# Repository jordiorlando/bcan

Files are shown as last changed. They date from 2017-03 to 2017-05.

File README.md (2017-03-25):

# bcan
### Beacon Controlled Autonomous Network

This project aims to create a semi-autonomous model train capable of detecting and avoiding obstacles. It makes use of small IR beacons placed between the rails to transmit a unique ID that can be mapped to various train functions, such as speed or lighting.

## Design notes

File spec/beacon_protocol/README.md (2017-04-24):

# Beacon IR Protocol
The beacon IR protocol is modulated with a carrier frequency of 38kHz. One bit length is defined as 960us, or roughly 36.5 oscillations of the carrier frequency. Each frame starts with a high signal for three bit lengths followed by a low signal for one bit length. The frame's data payload then begins, and has a nominal length of 16 bits. Each bit is represented using manchester encoding as per G.E. Thomas' convention. That is, a logical zero is represented by a low signal for 480us followed by a high signal for 480us, equivalent to a rising edge at the center of the bit length. A logical one is represented by a high signal for 480us followed by a low signal for 480us, equivalent to a falling edge at the center of the bit length. The frame ends with a low signal for four bit lengths, upon which a new frame may begin.

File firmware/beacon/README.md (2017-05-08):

# Beacon Firmware
This firmware is responsible for continuously broadcasting a unique ID via a modulated IR LED.

## Prerequisites
-   avr-gcc
-   avr-libc
-   avrdude

## Building
Build the firmware into an Intel hex file. The ID should be a 4-digit hexadecimal number.
```sh
$ make clean
$ make all ID=0xbcaf
```

## Flashing
Flash the Intel hex file using avrdude.
```sh
$ make program
```

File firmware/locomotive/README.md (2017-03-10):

# Locomotive Firmware
This firmware is responsible for controlling every aspect of the locomotive

## Prerequisites
- arm-none-eabi-gcc
- arm-none-eabi-newlib
- openocd

## Building
Build the firmware.
```sh
$ make
```

## Flashing
Build and flash the firmware.
```sh
$ make flash
```

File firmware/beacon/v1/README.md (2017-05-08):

# Beacon Firmware
This firmware is responsible for continuously broadcasting a unique ID via a modulated IR LED.

## Prerequisites
-   avr-gcc
-   avr-libc
-   avrdude

## One-Time Setup
Burn fuses to not divide the internal oscillator by 8. Values obtained via [Engbedded Fuse Calculator](http://www.engbedded.com/fusecalc/).
```sh
$ make fuses
```

## Building
Build the firmware into an Intel hex file. The ID should be a 4-digit hexadecimal number.
```sh
$ make clean
$ make all ID=0xbcaf
```

## Flashing
Flash the Intel hex file using avrdude.
```sh
$ make program
```

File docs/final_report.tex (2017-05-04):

%%%%%%%%%%%%%%%%%%%%%%%%%%%%%%%%%%%%%%%%%%%%%%%%%%%%%%%%%%%%%
% ECE 445 final paper LaTeX template
% Written by Zhangxiaowen (Andy) Gong
% Created: 03/07/2012
% Last modified: 03/13/2012
%%%%%%%%%%%%%%%%%%%%%%%%%%%%%%%%%%%%%%%%%%%%%%%%%%%%%%%%%%%%%
\documentclass[openbib,letterpaper,10pt]{article}

%%%%%%%%%%%%%%%%%%%%%%%%%%%%%%%%%%%%%%%%%%%%%%%%%%%%%%%%%%%%%
% The preamble starts here.
% You can add other packages that you want to use by using
% \usepackage command in the preamble.
% However, DO NOT change the settings that are already placed
% below unless you really know what you are doing.
%%%%%%%%%%%%%%%%%%%%%%%%%%%%%%%%%%%%%%%%%%%%%%%%%%%%%%%%%%%%%

% some commonly used packages
\usepackage{graphicx}
\usepackage{amsmath}
\usepackage{amsthm}
\usepackage{amsfonts}
\usepackage{setspace}
\usepackage{longtable}
\usepackage{url}
\usepackage{float}
\usepackage{caption}
\usepackage[colorlinks=true,linkcolor=black,citecolor=black]{hyperref}
\usepackage[top=1in, bottom=1in, left=1in, right=1in]{geometry}% set the page margins to 1 inch
\usepackage{siunitx}

% use the fancyhdr package to maintain the format of the page numbers,
% which is useful when the text color is changed
\usepackage{fancyhdr}
\fancyhf{}
\renewcommand{\headrulewidth}{0pt}
\renewcommand{\footrulewidth}{0pt}
\fancyfoot[C]{\textcolor{black}{\thepage}}

% paralist provides extended list environments
\usepackage{paralist}
\setlength{\plitemsep}{0pt}

% define the color for section and subsection titles
\usepackage{xcolor}
\definecolor{titlecolor}{RGB}{31,73,125}
\definecolor{subtitlecolor}{RGB}{79,129,189}

% tikz/pgf environment for making graphs
\usepackage{tikz}
\usepackage{tikz-timing}[2009/12/09]
\usetikzlibrary{shapes,arrows}
\usetikztiminglibrary[new={char=Q,reset char=R}]{counters}

% change the style of the abstract environment
\usepackage{abstract}
\setlength{\absparsep}{6pt}
\setlength{\absleftindent}{0pt}
\setlength{\absrightindent}{0pt}
\setlength{\abstitleskip}{-18pt}
\renewcommand{\absnamepos}{flushleft}
\renewcommand{\abstractnamefont}{\normalfont\Large\singlespacing\bfseries}
\renewcommand{\abstractname}{\textcolor{titlecolor}{Abstract}}

% change the style of the section and subsection titles
\usepackage{titlesec}
\titleformat{\section}{\color{titlecolor}\Large\bf}{\color{titlecolor}\thesection}{0.8em}{}
\titleformat{\subsection}{\color{subtitlecolor}\large\bf}{\color{subtitlecolor}\thesubsection}{1em}{}
\titleformat{\subsubsection}{\color{subtitlecolor}\normalsize\bf}{\color{subtitlecolor}\thesubsubsection}{1.2em}{}
\titlespacing{\section}{0pt}{0em}{0em}
\titlespacing{\subsection}{0pt}{0em}{0em}
\titlespacing{\subsubsection}{0pt}{0em}{0em}

% change the style of the table of contents
\usepackage{titletoc}
\titlecontents{section}[1.5em]{}{\contentslabel{1.5em}}{\hspace*{-1.5em}}{\titlerule*[0.5pc]{.}\contentspage}
\titlecontents{subsection}[3em]{}{\contentslabel{2.1em}}{\hspace*{-2.1em}}{\titlerule*[0.5pc]{.}\contentspage}
\titlecontents{subsubsection}[5.1em]{}{\contentslabel{2.7em}}{\hspace*{-2.7em}}{\titlerule*[0.5pc]{.}\contentspage}

% command for centering texts in a fixed width table cell
\newcommand{\centpcol}{\leftskip\fill \rightskip\fill}

% command for setting the style of the appendix titles
\newcommand{\setappenstyle}{
	\titleformat{\section}{\color{titlecolor}\Large\bf}{\color{titlecolor}Appendix \Alph{section}}{0.8em}{}
	\titlecontents{section}[0em]{}{Appendix \thecontentslabel \hspace{1em}}{}{\titlerule*[0.5pc]{.}\contentspage}
}

% define the style of the title of the paper
\newcommand{\thetitle}[1]{\title{\begin{Huge}{\bf #1}\end{Huge} \color{subtitlecolor}\rule[25pt]{\textwidth}{1pt}}}

% define the style of the author
\newcommand{\theauthor}[3]{
	\author{\vspace{0.5in}\\
	\textcolor{black}{By}\\
	#1
	\vspace{0.8in}\\
	\textcolor{black}{Final Report for ECE 445, Senior Design,} #2\\
	\textcolor{black}{TA:} #3
	\vspace{0.3in}}
}

% define the style of figure's caption
\newcommand{\figcap}[1]{
	\captionsetup{format=plain,font={small,color=subtitlecolor,singlespacing},margin={0pt,0pt}}
	\caption{\textcolor{subtitlecolor}{#1}}
	\vspace{-5pt}
}

% define the style of table's caption
\newcommand{\tablecap}[1]{
	\captionsetup{format=plain,font={bf,normalsize,singlespacing,color=black},margin={0pt,0pt}}
	\caption{\textcolor{black}{#1}}
	\vspace{-5pt}
}

% define the style of the abstract's page number
\newcommand{\abstractsetting}{
	\pagenumbering{roman}
	\thispagestyle{fancy}
}

\newcommand{\buildtoc}{
	\clearpage
	\singlespacing
	\tableofcontents
	\clearpage
	\onehalfspacing
	\setcounter{page}{1}
	\pagenumbering{arabic}
}

% set indentations and the space between paragraghs
\setlength{\parindent}{0pt}
\setlength{\parskip}{8pt}

%%%%%%%%%%%%%%%%%%%%%%%%%%%%%%%%%%%%%%%%%%%%%%%%%%%%%%%%%%%%%
% The preamble ends here.
%%%%%%%%%%%%%%%%%%%%%%%%%%%%%%%%%%%%%%%%%%%%%%%%%%%%%%%%%%%%%

\begin{document}

% don't change these
\pagestyle{empty}
\doublespacing

% put the title of your project here. DO NOT include the brackets.
\thetitle{Beacon-Controlled Autonomous Network for Trains (BCAN'T)}

% put your names here. seperate by \\. DO NOT include the brackets.
\theauthor{
	Susan Chen\\
	Prithvi Garimalla\\
	Jordi Pakey-Rodriguez
}
{ % put the semester info here. DO NOT include the brackets.
	Spring 2017
}
{ % put your TA's name here. DO NOT include the brackets.
	Jacob Bryan
}

% put the date and project number here. DO NOT include the brackets.
\date{
03 May 2017\\
Project No. 5
\clearpage
}

% don't change these
\maketitle
\pagestyle{fancy}
\begin{spacing}{1.15}

% put the abstract here
\begin{abstract}
BCAN'T is a system for model trains that consists of infrared beacons and a laser time-of-flight sensor in order to enable true “set and go” operation. Over the course of the project we developed the beacon reading system and it demonstrated it works, as well as a complete control system on the locomotive that interfaces the beacon and time-of-flight data to control to motor and other peripherals. Unfortunately, due to last minute hardware failures, we were unable to integrate all the components onto a locomotive, but most of the components were demonstrated to work on their own.
\abstractsetting % do not delete this line
\end{abstract}

% build the table of contents.
\buildtoc

\section{Introduction}
\subsection{Objective}
Model trains have become more and more advanced over the last few decades, but they are still controlled entirely by a human operator. These human operators are solely responsible for ensuring that no harm comes to the train. A lapse in attention can be disastrous, causing damage that could be very costly to repair. Model trains currently do not have the ability to detect obstacles or other trains in front of them. If not stopped in time a crash may occur, often resulting in derailment or physical damage. Additionally, derailment may occur when a train is traveling at high speeds on a curved tracks. The train has no recourse for these situations other than for the operator to manually slow or stop it to avoid an accident.\par

Currently, the National Model Railroad Association (NMRA) defines the Digital Command Control (DCC) standard for model trains. DCC allows for digital control of various train functions such as lights, speed, direction, sound, and much more\cite{NMRA_DCC}. One downside to DCC is that smooth operation is completely dependent on the human operator who must manually control the train as it is unable to react to its environment autonomously. In addition, DCC has a steep learning curve and setting up a system without prior experience can be quite challenging.\par

Our solution is to give each locomotive the ability to respond to the track on its own by detecting obstacles and reacting to programmable beacons placed on the track. A distance sensor is placed on the front of the train to detect obstacles directly in front of it. Small beacon modules placed on the track are set to send out unique identifiers to the train to let it know what speed it should travel at. Essentially, the end goal is to have the train sense potential issues along the track that would cause collision or derailment and act to avert such problems. Our solution is a convenient alternative to those who wish to have speed control for their locomotives. The sensors integrated with the locomotive also provide some measure of protection against human negligence by avoiding obstacles and preventing derailment.

\subsection{High-Level Requirements}
\begin{itemize}
	\item Must be able to operate indefinitely on existing methods of track power, both analog (DC) and bipolar Digital Command Control (DCC).
	\item Must be able to detect oncoming obstacles on the track and stop to avoid derailment or damage.
	\item Must be able to read customizable speed limit beacons that are powered by the tracks and adjust its speed accordingly.
\end{itemize}

\clearpage

\section{Design}
Our solution consists of two independent systems: the beacon boards and the locomotive controller. The beacons are small standalone boards on the track that continuously broadcast a unique ID that is read as the train passes over. The locomotive controller consists of three PCB's on the train and is responsible for reading beacons, identifying obstacles, and controlling the motor. The block diagram is shown in Figure 1.

\begin{figure}[H]
	\begin{center}
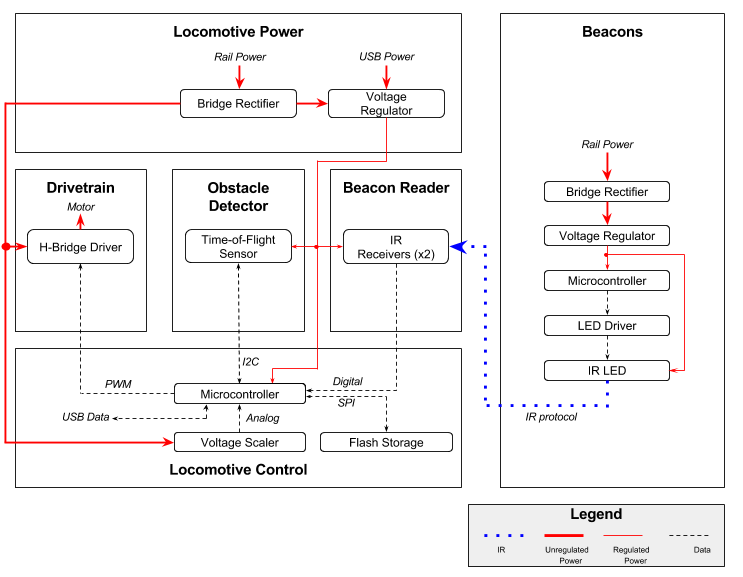
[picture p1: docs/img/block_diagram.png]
		
		\figcap{Block Diagram.}
	\end{center}
\end{figure}

\subsection{Beacon}
The beacon is small board that sits between two track ties as shown in Figure 2. The image on the left shows the placement of a beacon on the track, and the image on the right shows three individual beacons with their ID labels. Its function is to broadcast a unique ID to the IR receiver board on the locomotive. Each ID is mapped to a specific function that can be programmed on the locomotive control board. A bridge rectifier and a voltage regulator are used to provide 2.8V power to the microcontroller, LED driver, and IR LED. The microcontroller controls the IR LED to continuously broadcast the board's ID for the IR receiver on the locomotive board to read.

\begin{figure}[H]
	\begin{center}
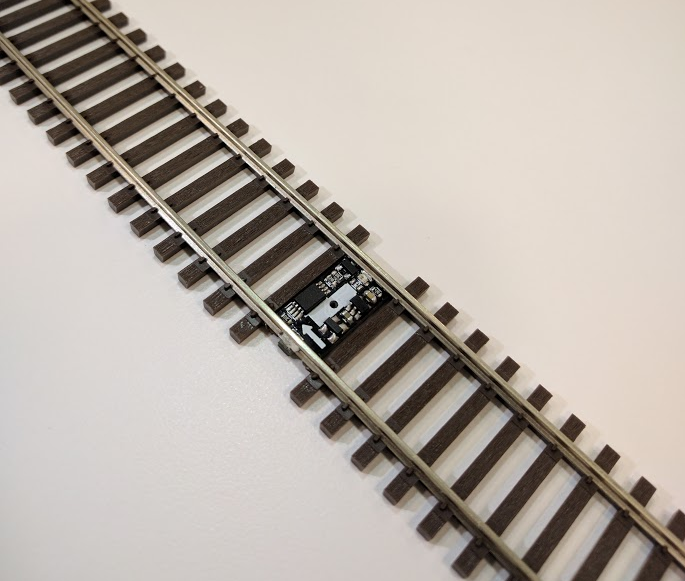
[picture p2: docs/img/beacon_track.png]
		
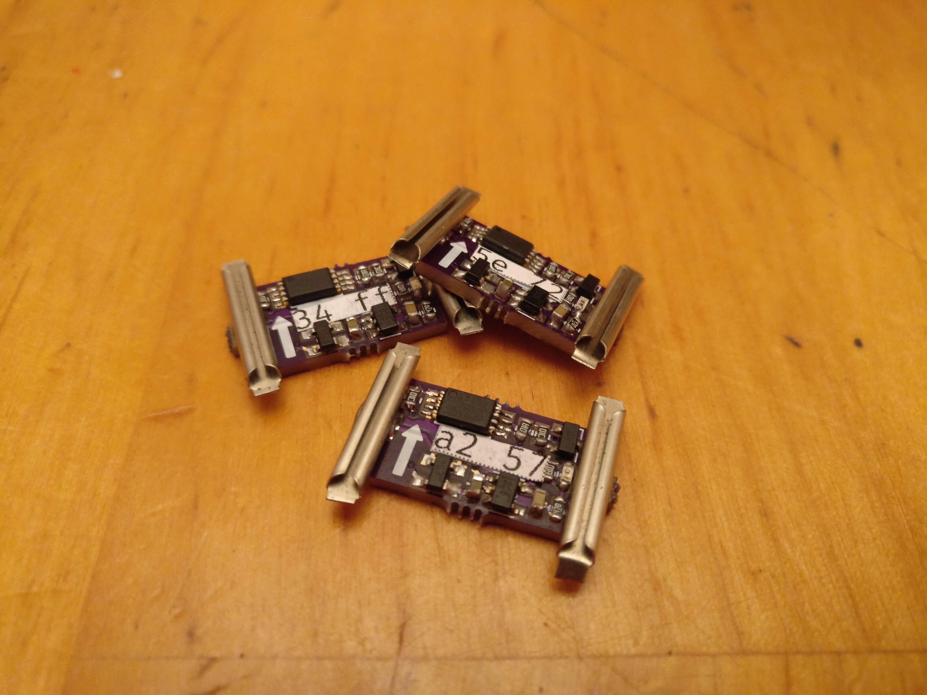
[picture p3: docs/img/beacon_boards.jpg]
		
		\figcap{Beacon Boards.}
	\end{center}
\end{figure}

\subsubsection{Schematic}
The schematics for the beacon board IR LED and power circuits are shown in Figure 3 and Figure 4, respectively. The shunt resistor R5 is used to create a clean 38kHz modulated signal since the LED is unable to switch fast enough. The calculations for R2 and R4 are shown in Calculations 1 and 2 in Appendix B.

\begin{figure}[H]
	\begin{center}
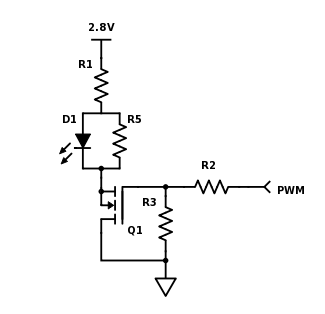
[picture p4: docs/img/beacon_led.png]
		
		\figcap{Beacon IR LED Circuit.}
	\end{center}
\end{figure}

\begin{figure}[H]
	\begin{center}
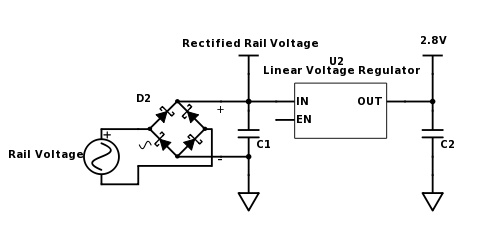
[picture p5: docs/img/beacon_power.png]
		
		\figcap{Beacon Power Circuit.}
	\end{center}
\end{figure}

\subsubsection{Bridge Rectifier}
Since the voltage regulator only takes positive voltage, the full-bridge rectifier is needed rectify the power signals from the rails. It consists of four schottky diodes in a bridge configuration and rectify rail voltages ranging from -16V to +16V.

\subsubsection{Voltage Regulator}
A linear voltage regulator takes an input from the rectified rail power and bring the voltage down to 2.8V from an input voltage of up to 16V. It provides the power needed for the MCU and its peripherals.\par

The TPS709 linear voltage regulator data sheet specifies a minimum input voltage of 2.7V\cite{TPS709}. Testing showed that an input voltage of 3.5V would produce an output voltage of 2.63V, while input voltages lower than 3.5V would produce an output voltage that is below our requirements. Therefore, a input voltage of 3.5V would be the minimum threshold for our project to function properly.

\subsubsection{Microcontroller}
The microcontroller used is an ATtiny45 8-bit AVR processor. It uses a single GPIO pin to control the LED driver circuit and continuously broadcast the board's unique ID using the IR protocol.

\subsubsection{LED Driver}
The LED driver circuit consists of an N-channel MOSFET, a gate resistor, and a pull down resistor. The MOSFET conducts current when the I/O pin from the microcontroller is set to high. The gate resistor is used to prevent damage due to overcurrent to the microcontroller and the pull down resistor is used to ensure the MOSFET is turned off when the voltage at the gate is left floating.

\subsubsection{IR LED}
The 940nm IR LED is used to broadcast a unique ID that the receiver on the locomotive can read. It is controlled by the LED driver circuit using PWM. The viewing half-angle for the LED can be calculated using Equation 1. The calculation for the viewing half angle can is shown in Calculation 3 in Appendix B.

\begin{equation}
\theta_{\frac{1}{2}}=\arctan\bigg(\frac{V_{max}T}{2H_{min}}\bigg)
\end{equation}

Vmax is the max speed of the train, T is the length of one ID message, and Hmin is the minimum distance from the beacon board LED to the IR receivers on the train.

\subsection{Locomotive Power}
The locomotive power circuit takes an input voltage ranging from -16V to +16V from the rail or 5V from the USB. It then rectifies and regulates that voltage down to 2.8V in order to power the microcontroller and its peripherals. A full bridge rectifier is used to rectify the AC voltage from the rails. The rectified voltage is then inputted to a linear voltage regulator. The SPX3918 adjustable linear voltage regulator has a minimum input voltage of 2.5V and a maximum dropout voltage of 550mV with a 500mA current draw. This means the minimum input threshold voltage in order for the locomotive components to be powered would be 3.35V, allowing for the microcontroller to be able to wait for the input voltage to reach the 3.5V minimum threshold limit for the beacon board to be powered. The circuit for the locomotive power block is shown in Figure 5.\par

Other designs were considered for the locomotive power circuit. A switching circuit to switch between the USB power source and the rail power source was considered. However, it was simpler to add a protection diode after the USB voltage source. There were also attempts to regulate the input voltage through the full range of rail voltages with switching circuits, switch-mode power supplies, or batteries. The switching circuits were complex and risked shorting the input and output voltages if the timing was not correct. There were no switch-mode power supplies on the market that had a low enough input voltage for the output that was required. Batteries would have defeated the purpose of drawing power from a wall outlet.

\subsubsection{Schematic}
\begin{figure}[H]
	\begin{center}
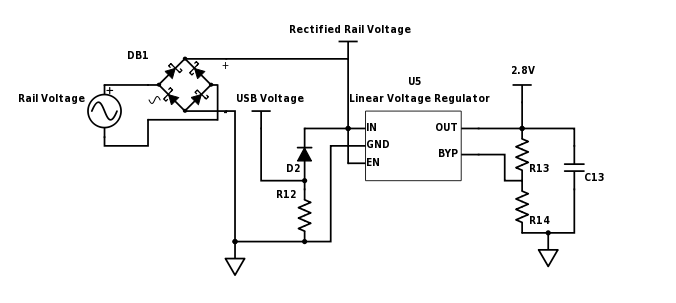
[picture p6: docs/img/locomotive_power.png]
		
		\figcap{Locomotive Power Schematic.}
	\end{center}
\end{figure}

\subsubsection{Bridge Rectifier}
The full-bridge rectifier is needed to rectify power signals from the rails before they are routed to the voltage regulator, voltage scaler, and motor driver. It consists of four schottky diodes in a bridge configuration and rectifies voltages ranging from -16V to +16V.

\subsubsection{Voltage Regulator}
The rectified voltage is fed into a linear voltage regulator in order to bring the voltage down to 2.8V. The 2.8V source is used to power the microcontroller, time-of-flight sensor, IR receiver, and the voltage scale circuit. Calculation 4 in appendix B shows how the adjustment resistors are calculated for the SPX3819 linear regulator for an output voltage of 2.8V using Equation 2.

\begin{equation}
V_{out}=1.235(1+\frac{R_1}{R_2})
\end{equation}

\subsection{Locomotive Control}
The locomotive control unit consists of a microcontroller and a USB data connection. If there is a USB connection the control unit will enter a programming mode, otherwise it will run the normal track operation. This allows operators to map the beacon IDs to one of 128 different speeds\cite{NMRA_Standard}. The microcontroller receives a voltage input via the ADC pin from the voltage scale circuit and outputs a PWM signal to the drivetrain to control the speed. The IR receiver sends beacon IDs to the microcontroller in order to determine what speed the train should go. It also stops the train if the time-of-flight sensor detects an obstacle in its path.

\subsubsection{Schematic}
The main part of the control circuit is the STM32F4 microcontroller. It is connected to a M95512-RDW6TP EEPROM for storage of the beacon mappings. The control schematic is shown in Figure 6.

\begin{figure}[H]
	\begin{center}
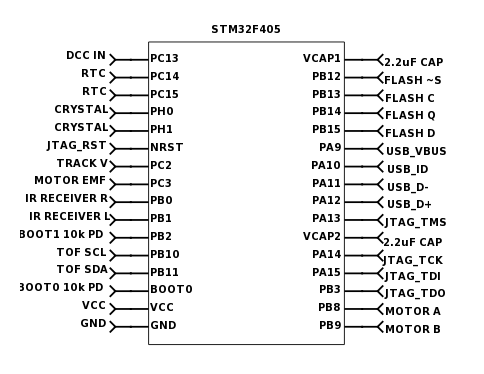
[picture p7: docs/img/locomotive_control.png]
		
		\figcap{Locomotive Control Schematic.}
	\end{center}
\end{figure}

\subsubsection{Microcontroller}
The microcontroller used is an STM32F405 32-bit ARM processor. It communicates with the time-of-flight sensor via I2C, the IR receiver digitally, and control the motor with PWM signals. It also stores configuration data for the beacons in external memory.

\subsubsection{Flash Storage}
An EEPROM flash chip is used to store the beacon mappings. It communicates with the microcontroller over SPI. EEPROM was chosen since we can address individual bytes, which makes performing binary search through the dataset for the beacon mappings more efficient.

\subsubsection{Voltage Scaler}
The voltage scaler circuit originally included an operational amplifier buffer to improve the accuracy of the voltage readings. However, we were unable to find an operation amplifier that could be powered by a 2.8V source, so errors were corrected in software instead. The voltage scaler circuit consists of a resistive voltage divider, shown in Figure 7, that scales the rectified rail voltage down to a lower voltage that can be read by the microcontroller's ADC. The rectified rail voltage ranges from 0-16V and the microcontroller ADC can read voltages from 0-2.8V. Two resistors divide the voltage to output a range of 0-2.8V, which will give 4096 different values for a 12-bit precision ADC. The calculations using Equation 3 of the voltage divider's resistor values are shown in Calculation 5 in appendix B.

\begin{figure}[H]
	\begin{center}
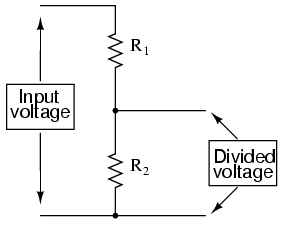
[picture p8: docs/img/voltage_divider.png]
		
		\figcap{Voltage Divider Circuit.}
	\end{center}
\end{figure}

\begin{equation}
V_{out}=V_{in}\frac{R_2}{R_1+R_2}
\end{equation}

\subsection{Locomotive Drivetrain}
The locomotive drivetrain unit consists of the motor controller circuit that interfaces the PWM signal from the microcontroller with the rectified rail power in order to power the motor. The circuit consists of a MOSFET H-bridge that is gate-driven by NPN transistors. The drivetrain circuit is shown in Figure 8.\par

In order to drive the MOSFETs in the H-bridge, optoisolators were also considered. However, we were unable to find an optoisolator that would support driving the LED with our maximum rectified rail voltage.

\subsubsection{Schematic}
\begin{figure}[H]
	\begin{center}
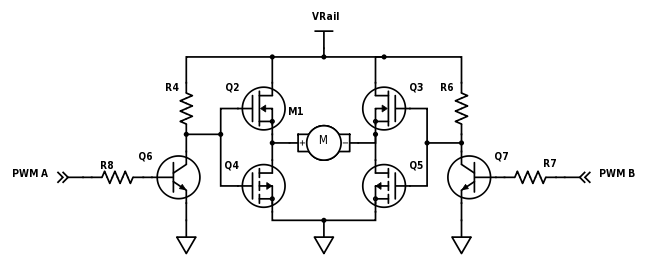
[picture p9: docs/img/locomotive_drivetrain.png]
		
		\figcap{Locomotive Drivetrain Schematic.}
	\end{center}
\end{figure}

\subsubsection{Motor Controller}
The motor driver circuit consists of two PWM signals driving two NPN transistors which each control an NFET and a PFET. The MOSFETs are configured as an H-bridge and allow the motor to run forwards or backwards at any speed determined by the PWM signals. The frequency of the PWM signals is 10kHz to prevent resonance and noise. The motor current range is $\pm$1.5A and the motor voltage range is $\pm$16V.

\subsection{Obstacle Detector}
The obstacle detector consists of a time of flight (TOF) sensor mounted to the front of the train. It detects any obstruction on the tracks that could cause the train to derail and cause an emergency stop. The TOF sensor uses a laser to measure whether the path in front of the train is clear or if the train is approaching an unexpected obstacle. The range of the TOF sensor is approximately 50-200mm\cite{VL6180X}.

\subsection{Beacon Reader}
The beacon reader consists of two IR receivers mounted underneath the train on either side. They read beacons as the train passes over them. With two receivers, the microcontroller can infer the direction the train is moving and execute different actions accordingly.

\subsection{IR Protocol}
The IR protocol uses 38kHz modulation present in many televisions and other consumer devices. We chose this frequency because sensors for it are widely available. Our protocol uses Manchester encoding according to the G.E. Thomas convention with a bit period of 960s and data length of 16 bits\cite{Manchester}. The timing diagram for the protocol is shown in Figure 9.

\begin{figure}[H]
	\begin{center}
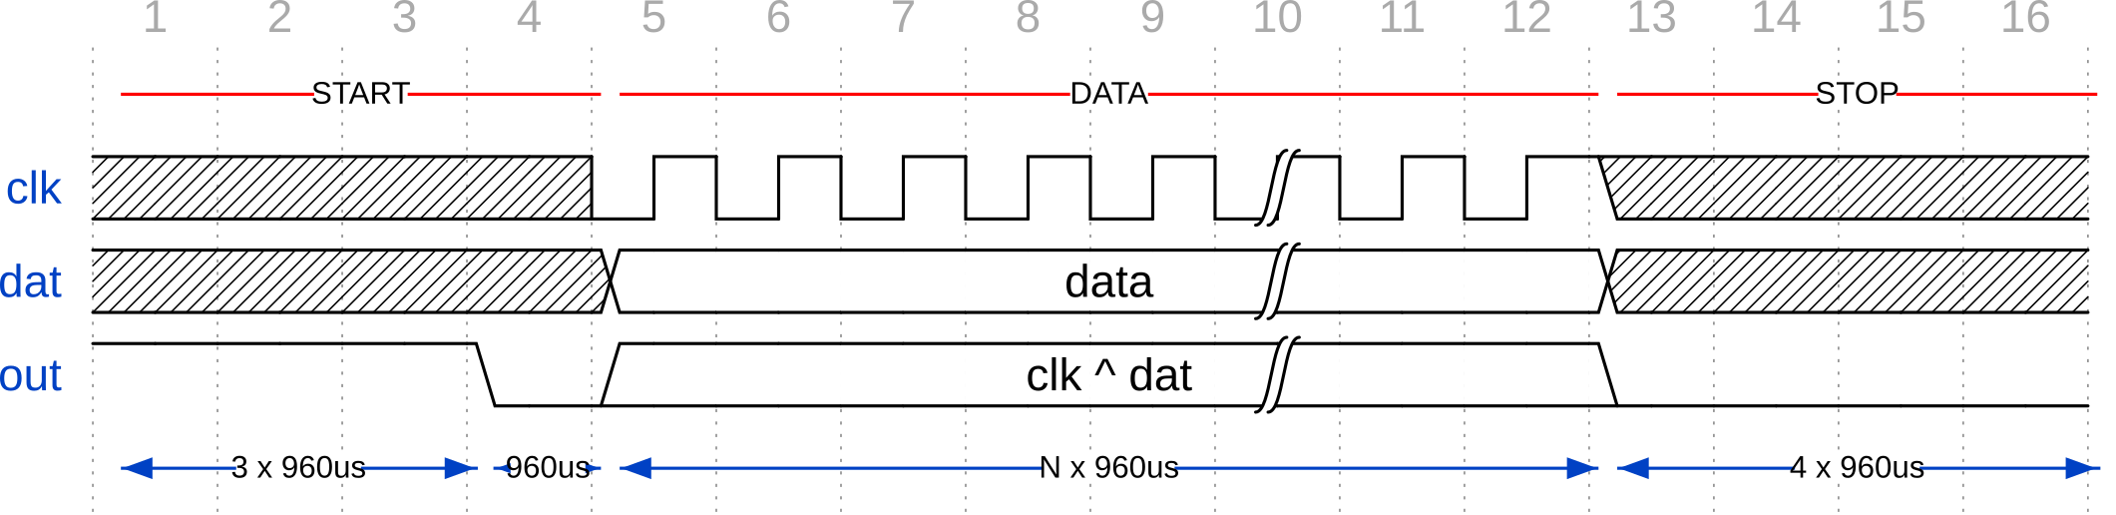
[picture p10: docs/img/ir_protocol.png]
		
		\figcap{IR Protocol Timing Diagram.}
	\end{center}
\end{figure}

\subsection{Beacon Firmware}
The beacon firmware is a simple loop that continuously broadcasts the beacon ID using the IR protocol. Every 480us it determines what the next edge is (rising or falling) and sets the GPIO pin accordingly.

\subsection{Locomotive Firmware}
The locomotive has two modes of operation: track mode and programming mode. It also reacts to pin change interrupts from the IR receiver. At boot, the microcontroller checks to see if USB is connected. If so, it enters programming mode and presents itself as a USB mass storage device. When the user starts to write a configuration file to the locomotive, the microcontroller will buffer each beacon mapping and verify they are being written in ascending order. This is required since at look-up time, it will perform a binary search through the mappings to find the correct one. If an errored mapping comes in, the microcontroller will stop storing more mappings.\par

In track mode, the microcontroller will continuously check the obstacle detector, stopping the train if there is one. Then it checks whether a beacon ID is read and looks up the appropriate mapping before executing it. Finally, it makes any motor adjustments as necessary.\par

The IR receiver also works by invoking a pin change interrupt every time its value changes. Using our IR protocol and taking advantage the repetitive pattern of the data we are sending, we need only store one message length worth of pin changes to calculate the beacon ID. When we have the requisite data, we set a “ready flag” which will trigger the main event loop to look up and execute the mapping.

\subsubsection{Feature List}
\begin{itemize}
	\item Mount as USB mass storage device if USB plugged on boot
	\item Stores the beacon mappings on flash memory
	\item Reads beacons through pin change interrupts
	\item Can stop the train if an obstacle is detected
	\item Can continuously adjust the motor speed and direction based on track conditions
\end{itemize}

\subsubsection{Flow Chart}
The flowchart for the locomotive operation is is shown in Figure 10.

\begin{figure}[H]
	\begin{center}
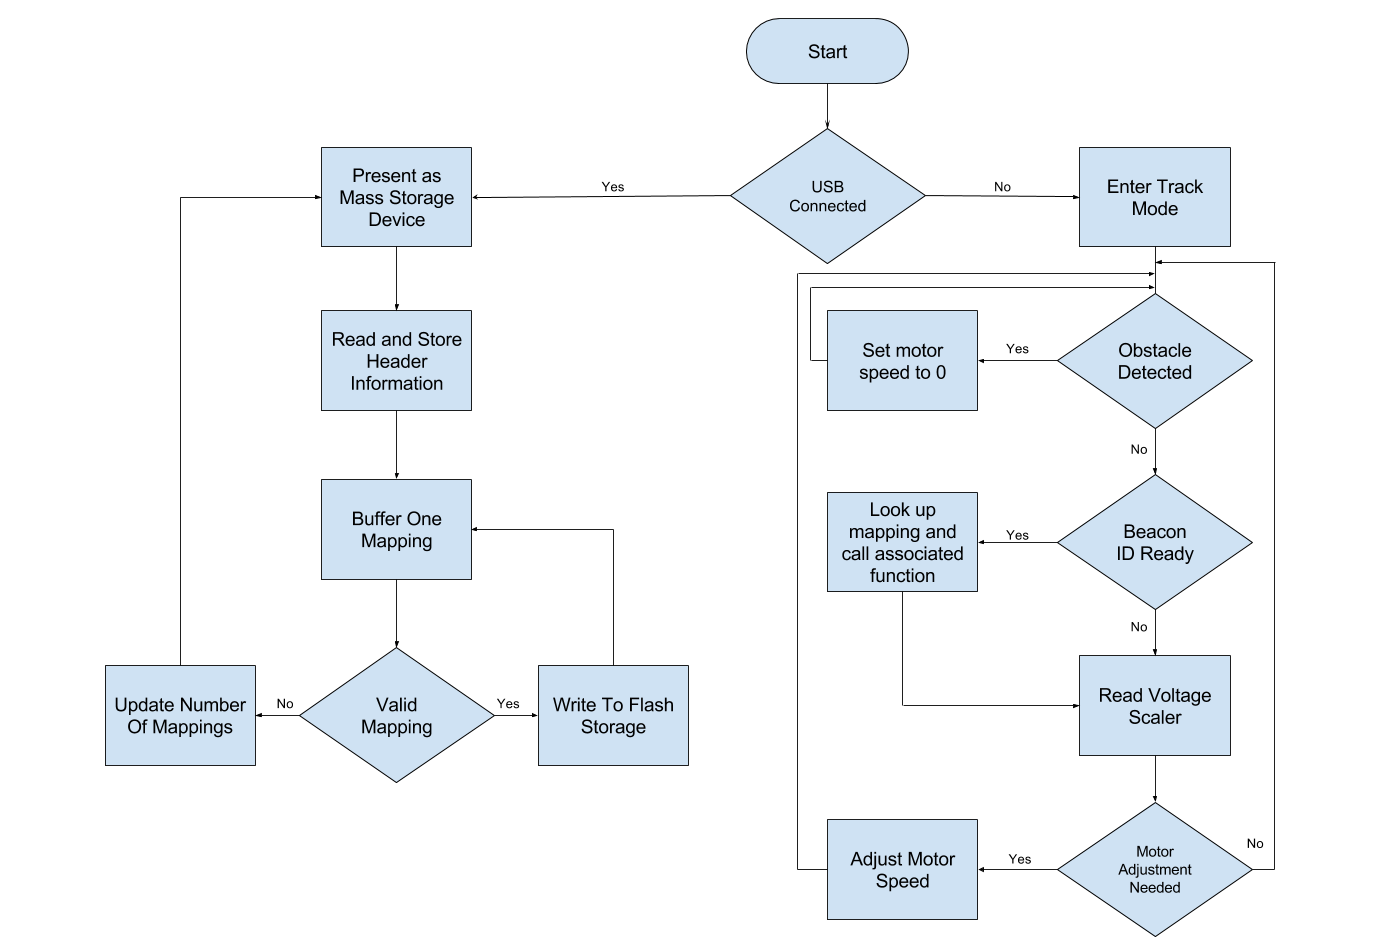
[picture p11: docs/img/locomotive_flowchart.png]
		
		\figcap{Locomotive Firmware Control Flow.}
	\end{center}
\end{figure}

\subsection{PC Software}
Figure 11 shows the web interface (hosted online \href{http://jordi.codes/bcan}{here}) to program the beacons. Once specifying the ID, the user can select the instances where the mapping applies and the action the beacon corresponds to.
\begin{itemize}
	\item Allows user to add any number of beacon mappings
	\item Each mapping consists of a beacon ID, description, direction of travel, direction of drain, function, and additional parameters for that function
	\item Clicking “Save” downloads a file that can be copied to the USB mass storage device to program the mappings
\end{itemize}

\begin{figure}[H]
	\begin{center}
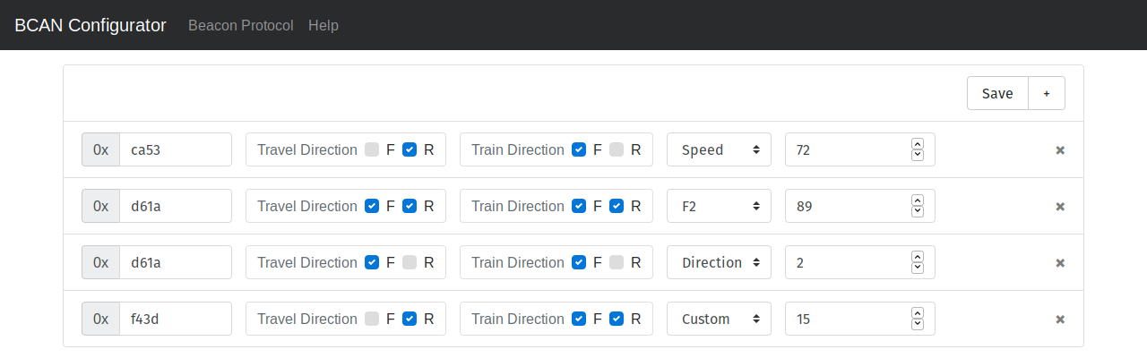
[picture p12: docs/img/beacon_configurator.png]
		
		\figcap{Beacon Configurator Website.}
	\end{center}
\end{figure}

\clearpage

\section{Cost}
In order to keep costs low, we chose a locomotive microcontroller that can be switched out with a cheaper one in case the user did not require as many peripherals. We also kept the locomotive board limited to 2 layers as a 4 layer board would have significantly increased the price. On the beacon side, we kept the BOM to under \$5 in single quantities, and have already designed a v2.0 with a cheaper microcontroller that has a \$1 BOM at quantity 1000.

\subsection{Labor}
\begin{center}
\begin{longtable}{|c|c|r|r|r|}
\tablecap{Labor Costs}
		\\
		\hline \multicolumn{1}{|p{10em}|}{\centpcol\textbf{Name}} & \multicolumn{1}{p{10em}|}{\centpcol\textbf{Total Hours}} & \multicolumn{1}{p{7em}|}{\centpcol\textbf{Hourly Rate (\$)}} & \multicolumn{1}{p{7em}|}{\centpcol\textbf{Total (\$)}} & \multicolumn{1}{p{7em}|}{\centpcol\textbf{Total * 2.5 (\$)}}\\ \hline
		\endfirsthead

		\multicolumn{5}{c}
		{{\bfseries \tablename\ \thetable{} -- continued from previous page}} \\
		\hline \multicolumn{1}{|p{10em}|}{\centpcol\textbf{Name}} & \multicolumn{1}{p{10em}|}{\centpcol\textbf{Total Hours}} & \multicolumn{1}{p{7em}|}{\centpcol\textbf{Hourly Rate (\$)}} & \multicolumn{1}{p{7em}|}{\centpcol\textbf{Total (\$)}} & \multicolumn{1}{p{7em}|}{\centpcol\textbf{Total * 2.5 (\$)}}\\ \hline
		\endhead

		\hline \multicolumn{5}{|r|}{{Continued on next page}} \\ \hline
		\endfoot
		\endlastfoot
			Susan Chen & 170 & 36.00 & 6,120.00 & 15,300.00 \\ \hline
			Prithvi Garimalla & 170 & 36.00 & 6,120.00 & 15,300.00 \\ \hline
			Jordi Pakey-Rodriguez & 170 & 36.00 & 6,120.00 & 15,300.00 \\ \hline
			\textbf{Total} & 510 & 108.00 & 18,360.00 & 45,900.00 \\ \hline
	\end{longtable}
\end{center}

\subsection{Parts}
We spent \$200 on parts which, combined with our \$45,900 labor costs, gives a total project cost of \$46,100.

\clearpage

\section{Conclusion}

\subsection{Accomplishments}
While our project definitely had some issues that kept it from being a complete success, the most critical and innovative part, beacon reading, worked. It was demonstrated to be versatile and the speed at which the IDs could be read exceeded our expectations. Furthermore, we designed the project to be as economical as possible, so the total cost of the materials for a beacon was quite cheap. Should there be demand for this product in the model train community, we believe there would be a legitimate path to market.
% \vspace{0.2in}

\subsection{Uncertainties}
We still have a few lingering questions about our project, namely the nature of the eleventh hour failure we experienced. We had soldered the locomotive board and it had been working for two weeks until a short developed two days before the final demo. After thinking we had identified the cause and replaced the suspect component, another short, this time at the output of the 2.8V voltage regulator appeared. This was approximately 18 hours before our final demo and the only solution we saw was to solder together another board. Unfortunately, even though this board had never even been powered, the short was still present. Even after thoroughly examining the board under a microscope, the only theory we have for the second board being faulty is a faulty component. At this point, even though we were able to demonstrate the individual aspects of the project worked, integrating them was not successful.
% \vspace{0.2in}

\subsection{Ethical Considerations}
There are two potential safety concerns with our project, however we believe they are both within the acceptable tolerances for a general consumer product. The first of these is that the rails of the train track are electrically charged so one could potentially shock themselves. However, we are not changing this characteristic in our design and therefore are not creating any additional safety hazards. This is a well understood risk of model trains so responsible usage dictates they should be kept out of reach of small children or pets. The second is that we are using a time-of-flight sensor that uses a laser. The laser used is Class 1, which means that it is safe for use under normal conditions and while operating within the manufacturer's specifications\cite{VL6180X}.\par

In accordance with the IEEE code of ethics, we endeavored to take on technical tasks we feel we are qualified for and seek advice from our mentors for the skills we lack. We sought feedback and criticism for our work and continuously worked to correct our mistakes. We strove for honesty and properly credited individual contributions to our project. Most importantly, we supported and encouraged each other to follow this code of ethics.
% \vspace{0.2in}

\subsection{Future work}
The software, firmware, and schematics for our project are fully open source and there is no reason why the work on our project has to stop here. Our design choices and decisions are well documented, so should anyone choose to continue our work, they can easily pick up where we left off. We have already designed a v2.0 beacon, and have made a list of changes for the next locomotive version.
% \vspace{0.2in}

\clearpage

\bibliographystyle{IEEE_ECE}
% include the BibTex file here to build reference
\bibliography{final_report}\addcontentsline{toc}{section}{Reference}

\clearpage
\setappenstyle
\begin{appendix}
\section{Requirement and Verification Tables}

\begin{singlespacing}
\begin{center}
\begin{longtable}{|p{18em}|p{18em}|p{5em}|}
\tablecap{Beacon Requirements and Verifications}
		\\
		\hline \multicolumn{1}{|p{18em}|}{\centpcol Requirement} & \multicolumn{1}{p{18em}|}{\centpcol Verification} & \multicolumn{1}{p{5em}|}{\centpcol Verification status (Y or N)}\\ \hline
		\endfirsthead

		\multicolumn{3}{c}
		{{\bfseries \tablename\ \thetable{} -- continued from previous page}} \\
		\hline \multicolumn{1}{|p{18em}|}{\centpcol Requirement} & \multicolumn{1}{p{18em}|}{\centpcol Verification} & \multicolumn{1}{p{5em}|}{\centpcol Verification status (Y or N)}\\ \hline
		\endhead

		\hline \multicolumn{3}{|r|}{{Continued on next page}} \\ \hline
		\endfoot
		\endlastfoot
			\begin{compactenum}
				\item Must be able to be powered from rail power with a voltage range of $\pm$16V and be able to draw a minimum of 60mA.
			\end{compactenum}
			&
			\begin{compactenum}
				\item Connect the board to a bench power supply set at +16V. Verify the LED is lit using a camera. Repeat with -16V.
			\end{compactenum}
			& \\ \hline

			\begin{compactenum}
				\item Must be able to modulate the LED between 38kHz - 40kHz.
			\end{compactenum}
			&
			\begin{compactenum}
				\item Connect IR receiver output to an oscilloscope and point it at the IR LED\cite{TSOP572}. Verify that the signal is received.
			\end{compactenum}
			& \\ \hline

			\begin{compactenum}
				\item Must have a view angle given by Equation 1 on the axis parallel to the track.
			\end{compactenum}
			&
			\begin{compactenum}
				\item With the datasheet value for $\theta$ and the distance H, solve for VT. Place the receiver at a horizontal distance VT / 2 and a height H from the LED and verify with the oscilloscope that the ID is read.
			\end{compactenum}
			& \\ \hline

	\end{longtable}

\begin{longtable}{|p{18em}|p{18em}|p{5em}|}
\tablecap{Locomotive Power Requirements and Verifications}
		\\
		\hline \multicolumn{1}{|p{18em}|}{\centpcol Requirement} & \multicolumn{1}{p{18em}|}{\centpcol Verification} & \multicolumn{1}{p{5em}|}{\centpcol Verification status (Y or N)}\\ \hline
		\endfirsthead

		\multicolumn{3}{c}
		{{\bfseries \tablename\ \thetable{} -- continued from previous page}} \\
		\hline \multicolumn{1}{|p{18em}|}{\centpcol Requirement} & \multicolumn{1}{p{18em}|}{\centpcol Verification} & \multicolumn{1}{p{5em}|}{\centpcol Verification status (Y or N)}\\ \hline
		\endhead

		\hline \multicolumn{3}{|r|}{{Continued on next page}} \\ \hline
		\endfoot
		\endlastfoot
			\begin{compactenum}
				\item Must be able to accept voltages of 3.35 to 16V or -3.35 to -16V from the rail supply and output a rectified rail power of 2.8$\pm$0.2V and supply up to 280mA.
			\end{compactenum}
			&
			\begin{compactenum}
				\item Connect the locomotive to maximum rail power, verify the 2.8V output is active with a multimeter. Reverse the orientation of the train on the track and verify the 2.8V output again. Then put a 10Ω 1 Watt resistor across the 2.8V output and measure the current.
			\end{compactenum}
			& \\ \hline

			\begin{compactenum}
				\item Must be able to accept power from the USB supply and output 2.8$\pm$0.2V power and supply up to 280mA.
			\end{compactenum}
			&
			\begin{compactenum}
				\item Remove the train from the track and connect USB power. Verify the 2.8V output is active with a multimeter. Then put a 10Ω1 Watt resistor across the 2.8V output and measure the current.
			\end{compactenum}
			& \\ \hline

	\end{longtable}

\begin{longtable}{|p{18em}|p{18em}|p{5em}|}
\tablecap{Locomotive Control Requirements and Verifications}
		\\
		\hline \multicolumn{1}{|p{18em}|}{\centpcol Requirement} & \multicolumn{1}{p{18em}|}{\centpcol Verification} & \multicolumn{1}{p{5em}|}{\centpcol Verification status (Y or N)}\\ \hline
		\endfirsthead

		\multicolumn{3}{c}
		{{\bfseries \tablename\ \thetable{} -- continued from previous page}} \\
		\hline \multicolumn{1}{|p{18em}|}{\centpcol Requirement} & \multicolumn{1}{p{18em}|}{\centpcol Verification} & \multicolumn{1}{p{5em}|}{\centpcol Verification status (Y or N)}\\ \hline
		\endhead

		\hline \multicolumn{3}{|r|}{{Continued on next page}} \\ \hline
		\endfoot
		\endlastfoot
			\begin{compactenum}
				\item Must be able to act as a USB Mass storage device when connected to a PC.
			\end{compactenum}
			&
			\begin{compactenum}
				\item With the final microcontroller firmware, connect it to a PC to put it into programming mode. Copy a valid mapping file to the Mass Storage Device the microcontroller presents itself as. Then without unplugging the microcontroller, verify the file can be read.
			\end{compactenum}
			& \\ \hline

			\begin{compactenum}
				\item Must be able to store beacon ID mappings when not powered externally.
			\end{compactenum}
			&
			\begin{compactenum}
				\item Repeat Verification 1, with the beacon mappings set between two IDs for which there are physical beacons that correspond to turning the lights on and the turning the lights off. Then unplug and reconnect the USB. Power the beacons, then hold the locomotive over the beacons and verify the correct actions occur.
			\end{compactenum}
			& \\ \hline

			\begin{compactenum}
				\item Must be able to scale a voltage range of 0-16V down to 0-2.8V and be read by the microcontroller's ADC with at least 10 bit precision.
			\end{compactenum}
			&
			\begin{compactenum}
				\item Write and flash a test program that displays the current current ADC reading over the serial connection to the computer. Power the board over USB while connecting the rail power input to a bench power supply and sweep between 0V-27V and ensure the microcontroller is accurately displaying at least 128 distinct speed steps.
			\end{compactenum}
			& \\ \hline

	\end{longtable}

\begin{longtable}{|p{18em}|p{18em}|p{5em}|}
\tablecap{Locomotive Drivetrain Requirements and Verifications}
		\\
		\hline \multicolumn{1}{|p{18em}|}{\centpcol Requirement} & \multicolumn{1}{p{18em}|}{\centpcol Verification} & \multicolumn{1}{p{5em}|}{\centpcol Verification status (Y or N)}\\ \hline
		\endfirsthead

		\multicolumn{3}{c}
		{{\bfseries \tablename\ \thetable{} -- continued from previous page}} \\
		\hline \multicolumn{1}{|p{18em}|}{\centpcol Requirement} & \multicolumn{1}{p{18em}|}{\centpcol Verification} & \multicolumn{1}{p{5em}|}{\centpcol Verification status (Y or N)}\\ \hline
		\endhead

		\hline \multicolumn{3}{|r|}{{Continued on next page}} \\ \hline
		\endfoot
		\endlastfoot
			\begin{compactenum}
				\item Must be able to take a PWM signal from the microcontroller and control the motor accordingly.
			\end{compactenum}
			&
			\begin{compactenum}
				\item Write and flash a test program to the locomotive microcontroller that will cycle through 0\%, 25\%, 50\%, 75\%, and 100\% duty cycles on the PWM line. Verify the output of the motor controller with an oscilloscope.
			\end{compactenum}
			& \\ \hline

	\end{longtable}

\begin{longtable}{|p{18em}|p{18em}|p{5em}|}
\tablecap{Obstacle Detector Requirements and Verifications}
		\\
		\hline \multicolumn{1}{|p{18em}|}{\centpcol Requirement} & \multicolumn{1}{p{18em}|}{\centpcol Verification} & \multicolumn{1}{p{5em}|}{\centpcol Verification status (Y or N)}\\ \hline
		\endfirsthead

		\multicolumn{3}{c}
		{{\bfseries \tablename\ \thetable{} -- continued from previous page}} \\
		\hline \multicolumn{1}{|p{18em}|}{\centpcol Requirement} & \multicolumn{1}{p{18em}|}{\centpcol Verification} & \multicolumn{1}{p{5em}|}{\centpcol Verification status (Y or N)}\\ \hline
		\endhead

		\hline \multicolumn{3}{|r|}{{Continued on next page}} \\ \hline
		\endfoot
		\endlastfoot
			\begin{compactenum}
				\item Must detect obstacles at least 50mm in front of the train.
			\end{compactenum}
			&
			\begin{compactenum}
				\item Write and flash a test program to the microcontroller that will display over the PC serial connection the values read from the sensor. Place an object at a distance of 50mm in front of the sensor and 8.25mm off the center axis of the train and perpendicular to the track. Move to 8.25mm off the center axis in the opposite direction. Verify both times the object is detected.
			\end{compactenum}
			& \\ \hline

	\end{longtable}

\begin{longtable}{|p{18em}|p{18em}|p{5em}|}
\tablecap{Beacon Reader Requirements and Verifications}
		\\
		\hline \multicolumn{1}{|p{18em}|}{\centpcol Requirement} & \multicolumn{1}{p{18em}|}{\centpcol Verification} & \multicolumn{1}{p{5em}|}{\centpcol Verification status (Y or N)}\\ \hline
		\endfirsthead

		\multicolumn{3}{c}
		{{\bfseries \tablename\ \thetable{} -- continued from previous page}} \\
		\hline \multicolumn{1}{|p{18em}|}{\centpcol Requirement} & \multicolumn{1}{p{18em}|}{\centpcol Verification} & \multicolumn{1}{p{5em}|}{\centpcol Verification status (Y or N)}\\ \hline
		\endhead

		\hline \multicolumn{3}{|r|}{{Continued on next page}} \\ \hline
		\endfoot
		\endlastfoot
			\begin{compactenum}
				\item Must be able to sense a 38kHz modulated IR beam and output a demodulated digital signal.
			\end{compactenum}
			&
			\begin{compactenum}
				\item Connect a beacon to rail power. Write and flash a test program that will display over the PC serial connection the value read from the IR receiver. Verify that the value read matches the beacon's ID.
			\end{compactenum}
			& \\ \hline

	\end{longtable}
\end{center}
\end{singlespacing}

\clearpage

\section{Calculations}

\subsection{Beacon MOSFET Gate Resistor}
Ohm's Law: $R=\frac{V}{I}$ \\
I/O input voltage: $V_o=2.8V$ \\
Max current per I/O pin: $40mA$ \\
Choose $I_1=28mA$ \\
$R_1=\frac{2.8}{0.028}=100\Omega$

\subsection{Beacon LED Current-Limiting Resistor}
Forward voltage of IR LED: $V_f=1.2V$ \\
Supply voltage: $V_d=2.8V$ \\
Continuous DC current: $I_3=34mA$ \\
Using Ohm's Law: \\
$I_3=\frac{V_d-V_f}{R_3}=\frac{2.8-1.2}{R_3}=34mA$ \\
$R_3=47\Omega$

\subsection{Beacon LED Half Viewing Angle}
$V_{max}=1\frac{m}{s}$ \\
$T=23.04ms$ \\
$H_{min}= 6mm$ \\
$\theta_{\frac{1}{2}}=arctan(\frac{V_{max}T}{2H_{min}})=arctan(\frac{0.02304}{0.006})=\SI{75.4}{\degree}$

\subsection{Locomotive Voltage Regulator Resistors}
$V_{out}=1.235(1+\frac{R_1}{R_2})$ \\
$R_1=33.2k\Omega$ \\
$R_2=26.1k\Omega$

\subsection{Locomotive Voltage Scaler Resistors}
$V_{out}=V_{in}\frac{R_2}{R_1+R_2}$ \\
$V_{in,max}=16V$ \\
$V_{out,max}=2.8V$ \\
$R_1=13.3k\Omega$ \\
$R_2=2.8k\Omega$

\clearpage

\section{Schematics}

\subsection{Beacon}
\begin{center}
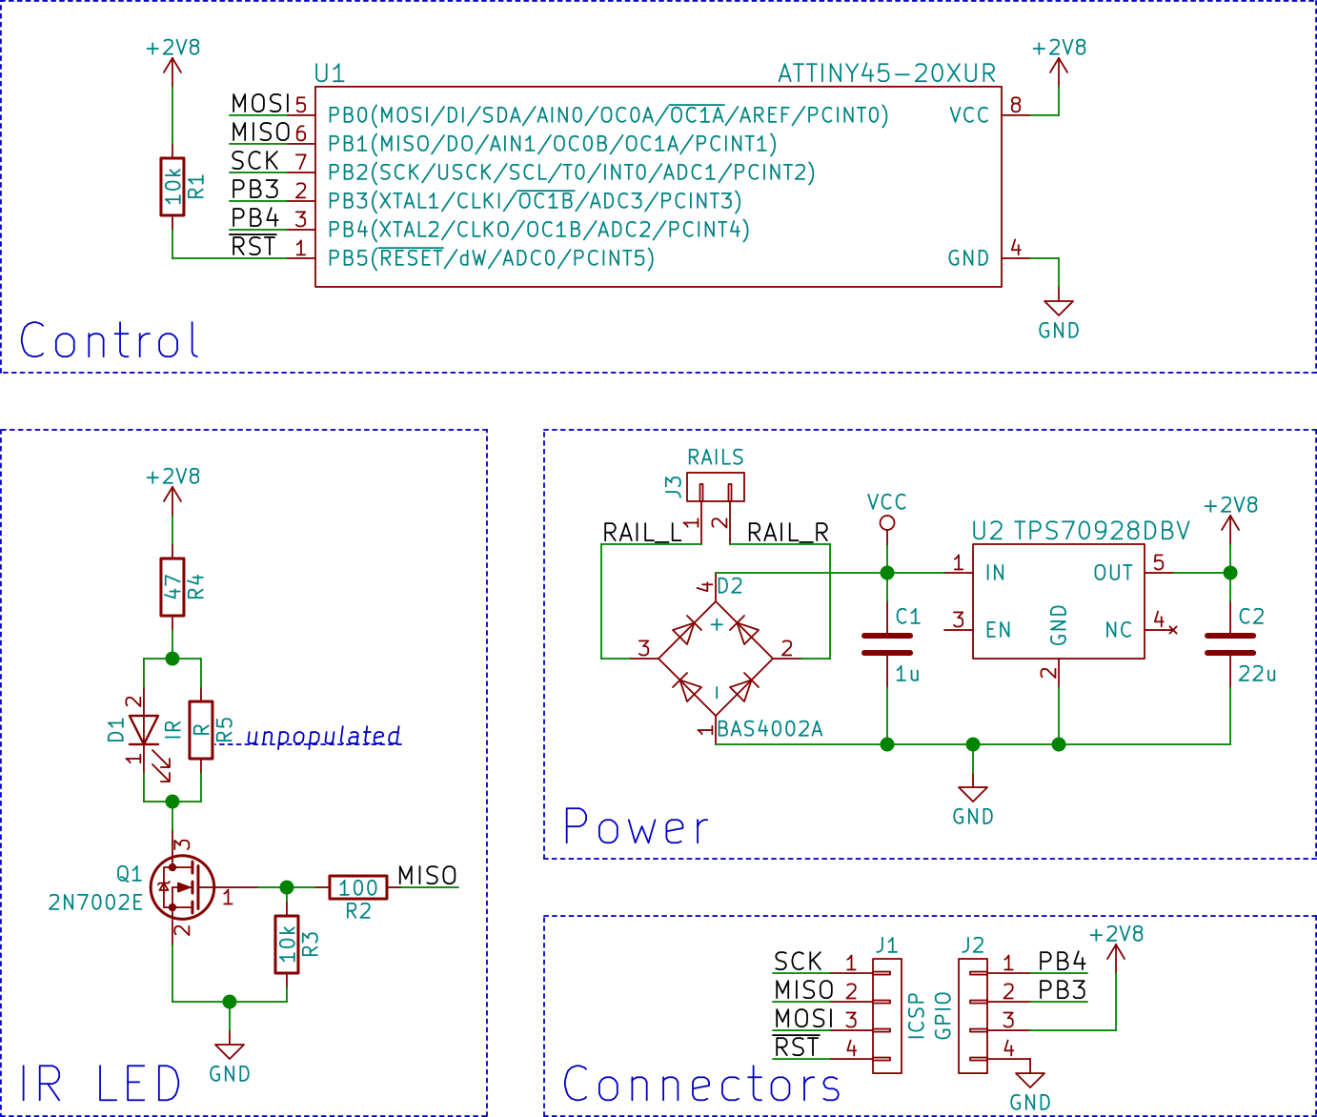
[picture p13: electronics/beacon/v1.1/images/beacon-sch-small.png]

\end{center}

\subsection{Locomotive}
\begin{center}
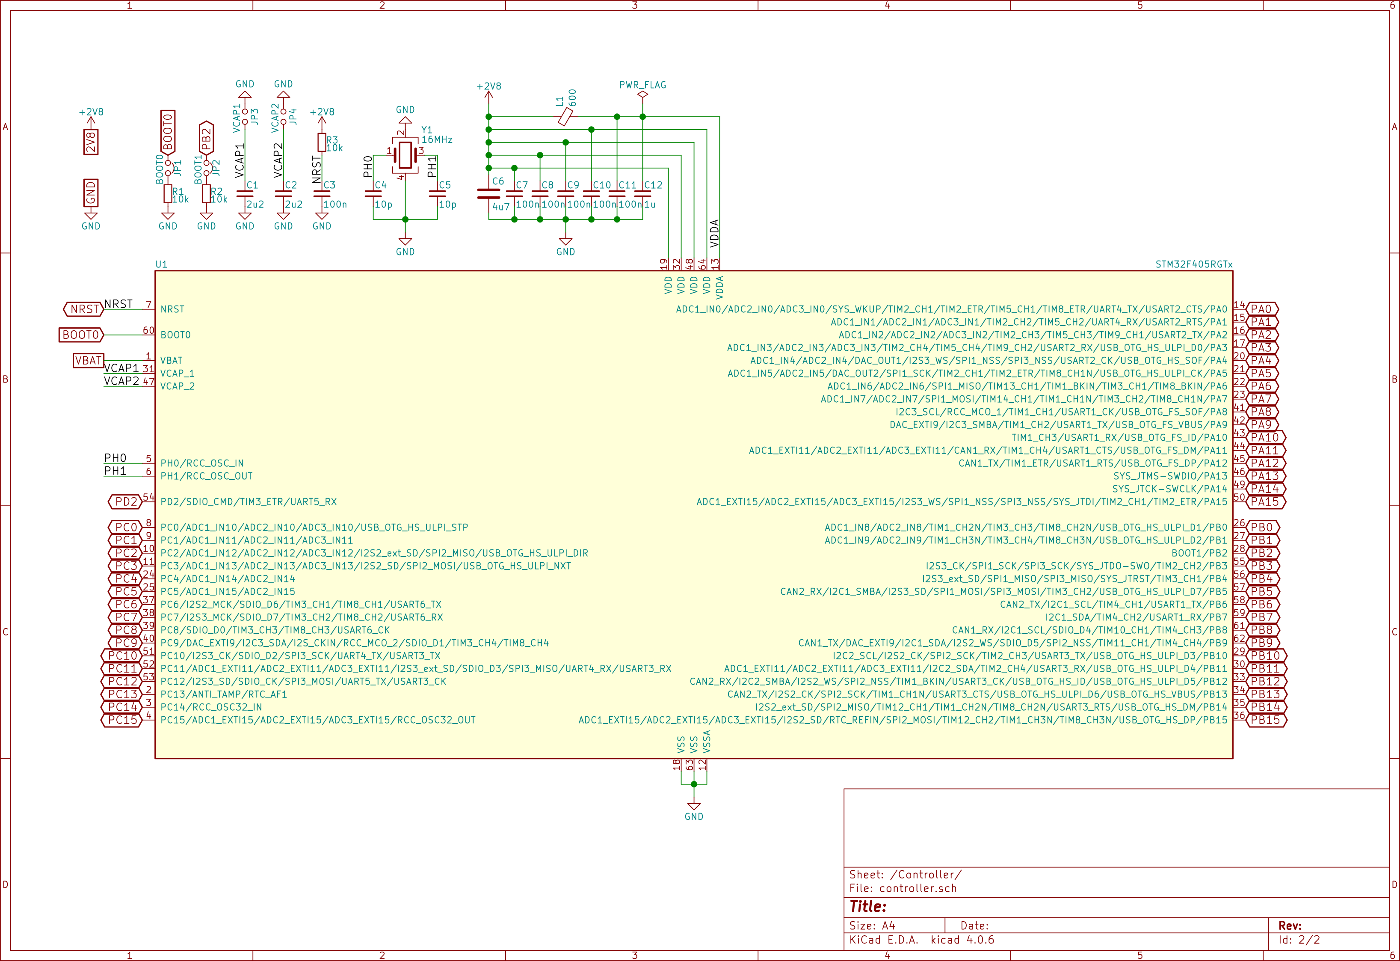
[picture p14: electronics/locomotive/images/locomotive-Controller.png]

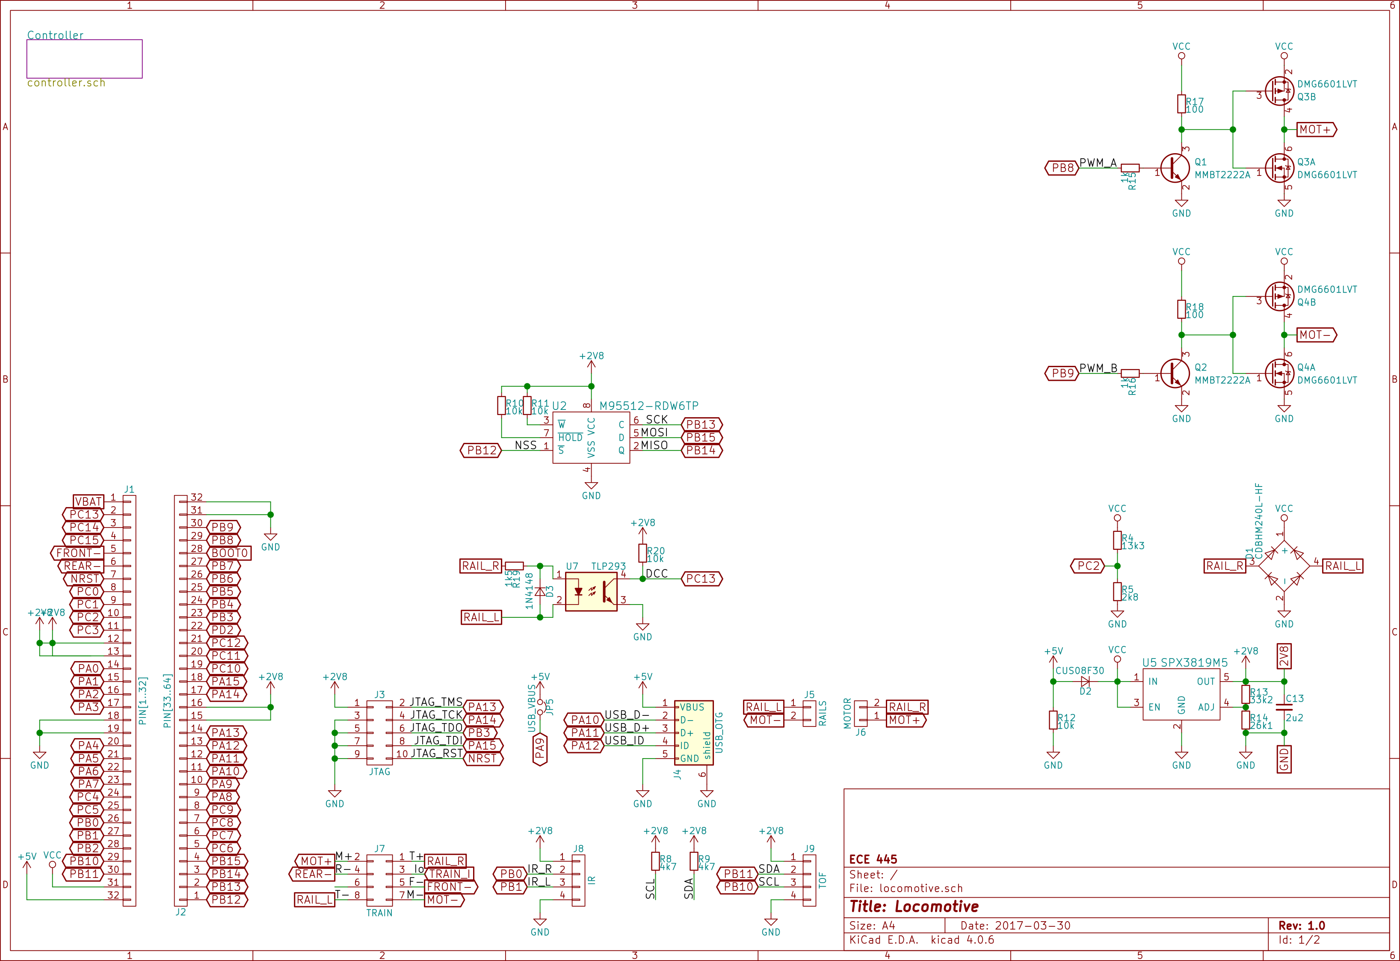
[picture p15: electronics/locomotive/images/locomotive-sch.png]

\end{center}

\subsection{Obstacle Detector}
\begin{center}
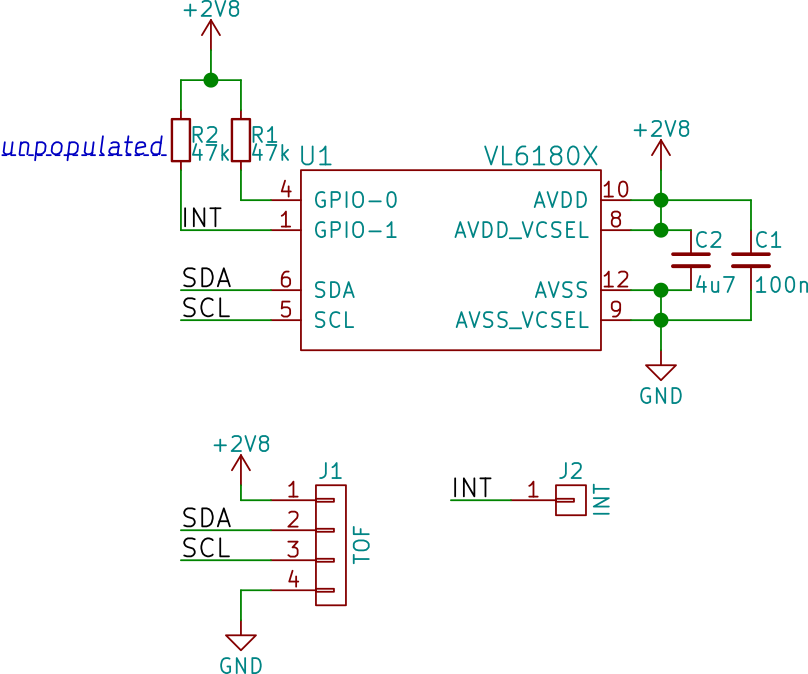
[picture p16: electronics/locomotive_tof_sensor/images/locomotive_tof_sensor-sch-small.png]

\end{center}

\subsection{Beacon Reader}
\begin{center}
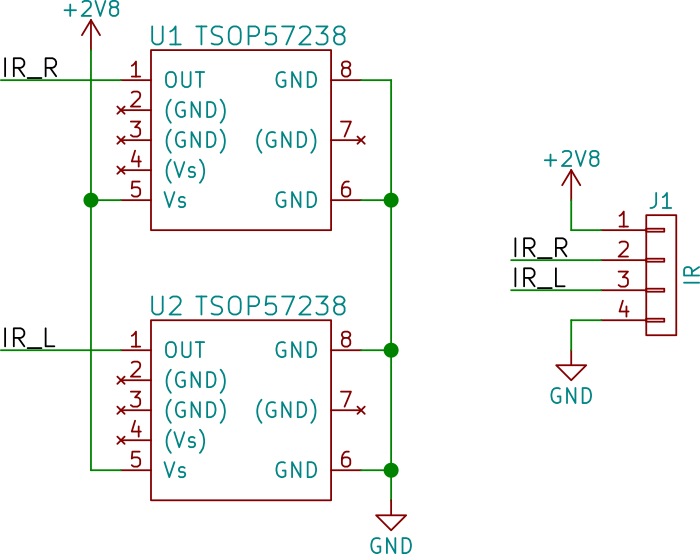
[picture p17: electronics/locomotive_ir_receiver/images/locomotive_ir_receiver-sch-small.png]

\end{center}

\clearpage

\section{Pinouts}

\begin{singlespacing}
\begin{center}
\begin{longtable}{|r|l|c|c|l|}
\tablecap{STM32F405RGT6 Pinouts}
		\\
		\hline \multicolumn{1}{|p{2em}|}{\centpcol Pin} &
		\multicolumn{1}{p{4em}|}{\centpcol Name} &
		\multicolumn{1}{p{4em}|}{\centpcol Type} &
		\multicolumn{1}{p{4em}|}{\centpcol Structure} &
		\multicolumn{1}{p{8em}|}{\centpcol Connected}\\ \hline
		\endfirsthead

		\multicolumn{5}{c}
		{{\bfseries \tablename\ \thetable{} -- continued from previous page}} \\
		\hline \multicolumn{1}{|p{2em}|}{\centpcol Pin} &
		\multicolumn{1}{p{4em}|}{\centpcol Name} &
		\multicolumn{1}{p{4em}|}{\centpcol Type} &
		\multicolumn{1}{p{4em}|}{\centpcol Structure} &
		\multicolumn{1}{p{8em}|}{\centpcol Connected}\\ \hline
		\endhead

		\hline \multicolumn{5}{|r|}{{Continued on next page}} \\ \hline
		\endfoot
		\endlastfoot
			1 & VBAT & S & FT & VBAT \\ \hline

			2 & PC13 & IO & FT & DCC IN \\ \hline

			3 & PC14 & IO & FT & RTC \\ \hline

			4 & PC15 & IO & FT & RTC \\ \hline

			5 & PH0 & IO & FT & crystal \\ \hline

			6 & PH1 & IO & FT & crystal \\ \hline

			7 & NRST & IO & RST & JTAG\_RST \\ \hline

			8 & PC0 & IO & FT & \\ \hline

			9 & PC1 & IO & FT & \\ \hline

			10 & PC2 & IO & FT & TRACK V \\ \hline

			11 & PC3 & IO & FT & MOTOR EMF \\ \hline

			12 & VSSA & S & & GND \\ \hline

			13 & VDDA & S & & 2V8 \\ \hline

			14 & PA0 & IO & FT & \\ \hline

			15 & PA1 & IO & FT & \\ \hline

			16 & PA2 & IO & FT & \\ \hline

			17 & PA3 & IO & FT & \\ \hline

			18 & VSS & S & & GND \\ \hline

			19 & VDD & S & & 2V8 \\ \hline

			20 & PA4 & IO & TTa & \\ \hline

			21 & PA5 & IO & TTa & \\ \hline

			22 & PA6 & IO & FT & Rear LED \\ \hline

			23 & PA7 & IO & FT & Front LED \\ \hline

			24 & PC4 & IO & FT & \\ \hline

			25 & PC5 & IO & FT & \\ \hline

			26 & PB0 & IO & FT & IR RCVR R \\ \hline

			27 & PB1 & IO & FT & IR RCVR L \\ \hline

			28 & PB2 & IO & FT & BOOT1 10k PD \\ \hline

			29 & PB10 & IO & FT & TOF SCL \\ \hline

			30 & PB11 & IO & FT & TOF SDA \\ \hline

			31 & VCAP1 & S & & 2u2 cap \\ \hline

			32 & VDD & S & & 2V8 \\ \hline

			33 & PB12 & IO & FT & FLASH ~S \\ \hline

			34 & PB13 & IO & FT & FLASH C \\ \hline

			35 & PB14 & IO & FT & FLASH Q \\ \hline

			36 & PB15 & IO & FT & FLASH D \\ \hline

			37 & PC6 & IO & FT & \\ \hline

			38 & PC7 & IO & FT & \\ \hline

			39 & PC8 & IO & FT & \\ \hline

			40 & PC9 & IO & FT & \\ \hline

			41 & PA8 & IO & FT & \\ \hline

			42 & PA9 & IO & FT & USB\_VBUS \\ \hline

			43 & PA10 & IO & FT & USB\_ID \\ \hline

			44 & PA11 & IO & FT & USB\_D- \\ \hline

			45 & PA12 & IO & FT & USB\_D+ \\ \hline

			46 & PA13 & IO & FT & JTAG\_TMS \\ \hline

			47 & VCAP2 & S & & 2u2 cap \\ \hline

			48 & VDD & S & & 2V8 \\ \hline

			49 & PA14 & IO & FT & JTAG\_TCK \\ \hline

			50 & PA15 & IO & FT & JTAG\_TDI \\ \hline

			51 & PC10 & IO & FT & \\ \hline

			52 & PC11 & IO & FT & \\ \hline

			53 & PC12 & IO & FT & \\ \hline

			54 & PD2 & IO & FT & \\ \hline

			55 & PB3 & IO & FT & JTAG\_TDO \\ \hline

			56 & PB4 & IO & FT & \\ \hline

			57 & PB5 & IO & FT & \\ \hline

			58 & PB6 & IO & FT & \\ \hline

			59 & PB7 & IO & FT & \\ \hline

			60 & BOOT0 & I & B & BOOT0 10k PD \\ \hline

			61 & PB8 & IO & FT & MOTOR A \\ \hline

			62 & PB9 & IO & FT & MOTOR B \\ \hline

			63 & VSS & S & & GND \\ \hline

			64 & VDD & S & & 2V8 \\ \hline

	\end{longtable}
\end{center}
\end{singlespacing}

\clearpage

\section{Bill Of Materials}

\begin{singlespacing}
\begin{center}
\begin{longtable}{|l|l|l|c|l|c|r|r|}
\tablecap{Beacon BOM}
		\\
		\hline \multicolumn{1}{|p{6em}|}{\centpcol Description} &
		\multicolumn{1}{p{8em}|}{\centpcol Part} &
		\multicolumn{1}{p{3em}|}{\centpcol Type} &
		\multicolumn{1}{p{2em}|}{\centpcol Value} &
		\multicolumn{1}{p{4em}|}{\centpcol Package} &
		\multicolumn{1}{p{2em}|}{\centpcol Qty} &
		\multicolumn{1}{p{2em}|}{\centpcol Unit (\$)} &
		\multicolumn{1}{p{2em}|}{\centpcol Total (\$)}\\ \hline
		\endfirsthead

		\multicolumn{8}{c}
		{{\bfseries \tablename\ \thetable{} -- continued from previous page}} \\
		\hline \multicolumn{1}{|p{6em}|}{\centpcol Description} &
		\multicolumn{1}{p{8em}|}{\centpcol Part} &
		\multicolumn{1}{p{3em}|}{\centpcol Type} &
		\multicolumn{1}{p{2em}|}{\centpcol Value} &
		\multicolumn{1}{p{4em}|}{\centpcol Package} &
		\multicolumn{1}{p{2em}|}{\centpcol Qty} &
		\multicolumn{1}{p{2em}|}{\centpcol Unit (\$)} &
		\multicolumn{1}{p{2em}|}{\centpcol Total (\$)}\\ \hline
		\endhead

		\hline \multicolumn{8}{|r|}{{Continued on next page}} \\ \hline
		\endfoot
		\endlastfoot
			ATtiny45 & \href{http://www.digikey.com/product-detail/en/microchip-technology/ATTINY45-20XUR/ATTINY45-20XURCT-ND/2774364}{ATTINY45-20XUR} & MCU & & TSSOP-8 & 1 & 1.19 & 1.19 \\ \hline

			RST pull-up, gate pull-down & \href{http://www.digikey.com/product-detail/en/yageo/RC0603FR-0710KL/311-10.0KHRCT-ND/729827}{RC0603FR-0710KL} & R & 10k & 0603 & 2 & 0.10 & 0.20 \\ \hline

			Gate resistor & \href{http://www.digikey.com/product-detail/en/yageo/RC0603FR-07100RL/311-100HRCT-ND/729835}{RC0603FR-07100RL} & R & 100 & 0603 & 1 & 0.10 & 0.10 \\ \hline

			LED limiting & \href{http://www.digikey.com/product-detail/en/yageo/RC0603FR-0747RL/311-47.0HRCT-ND/730199}{RC0603FR-0747RL} & R & 47 & 0603 & 1 & 0.10 & 0.10 \\ \hline

			IR LED & \href{http://www.digikey.com/product-detail/en/everlight-electronics-co-ltd/IR19-21C-TR8/1080-1354-1-ND/2676088}{IR19-21C/TR8} & LED & & 0603 & 1 & 0.50 & 0.50 \\ \hline

			N MOSFET & \href{http://www.digikey.com/product-detail/en/panasonic-electronic-components/2N7002E/2N7002ECT-ND/4357001}{2N7002E} & NFET & & SOT-23-3 & 1 & 0.23 & 0.23 \\ \hline

			Full bridge rectifier & \href{http://www.digikey.com/product-detail/en/infineon-technologies/BAS-4002A-RPP-E6327/BAS4002ARPPE6327INCT-ND/2023145}{BAS4002A-RPP} & D & & SOT143-4 & 1 & 0.41 & 0.41 \\ \hline

			2.8V LDO voltage regulator & \href{http://www.digikey.com/product-detail/en/texas-instruments/TPS70928DBVT/296-39473-1-ND/5143421}{TPS70928DVB} & VREG & 2v8 & SOT-23-5 & 1 & 1.37 & 1.37 \\ \hline

			Input decoupling cap & \href{http://www.digikey.com/product-detail/en/taiyo-yuden/UMK107BJ105KA-T/587-2400-1-ND/2179013}{UMK107BJ105KA-T} & C & 1u & 0603 & 1 & 0.16 & 0.16 \\ \hline

			Output decoupling cap & \href{http://www.digikey.com/product-detail/en/murata-electronics-north-america/GRM188R60J226MEA0D/490-7611-1-ND/4280544}{GRM188R60J226MEA0D} & C & 22u & 0603 & 1 & 0.27 & 0.27 \\ \hline

	\end{longtable}

\begin{longtable}{|l|l|l|c|l|c|r|r|}
\tablecap{Locomotive BOM}
		\\
		\hline \multicolumn{1}{|p{4em}|}{\centpcol Reference} &
		\multicolumn{1}{p{8em}|}{\centpcol Part} &
		\multicolumn{1}{p{3em}|}{\centpcol Type} &
		\multicolumn{1}{p{2em}|}{\centpcol Value} &
		\multicolumn{1}{p{4em}|}{\centpcol Package} &
		\multicolumn{1}{p{2em}|}{\centpcol Qty} &
		\multicolumn{1}{p{2em}|}{\centpcol Unit (\$)} &
		\multicolumn{1}{p{2em}|}{\centpcol Total (\$)}\\ \hline
		\endfirsthead

		\multicolumn{8}{c}
		{{\bfseries \tablename\ \thetable{} -- continued from previous page}} \\
		\hline \multicolumn{1}{|p{4em}|}{\centpcol Reference} &
		\multicolumn{1}{p{8em}|}{\centpcol Part} &
		\multicolumn{1}{p{3em}|}{\centpcol Type} &
		\multicolumn{1}{p{2em}|}{\centpcol Value} &
		\multicolumn{1}{p{4em}|}{\centpcol Package} &
		\multicolumn{1}{p{2em}|}{\centpcol Qty} &
		\multicolumn{1}{p{2em}|}{\centpcol Unit (\$)} &
		\multicolumn{1}{p{2em}|}{\centpcol Total (\$)}\\ \hline
		\endhead

		\hline \multicolumn{8}{|r|}{{Continued on next page}} \\ \hline
		\endfoot
		\endlastfoot
			U1 & STM32F405RGT6 & MCU & & LQFP-64 & 1 & 10.58 & 10.58 \\ \hline

			U2 & M95512-RDW6TP & EEPROM & 512K & TSSOP-8 & 1 & 1.00 & 1.00 \\ \hline

			U5 & SPX3819M5-L/TR & LDO VREG & 500mA & SOT-23-5 & 1 & 0.72 & 0.72 \\ \hline

			U7 & TLP293 & Optoisolator & & SOIC-4 & 1 & 0.52 & 0.52 \\ \hline

			Q1, Q2 & MMBT2222A & NPN BJT & & SOT-23-3 & 2 & 0.20 & 0.40 \\ \hline

			Q3, Q4 & DMG6601LVT-7 & PFET+NFET & 1.28A & TSOT-23-6 & 2 & 0.39 & 0.78 \\ \hline

			D1 & CDBHM240L-HF & Rectifier & 2A & TO-269AA & 1 & 0.84 & 0.84 \\ \hline

			D2 & CUS08F30 & Diode & & SOD-323 & 1 & 0.36 & 0.36 \\ \hline

			D3 & 1N4148X-TP & Diode & & SOD-523 & 1 & 0.14 & 0.14 \\ \hline

			R17, R18 & 3522100RJT & Resistor & 100 & 2512 & 2 & 0.72 & 1.44 \\ \hline

			R15, R16 & RC0603JR-071KL & Resistor & 1k & 0603 & 2 & 0.10 & 0.20 \\ \hline

			R19 & RC0603JR-071K5L & Resistor & 1k5 & 0603 & 1 & 0.10 & 0.10 \\ \hline

			R5 & RC0603FR-072K8L & Resistor & 2k8 & 0603 & 1 & 0.10 & 0.10 \\ \hline

			R8, R9 & RC0603JR-074K7L & Resistor & 4k7 & 0603 & 2 & 0.10 & 0.20 \\ \hline

			R1-R3, R10-R12, R20 & RC0603JR-0710KL & Resistor & 10k & 0603 & 7 & 0.10 & 0.70 \\ \hline

			R4 & RC0603FR-0713K3L & Resistor & 13k3 & 0603 & 1 & 0.10 & 0.10 \\ \hline

			R14 & RC0603FR-0726K1L & Resistor & 26k1 & 0603 & 1 & 0.10 & 0.10 \\ \hline

			R13 & RC0603FR-0733K2L & Resistor & 33k2 & 0603 & 1 & 0.10 & 0.10 \\ \hline

			C4, C5 & CL10C060CB8NNNC & Capacitor & 6p & 0603 & 2 & 0.10 & 0.20 \\ \hline

			C3, C7-C11 & GRM188R71C104KA01D & Capacitor & 100n & 0603 & 6 & 0.10 & 0.60 \\ \hline

			C12 & GRM188R61E105KA12D & Capacitor & 1u & 0603 & 1 & 0.10 & 0.10 \\ \hline

			C1, C2, C13 & CL10A225KP8NNNC & Capacitor & 2u2 & 0603 & 3 & 0.12 & 0.36 \\ \hline

			C6 & CL10B475KQ8NQNC & Capacitor & 4u7 & 0603 & 1 & 0.10 & 0.10 \\ \hline

			L1 & MI0603J601R-10 & Ferrite Bead & 600 & 0603 & 1 & 0.10 & 0.10 \\ \hline

			Y1 & CX3225SB16000D0GZJC1 & Crystal & 16MHz & SMD-4 & 1 & 0.66 & 0.66 \\ \hline

			J3 & FTSH-105-01-F-DV-K & Connector & & SMD-10 & 1 & 2.90 & 2.90 \\ \hline

			J4 & 10118192-0001LF & Connector & & SMD-5 & 1 & 0.46 & 0.46 \\ \hline

			J7 & 450-80-272-00-106101 & Connector & & SMD-8 & 1 & 0.76 & 0.76 \\ \hline

			J8, J9 & BM04B-GHS-TBT & Connector & & JST-GH-4 & 2 & 0.44 & 0.88 \\ \hline

	\end{longtable}

\begin{longtable}{|l|l|l|c|l|c|r|r|}
\tablecap{Obstacle Detector BOM}
		\\
		\hline \multicolumn{1}{|p{4em}|}{\centpcol Reference} &
		\multicolumn{1}{p{8em}|}{\centpcol Part} &
		\multicolumn{1}{p{3em}|}{\centpcol Type} &
		\multicolumn{1}{p{2em}|}{\centpcol Value} &
		\multicolumn{1}{p{4em}|}{\centpcol Package} &
		\multicolumn{1}{p{2em}|}{\centpcol Qty} &
		\multicolumn{1}{p{2em}|}{\centpcol Unit (\$)} &
		\multicolumn{1}{p{2em}|}{\centpcol Total (\$)}\\ \hline
		\endfirsthead

		\multicolumn{8}{c}
		{{\bfseries \tablename\ \thetable{} -- continued from previous page}} \\
		\hline \multicolumn{1}{|p{4em}|}{\centpcol Reference} &
		\multicolumn{1}{p{8em}|}{\centpcol Part} &
		\multicolumn{1}{p{3em}|}{\centpcol Type} &
		\multicolumn{1}{p{2em}|}{\centpcol Value} &
		\multicolumn{1}{p{4em}|}{\centpcol Package} &
		\multicolumn{1}{p{2em}|}{\centpcol Qty} &
		\multicolumn{1}{p{2em}|}{\centpcol Unit (\$)} &
		\multicolumn{1}{p{2em}|}{\centpcol Total (\$)}\\ \hline
		\endhead

		\hline \multicolumn{8}{|r|}{{Continued on next page}} \\ \hline
		\endfoot
		\endlastfoot
			U1 & \href{http://www.digikey.com/product-detail/en/stmicroelectronics/VL6180XV0NR-1/497-14702-1-ND/4854910}{VL6180XV0NR/1} & Sensor & & SMD-12 & 1 & 4.91 & 4.91 \\ \hline

			R1, R2 & \href{https://www.digikey.com/product-detail/en/yageo/RC0603JR-0747KL/311-47KGRCT-ND/729741}{RC0603JR-0747KL} & Resistor & 47k & 0603 & 2 & 0.10 & 0.20 \\ \hline

			C1 & \href{https://www.digikey.com/product-detail/en/murata-electronics-north-america/GRM188R71C104KA01D/490-1532-1-ND/587771}{GRM188R71C104KA01D} & Capacitor & 100n & 0603 & 1 & 0.10 & 0.10 \\ \hline

			C2 & \href{http://www.digikey.com/product-detail/en/samsung-electro-mechanics-america-inc/CL10B475KQ8NQNC/1276-2087-1-ND/3890173}{CL10B475KQ8NQNC} & Capacitor & 4u7 & 0603 & 1 & 0.10 & 0.10 \\ \hline

			J1 & \href{https://www.digikey.com/product-detail/en/jst-sales-america-inc/BM04B-GHS-TBT(LF)(SN)(N)/455-1580-1-ND/807848}{BM04B-GHS-TBT} & Connector & 4 & JST-GH & 1 & 0.44 & 0.44 \\ \hline

	\end{longtable}

\begin{longtable}{|l|l|l|c|l|c|r|r|}
\tablecap{Beacon Reader BOM}
		\\
		\hline \multicolumn{1}{|p{4em}|}{\centpcol Reference} &
		\multicolumn{1}{p{8em}|}{\centpcol Part} &
		\multicolumn{1}{p{3em}|}{\centpcol Type} &
		\multicolumn{1}{p{2em}|}{\centpcol Value} &
		\multicolumn{1}{p{4em}|}{\centpcol Package} &
		\multicolumn{1}{p{2em}|}{\centpcol Qty} &
		\multicolumn{1}{p{2em}|}{\centpcol Unit (\$)} &
		\multicolumn{1}{p{2em}|}{\centpcol Total (\$)}\\ \hline
		\endfirsthead

		\multicolumn{8}{c}
		{{\bfseries \tablename\ \thetable{} -- continued from previous page}} \\
		\hline \multicolumn{1}{|p{4em}|}{\centpcol Reference} &
		\multicolumn{1}{p{8em}|}{\centpcol Part} &
		\multicolumn{1}{p{3em}|}{\centpcol Type} &
		\multicolumn{1}{p{2em}|}{\centpcol Value} &
		\multicolumn{1}{p{4em}|}{\centpcol Package} &
		\multicolumn{1}{p{2em}|}{\centpcol Qty} &
		\multicolumn{1}{p{2em}|}{\centpcol Unit (\$)} &
		\multicolumn{1}{p{2em}|}{\centpcol Total (\$)}\\ \hline
		\endhead

		\hline \multicolumn{8}{|r|}{{Continued on next page}} \\ \hline
		\endfoot
		\endlastfoot
			U1, U2 & \href{http://www.digikey.com/product-detail/en/vishay-semiconductor-opto-division/TSOP57238TT1/TSOP57238TT1CT-ND/3175136}{TSOP57238TT1} & Sensor & 38kHz & SMD & 2 & 2.23 & 4.46 \\ \hline

			J1 & \href{https://www.digikey.com/product-detail/en/jst-sales-america-inc/BM04B-GHS-TBT(LF)(SN)(N)/455-1580-1-ND/807848}{BM04B-GHS-TBT} & Connector & 4 & JST-GH & 1 & 0.44 & 0.44 \\ \hline

	\end{longtable}
\end{center}
\end{singlespacing}

\begin{center}
All source files, including the source for this document, are hosted on GitHub at \href{https://github.com/0xdec/bcan}{0xdec/bcan}.
\end{center}

\end{appendix}

\end{spacing}
\end{document}

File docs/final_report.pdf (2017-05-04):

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

## Abstract

BCAN'T is a system for model trains that consists of infrared beacons and a laser time-of-
ight sensor in order
to enable true set and go operation. Over the course of the project we developed the beacon reading system and it demonstrated it works, as well as a complete control system on the locomotive that interfaces the beacon and time-of-

ight data to control to motor and other peripherals. Unfortunately, due to last minute hardware failures, we were unable to integrate all the components onto a locomotive, but most of the components were demonstrated to work on their own.

i

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

## 1 Introduction

1.1 Objective

Model trains have become more and more advanced over the last few decades, but they are still controlled entirely by a human operator. These human operators are solely responsible for ensuring that no harm comes to the train. A lapse in attention can be disastrous, causing damage that could be very costly to repair. Model trains currently do not have the ability to detect obstacles or other trains in front of them. If not stopped in time a crash may occur, often resulting in derailment or physical damage. Additionally, derailment may occur when a train is traveling at high speeds on a curved tracks. The train has no recourse for these situations other than for the operator to manually slow or stop it to avoid an accident.

Currently, the National Model Railroad Association (NMRA) denes the Digital Command Control (DCC) standard for model trains. DCC allows for digital control of various train functions such as lights, speed, direction, sound, and much more[1]. One downside to DCC is that smooth operation is completely dependent on the human operator who must manually control the train as it is unable to react to its environment autonomously. In addition, DCC has a steep learning curve and setting up a system without prior experience can be quite challenging.

Our solution is to give each locomotive the ability to respond to the track on its own by detecting obstacles and reacting to programmable beacons placed on the track. A distance sensor is placed on the front of the train to detect obstacles directly in front of it. Small beacon modules placed on the track are set to send out unique identiers to the train to let it know what speed it should travel at. Essentially, the end goal is to have the train sense potential issues along the track that would cause collision or derailment and act to avert such problems. Our solution is a convenient alternative to those who wish to have speed control for their locomotives. The sensors integrated with the locomotive also provide some measure of protection against human negligence by avoiding obstacles and preventing derailment.

1.2 High-Level Requirements

Must be able to operate indenitely on existing methods of track power, both analog (DC) and bipolar
| Digital Command Control (DCC).

Must be able to detect oncoming obstacles on the track and stop to avoid derailment or damage.

Must be able to read customizable speed limit beacons that are powered by the tracks and adjust its
| speed accordingly.

## 2 Design

Our solution consists of two independent systems: the beacon boards and the locomotive controller. The beacons are small standalone boards on the track that continuously broadcast a unique ID that is read as the train passes over. The locomotive controller consists of three PCB's on the train and is responsible for reading beacons, identifying obstacles, and controlling the motor. The block diagram is shown in Figure 1.

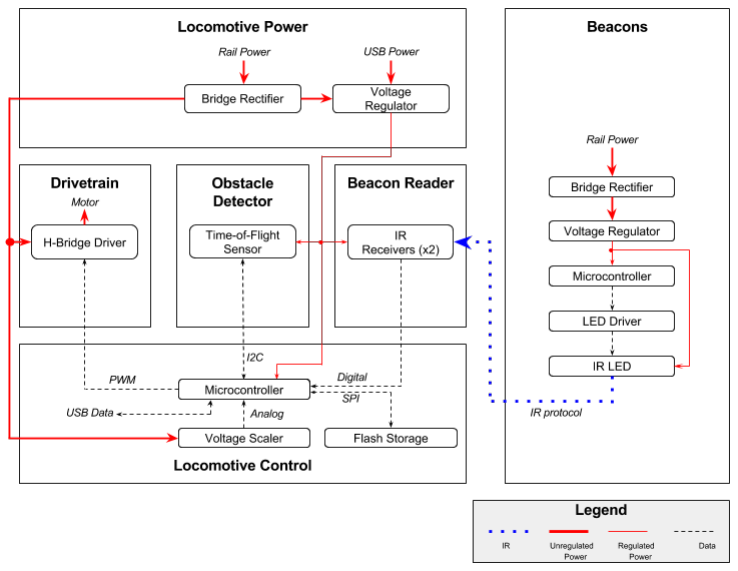
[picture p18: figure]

Figure 1: Block Diagram.

2.1 Beacon

The beacon is small board that sits between two track ties as shown in Figure 2. The image on the left shows the placement of a beacon on the track, and the image on the right shows three individual beacons with their ID labels. Its function is to broadcast a unique ID to the IR receiver board on the locomotive. Each ID is mapped to a specic function that can be programmed on the locomotive control board. A bridge rectier and a voltage regulator are used to provide 2.8V power to the microcontroller, LED driver, and IR LED. The microcontroller controls the IR LED to continuously broadcast the board's ID for the IR receiver on the locomotive board to read.

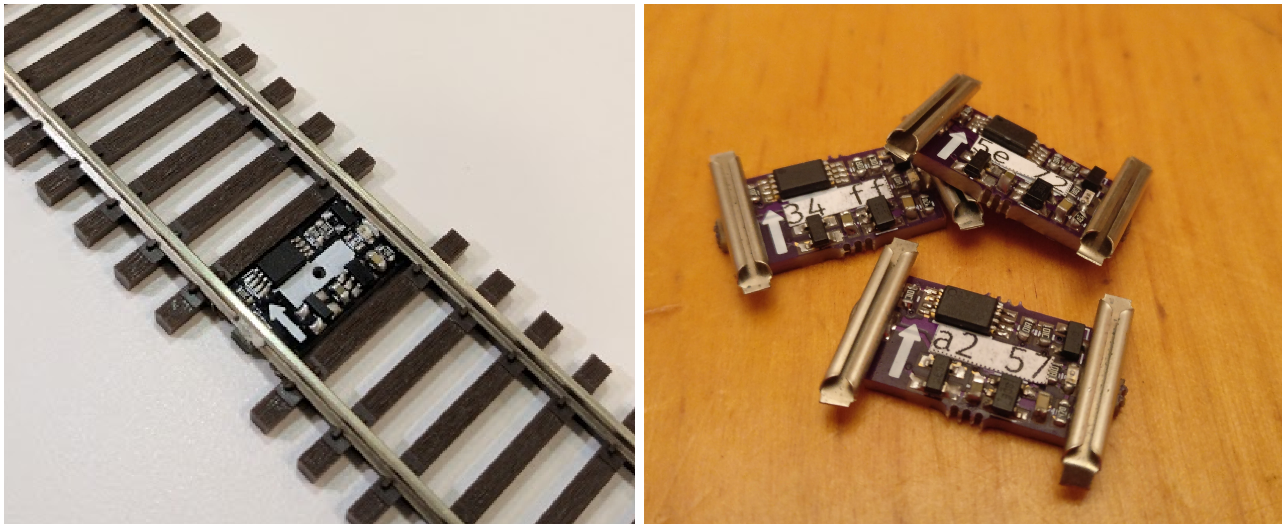
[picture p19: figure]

Figure 2: Beacon Boards.

2.1.1 Schematic

The schematics for the beacon board IR LED and power circuits are shown in Figure 3 and Figure 4, respectively. The shunt resistor R5 is used to create a clean 38kHz modulated signal since the LED is unable to switch fast enough. The calculations for R2 and R4 are shown in Calculations 1 and 2 in Appendix B.


Figure 3: Beacon IR LED Circuit.


Figure 4: Beacon Power Circuit.

2.1.2 Bridge Rectier

Since the voltage regulator only takes positive voltage, the full-bridge rectier is needed rectify the power signals from the rails. It consists of four schottky diodes in a bridge conguration and rectify rail voltages ranging from -16V to +16V.

2.1.3 Voltage Regulator

A linear voltage regulator takes an input from the rectied rail power and bring the voltage down to 2.8V from an input voltage of up to 16V. It provides the power needed for the MCU and its peripherals.

The TPS709 linear voltage regulator data sheet species a minimum input voltage of 2.7V[2]. Testing showed that an input voltage of 3.5V would produce an output voltage of 2.63V, while input voltages lower than 3.5V would produce an output voltage that is below our requirements. Therefore, a input voltage of 3.5V would be the minimum threshold for our project to function properly.

2.1.4 Microcontroller

The microcontroller used is an ATtiny45 8-bit AVR processor. It uses a single GPIO pin to control the LED driver circuit and continuously broadcast the board's unique ID using the IR protocol.

2.1.5 LED Driver

The LED driver circuit consists of an N-channel MOSFET, a gate resistor, and a pull down resistor. The MOSFET conducts current when the I/O pin from the microcontroller is set to high. The gate resistor is used to prevent damage due to overcurrent to the microcontroller and the pull down resistor is used to ensure the MOSFET is turned o when the voltage at the gate is left

oating.

2.1.6 IR LED

The 940nm IR LED is used to broadcast a unique ID that the receiver on the locomotive can read. It is controlled by the LED driver circuit using PWM. The viewing half-angle for the LED can be calculated using Equation 1. The calculation for the viewing half angle can is shown in Calculation 3 in Appendix B.

1

2

= arctan
VmaxT

2Hmin
(1)

Vmax is the max speed of the train, T is the length of one ID message, and Hmin is the minimum distance from the beacon board LED to the IR receivers on the train.

2.2 Locomotive Power

The locomotive power circuit takes an input voltage ranging from -16V to +16V from the rail or 5V from the USB. It then recties and regulates that voltage down to 2.8V in order to power the microcontroller and its peripherals. A full bridge rectier is used to rectify the AC voltage from the rails. The rectied voltage is then inputted to a linear voltage regulator. The SPX3918 adjustable linear voltage regulator has a minimum input voltage of 2.5V and a maximum dropout voltage of 550mV with a 500mA current draw. This means the minimum input threshold voltage in order for the locomotive components to be powered would be 3.35V, allowing for the microcontroller to be able to wait for the input voltage to reach the 3.5V minimum threshold limit for the beacon board to be powered. The circuit for the locomotive power block is shown in Figure 5.

Other designs were considered for the locomotive power circuit. A switching circuit to switch between the USB power source and the rail power source was considered. However, it was simpler to add a protection diode after the USB voltage source. There were also attempts to regulate the input voltage through the full range of rail voltages with switching circuits, switch-mode power supplies, or batteries. The switching circuits were complex and risked shorting the input and output voltages if the timing was not correct. There were no switch-mode power supplies on the market that had a low enough input voltage for the output that was required. Batteries would have defeated the purpose of drawing power from a wall outlet.

2.2.1 Schematic

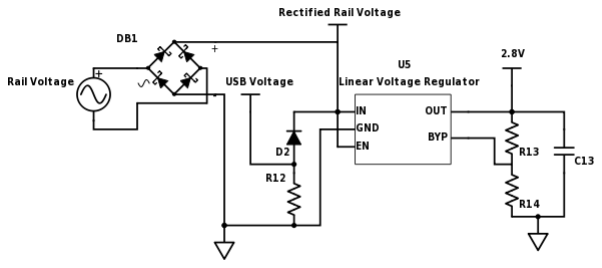
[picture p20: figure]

Figure 5: Locomotive Power Schematic.

2.2.2 Bridge Rectier

The full-bridge rectier is needed to rectify power signals from the rails before they are routed to the voltage regulator, voltage scaler, and motor driver. It consists of four schottky diodes in a bridge conguration and recties voltages ranging from -16V to +16V.

2.2.3 Voltage Regulator

The rectied voltage is fed into a linear voltage regulator in order to bring the voltage down to 2.8V. The 2.8V source is used to power the microcontroller, time-of-

ight sensor, IR receiver, and the voltage scale circuit. Calculation 4 in appendix B shows how the adjustment resistors are calculated for the SPX3819 linear regulator for an output voltage of 2.8V using Equation 2.

Vout = 1:235(1 + R1

R2

) | (2)
2.3 | Locomotive Control

The locomotive control unit consists of a microcontroller and a USB data connection. If there is a USB connection the control unit will enter a programming mode, otherwise it will run the normal track operation.

This allows operators to map the beacon IDs to one of 128 dierent speeds[3]. The microcontroller receives a voltage input via the ADC pin from the voltage scale circuit and outputs a PWM signal to the drivetrain to control the speed. The IR receiver sends beacon IDs to the microcontroller in order to determine what speed the train should go. It also stops the train if the time-of-

ight sensor detects an obstacle in its path.

2.3.1 Schematic

The main part of the control circuit is the STM32F4 microcontroller. It is connected to a M95512-RDW6TP EEPROM for storage of the beacon mappings. The control schematic is shown in Figure 6.

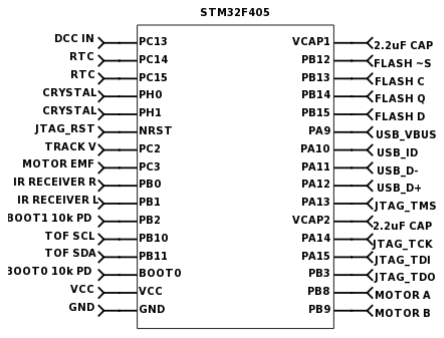
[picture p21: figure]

Figure 6: Locomotive Control Schematic.

2.3.2 Microcontroller

The microcontroller used is an STM32F405 32-bit ARM processor. It communicates with the time-of-

ight
sensor via I2C, the IR receiver digitally, and control the motor with PWM signals. It also stores conguration data for the beacons in external memory.

2.3.3 Flash Storage

An EEPROM

| ash chip is used to store the beacon mappings. It communicates with the microcontroller
over SPI. EEPROM was chosen since we can address individual bytes, which makes performing binary search through the dataset for the beacon mappings more ecient.

2.3.4 Voltage Scaler

The voltage scaler circuit originally included an operational amplier buer to improve the accuracy of the voltage readings. However, we were unable to nd an operation amplier that could be powered by a 2.8V source, so errors were corrected in software instead. The voltage scaler circuit consists of a resistive voltage divider, shown in Figure 7, that scales the rectied rail voltage down to a lower voltage that can be read by the microcontroller's ADC. The rectied rail voltage ranges from 0-16V and the microcontroller ADC can read voltages from 0-2.8V. Two resistors divide the voltage to output a range of 0-2.8V, which will give 4096 dierent values for a 12-bit precision ADC. The calculations using Equation 3 of the voltage divider's resistor values are shown in Calculation 5 in appendix B.

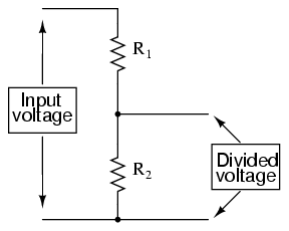
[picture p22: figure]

Figure 7: Voltage Divider Circuit.

Vout = Vin

R2

R1 + R2

(3)

2.4 Locomotive Drivetrain

The locomotive drivetrain unit consists of the motor controller circuit that interfaces the PWM signal from the microcontroller with the rectied rail power in order to power the motor. The circuit consists of a MOSFET H-bridge that is gate-driven by NPN transistors. The drivetrain circuit is shown in Figure 8.

In order to drive the MOSFETs in the H-bridge, optoisolators were also considered. However, we were unable to nd an optoisolator that would support driving the LED with our maximum rectied rail voltage.

2.4.1 Schematic

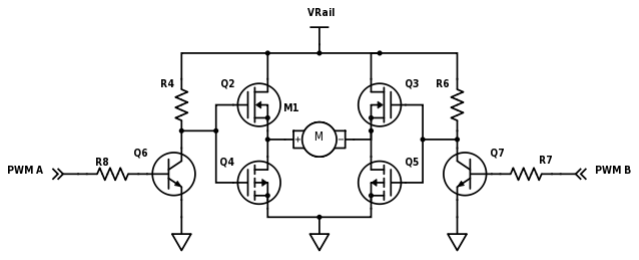
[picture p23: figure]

Figure 8: Locomotive Drivetrain Schematic.

2.4.2 Motor Controller

The motor driver circuit consists of two PWM signals driving two NPN transistors which each control an NFET and a PFET. The MOSFETs are congured as an H-bridge and allow the motor to run forwards or backwards at any speed determined by the PWM signals. The frequency of the PWM signals is 10kHz to prevent resonance and noise. The motor current range is 1.5A and the motor voltage range is 16V.

2.5 Obstacle Detector

The obstacle detector consists of a time of

ight (TOF) sensor mounted to the front of the train. It detects any obstruction on the tracks that could cause the train to derail and cause an emergency stop. The TOF sensor uses a laser to measure whether the path in front of the train is clear or if the train is approaching an unexpected obstacle. The range of the TOF sensor is approximately 50-200mm[4].

2.6 Beacon Reader

The beacon reader consists of two IR receivers mounted underneath the train on either side. They read beacons as the train passes over them. With two receivers, the microcontroller can infer the direction the train is moving and execute dierent actions accordingly.

2.7 IR Protocol

The IR protocol uses 38kHz modulation present in many televisions and other consumer devices. We chose this frequency because sensors for it are widely available. Our protocol uses Manchester encoding according to the G.E. Thomas convention with a bit period of 960s and data length of 16 bits[5]. The timing diagram for the protocol is shown in Figure 9.

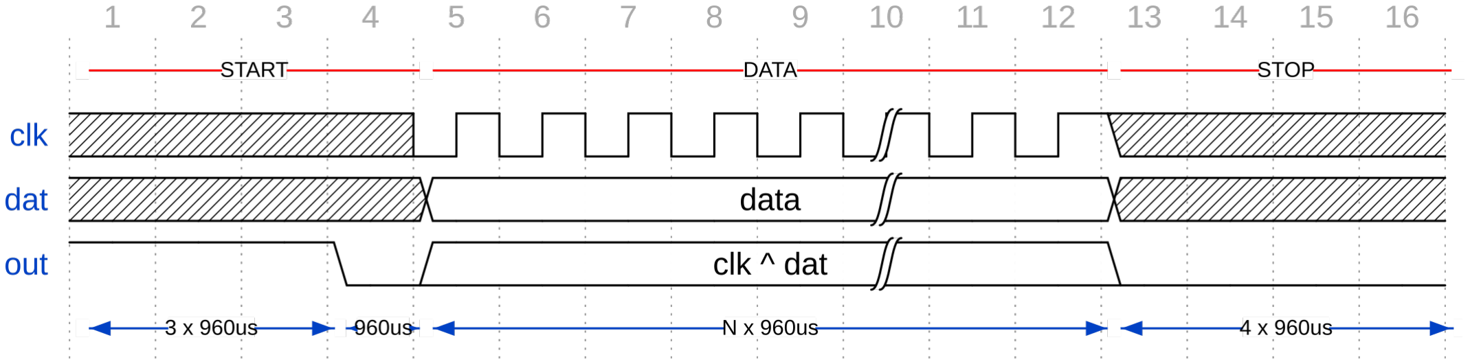
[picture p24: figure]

Figure 9: IR Protocol Timing Diagram.

2.8 Beacon Firmware

The beacon rmware is a simple loop that continuously broadcasts the beacon ID using the IR protocol. Every 480us it determines what the next edge is (rising or falling) and sets the GPIO pin accordingly.

2.9 Locomotive Firmware

The locomotive has two modes of operation: track mode and programming mode. It also reacts to pin change interrupts from the IR receiver. At boot, the microcontroller checks to see if USB is connected. If so, it enters programming mode and presents itself as a USB mass storage device. When the user starts to write a conguration le to the locomotive, the microcontroller will buer each beacon mapping and verify they are being written in ascending order. This is required since at look-up time, it will perform a binary search through the mappings to nd the correct one. If an errored mapping comes in, the microcontroller will stop storing more mappings.

In track mode, the microcontroller will continuously check the obstacle detector, stopping the train if there is one. Then it checks whether a beacon ID is read and looks up the appropriate mapping before executing it. Finally, it makes any motor adjustments as necessary.

The IR receiver also works by invoking a pin change interrupt every time its value changes. Using our IR protocol and taking advantage the repetitive pattern of the data we are sending, we need only store one message length worth of pin changes to calculate the beacon ID. When we have the requisite data, we set a ready

ag which will trigger the main event loop to look up and execute the mapping.

2.9.1 Feature List

Mount as USB mass storage device if USB plugged on boot

Stores the beacon mappings on

ash memory

Reads beacons through pin change interrupts

Can stop the train if an obstacle is detected

Can continuously adjust the motor speed and direction based on track conditions

2.9.2 | Flow Chart
The | owchart for the locomotive operation is is shown in Figure 10.


Figure 10: Locomotive Firmware Control Flow.

2.10 PC Software

Figure 11 shows the web interface (hosted online here) (http://jordi.codes/bcan) to program the beacons. Once specifying the ID, the user can select the instances where the mapping applies and the action the beacon corresponds to.

Allows user to add any number of beacon mappings

Each mapping consists of a beacon ID, description, direction of travel, direction of drain, function, and
| additional parameters for that function

Clicking Save downloads a le that can be copied to the USB mass storage device to program the
| mappings


Figure 11: Beacon Congurator Website.

## 3 Cost

In order to keep costs low, we chose a locomotive microcontroller that can be switched out with a cheaper one in case the user did not require as many peripherals. We also kept the locomotive board limited to 2 layers as a 4 layer board would have signicantly increased the price. On the beacon side, we kept the BOM to under $5 in single quantities, and have already designed a v2.0 with a cheaper microcontroller that has a $1 BOM at quantity 1000.

3.1 Labor

Table 1: Labor Costs

Name | Total Hours | Hourly Rate ($) | Total ($) | Total * 2.5 ($)
Susan Chen | 170 | 36.00 | 6,120.00 | 15,300.00
Prithvi Garimalla | 170 | 36.00 | 6,120.00 | 15,300.00
Jordi Pakey-Rodriguez | 170 | 36.00 | 6,120.00 | 15,300.00
Total | 510 | 108.00 | 18,360.00 | 45,900.00
3.2 | Parts

We spent $200 on parts which, combined with our $45,900 labor costs, gives a total project cost of $46,100.

## 4 Conclusion

4.1 Accomplishments

While our project denitely had some issues that kept it from being a complete success, the most critical and innovative part, beacon reading, worked. It was demonstrated to be versatile and the speed at which the IDs could be read exceeded our expectations. Furthermore, we designed the project to be as economical as possible, so the total cost of the materials for a beacon was quite cheap. Should there be demand for this product in the model train community, we believe there would be a legitimate path to market.

4.2 Uncertainties

We still have a few lingering questions about our project, namely the nature of the eleventh hour failure we experienced. We had soldered the locomotive board and it had been working for two weeks until a short developed two days before the nal demo. After thinking we had identied the cause and replaced the suspect component, another short, this time at the output of the 2.8V voltage regulator appeared. This was approximately 18 hours before our nal demo and the only solution we saw was to solder together another board. Unfortunately, even though this board had never even been powered, the short was still present. Even after thoroughly examining the board under a microscope, the only theory we have for the second board being faulty is a faulty component. At this point, even though we were able to demonstrate the individual aspects of the project worked, integrating them was not successful.

4.3 Ethical Considerations

There are two potential safety concerns with our project, however we believe they are both within the acceptable tolerances for a general consumer product. The rst of these is that the rails of the train track are electrically charged so one could potentially shock themselves. However, we are not changing this characteristic in our design and therefore are not creating any additional safety hazards. This is a well understood risk of model trains so responsible usage dictates they should be kept out of reach of small children or pets. The second is that we are using a time-of-

ight sensor that uses a laser. The laser used is Class 1, which means that it is safe for use under normal conditions and while operating within the manufacturer's specications[4].

In accordance with the IEEE code of ethics, we endeavored to take on technical tasks we feel we are qualied for and seek advice from our mentors for the skills we lack. We sought feedback and criticism for our work and continuously worked to correct our mistakes. We strove for honesty and properly credited individual contributions to our project. Most importantly, we supported and encouraged each other to follow this code of ethics.

4.4 Future work

The software, rmware, and schematics for our project are fully open source and there is no reason why the work on our project has to stop here. Our design choices and decisions are well documented, so should anyone choose to continue our work, they can easily pick up where we left o. We have already designed a v2.0 beacon, and have made a list of changes for the next locomotive version.

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

## Appendix A Requirement and Verication Tables

Table 2: Beacon Requirements and Verications

Requirement | Verication | Verication status (Y or N)
1. Must be able to be powered from rail power with a voltage range of 16V and be able to draw a mini-mum of 60mA. | 1. Connect the board to a bench power supply set at +16V. Verify the LED is lit using a camera. Repeat with -16V.
1. Must be able to modulate the LED between 38kHz - 40kHz. | 1. Connect IR receiver output to an oscilloscope and point it at the IR LED[6]. Verify that the signal is re-ceived.
1. Must have a view angle given by Equation 1 on the axis parallel to the track. | 1. With the datasheet value for and the distance H, solve for VT. Place the receiver at a horizontal distance VT / 2 and a height H from the LED and verify with the oscillo-scope that the ID is read.

Table 3: Locomotive Power Requirements and Verications

Requirement | Verication | Verication status (Y or N)
1. Must be able to accept voltages of 3.35 to 16V or -3.35 to -16V from the rail supply and output a recti-ed rail power of 2.80.2V and sup-ply up to 280mA. | 1. Connect the locomotive to maxi-mum rail power, verify the 2.8V output is active with a multimeter. Reverse the orientation of the train on the track and verify the 2.8V out-put again. Then put a 10 1 Watt resistor across the 2.8V output and measure the current.
1. Must be able to accept power from the USB supply and output 2.80.2V power and supply up to 280mA. | 1. Remove the train from the track and connect USB power. Verify the 2.8V output is active with a multi-meter. Then put a 101 Watt resistor across the 2.8V output and measure the current.

Table 4: Locomotive Control Requirements and Verications

Requirement | Verication | Verication status (Y or N)
1. Must be able to act as a USB Mass storage device when connected to a PC. | 1. With the nal microcontroller rmware, connect it to a PC to put it into programming mode. Copy a valid mapping le to the Mass Storage Device the microcontroller presents itself as. Then without unplugging the microcontroller, verify the le can be read.
1. Must be able to store beacon ID mappings when not powered exter-nally. | 1. Repeat Verication 1, with the bea-con mappings set between two IDs for which there are physical bea-cons that correspond to turning the lights on and the turning the lights o. Then unplug and reconnect the USB. Power the beacons, then hold the locomotive over the beacons and verify the correct actions occur.
1. Must be able to scale a voltage range of 0-16V down to 0-2.8V and be read by the microcontroller's ADC with at least 10 bit precision. | 1. Write and ash a test program that displays the current current ADC reading over the serial connection to the computer. Power the board over USB while connecting the rail power input to a bench power sup-ply and sweep between 0V-27V and ensure the microcontroller is accu-rately displaying at least 128 dis-tinct speed steps.

Table 5: Locomotive Drivetrain Requirements and Verications

Requirement | Verication | Verication status (Y or N)
1. Must be able to take a PWM signal from the microcontroller and con-trol the motor accordingly. | 1. Write and ash a test program to the locomotive microcontroller that will cycle through 0%, 25%, 50%, 75%, and 100% duty cycles on the PWM line. Verify the output of the motor controller with an oscil-loscope.

Table 6: Obstacle Detector Requirements and Verications

Requirement | Verication | Verication status (Y or N)
1. Must detect obstacles at least 50mm in front of the train. | 1. Write and ash a test program to the microcontroller that will display over the PC serial connection the values read from the sensor. Place an object at a distance of 50mm in front of the sensor and 8.25mm o the center axis of the train and per-pendicular to the track. Move to 8.25mm o the center axis in the op-posite direction. Verify both times the object is detected.

Table 7: Beacon Reader Requirements and Verications

Requirement | Verication | Verication status (Y or N)
1. Must be able to sense a 38kHz mod-ulated IR beam and output a de-modulated digital signal. | 1. Connect a beacon to rail power. Write and ash a test program that will display over the PC serial con-nection the value read from the IR receiver. Verify that the value read matches the beacon's ID.

## Appendix B Calculations

B.1 Beacon MOSFET Gate Resistor

Ohm's Law: R =

| V I
I/O input voltage: Vo = 2:8V
Max current per I/O pin: 40mA Choose I1 = 28mA
R1 = | 2:8 0:028 = 100
B.2 | Beacon LED Current-Limiting Resistor

Forward voltage of IR LED: Vf = 1:2V
Supply voltage: Vd = 2:8V
Continuous DC current: I3 = 34mA Using Ohm's Law:
I3 = | VdVf R3 = 2:81:2 R3 = 34mA

R3 = 47

B.3 Beacon LED Half Viewing Angle

Vmax = 1 m
| s
T = 23:04ms

Hmin = 6mm

1

2

= arctan(

| VmaxT 2Hmin ) = arctan( 0:02304 0:006 ) = 75:4
B.4 | Locomotive Voltage Regulator Resistors

Vout = 1:235(1 + R1
| R2 )
R1 = 33:2k
R2 = 26:1k

B.5 Locomotive Voltage Scaler Resistors

Vout = Vin

R2
R1+R2
Vin;max = 16V

Vout;max = 2:8V
R1 = 13:3k

R2 = 2:8k

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

Table 11: Obstacle Detector BOM

Reference | Part | Type | Value | Package | Qty | Unit ($) | Total ($)
U1 | VL6180XV0NR/1 (http://www.digikey.com/product-detail/en/stmicroelectronics/VL6180XV0NR-1/497-14702-1-ND/4854910) | Sensor | | SMD-12 | 1 | 4.91 | 4.91
R1, R2 | RC0603JR-0747KL (https://www.digikey.com/product-detail/en/yageo/RC0603JR-0747KL/311-47KGRCT-ND/729741) | Resistor | 47k | 0603 | 2 | 0.10 | 0.20
C1 | GRM188R71C104KA01D (https://www.digikey.com/product-detail/en/murata-electronics-north-america/GRM188R71C104KA01D/490-1532-1-ND/587771) | Capacitor | 100n | 0603 | 1 | 0.10 | 0.10
C2 | CL10B475KQ8NQNC (http://www.digikey.com/product-detail/en/samsung-electro-mechanics-america-inc/CL10B475KQ8NQNC/1276-2087-1-ND/3890173) | Capacitor | 4u7 | 0603 | 1 | 0.10 | 0.10
J1 | BM04B-GHS-TBT (https://www.digikey.com/product-detail/en/jst-sales-america-inc/BM04B-GHS-TBT(LF)(SN)(N)/455-1580-1-ND/807848) | Connector | 4 | JST-GH | 1 | 0.44 | 0.44

Table 12: Beacon Reader BOM

Reference | Part | Type | Value | Package | Qty | Unit ($) | Total ($)
U1, U2 | TSOP57238TT1 (http://www.digikey.com/product-detail/en/vishay-semiconductor-opto-division/TSOP57238TT1/TSOP57238TT1CT-ND/3175136) | Sensor | 38kHz | SMD | 2 | 2.23 | 4.46
J1 | BM04B-GHS-TBT (https://www.digikey.com/product-detail/en/jst-sales-america-inc/BM04B-GHS-TBT(LF)(SN)(N)/455-1580-1-ND/807848) | Connector | 4 | JST-GH | 1 | 0.44 | 0.44

All source les, including the source for this document, are hosted on GitHub at 0xdec/bcan. (https://github.com/0xdec/bcan)
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

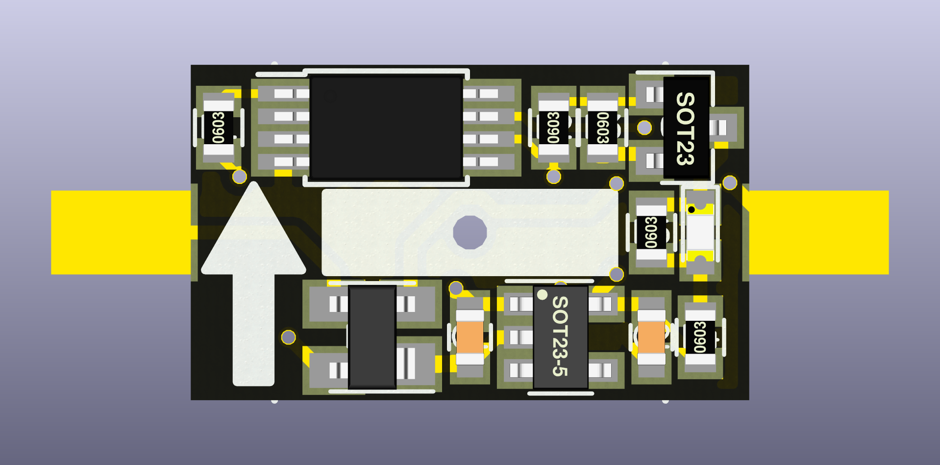
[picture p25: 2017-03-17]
electronics/beacon/v1.1/images/beacon_3d_top.png

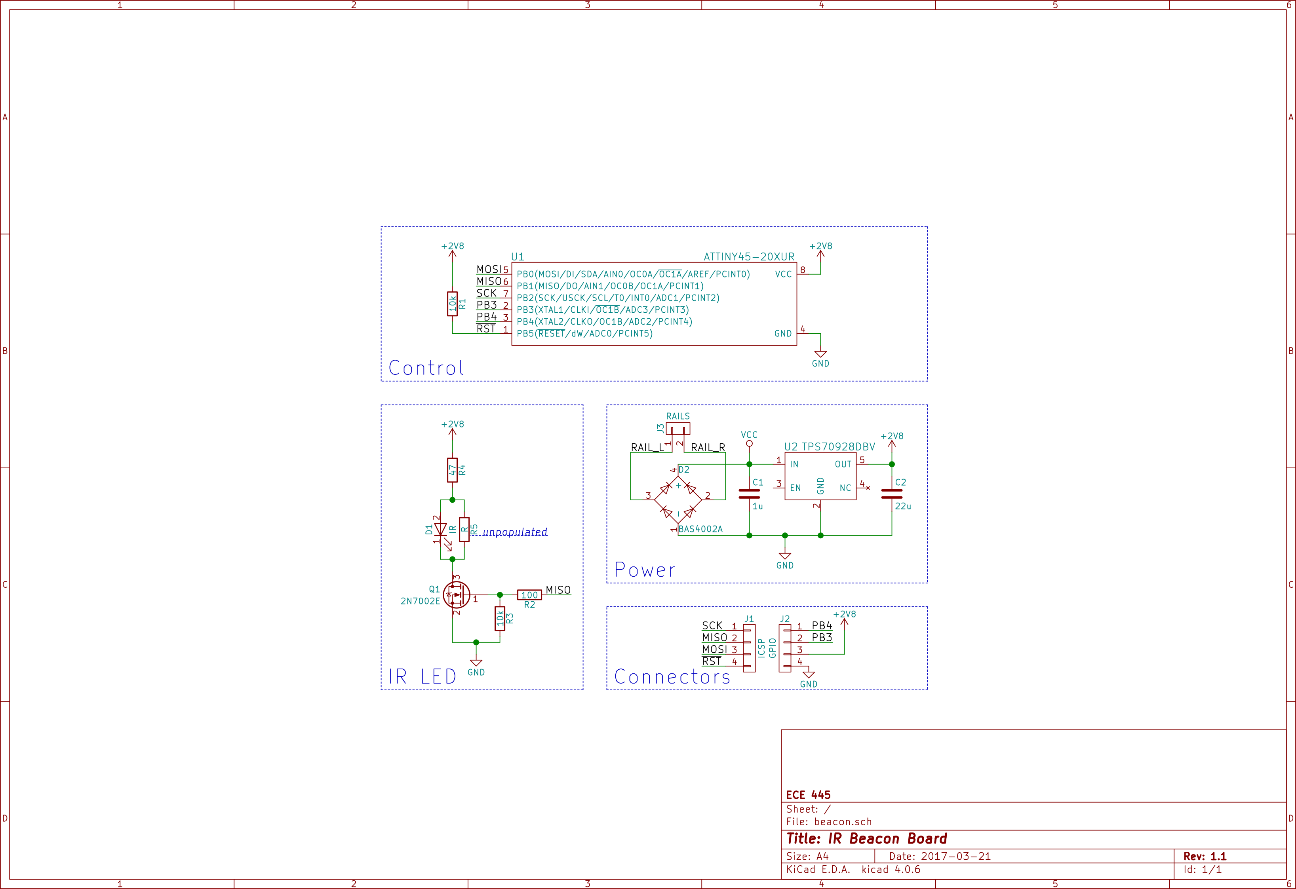
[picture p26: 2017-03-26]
electronics/beacon/v1.1/images/beacon-sch.png

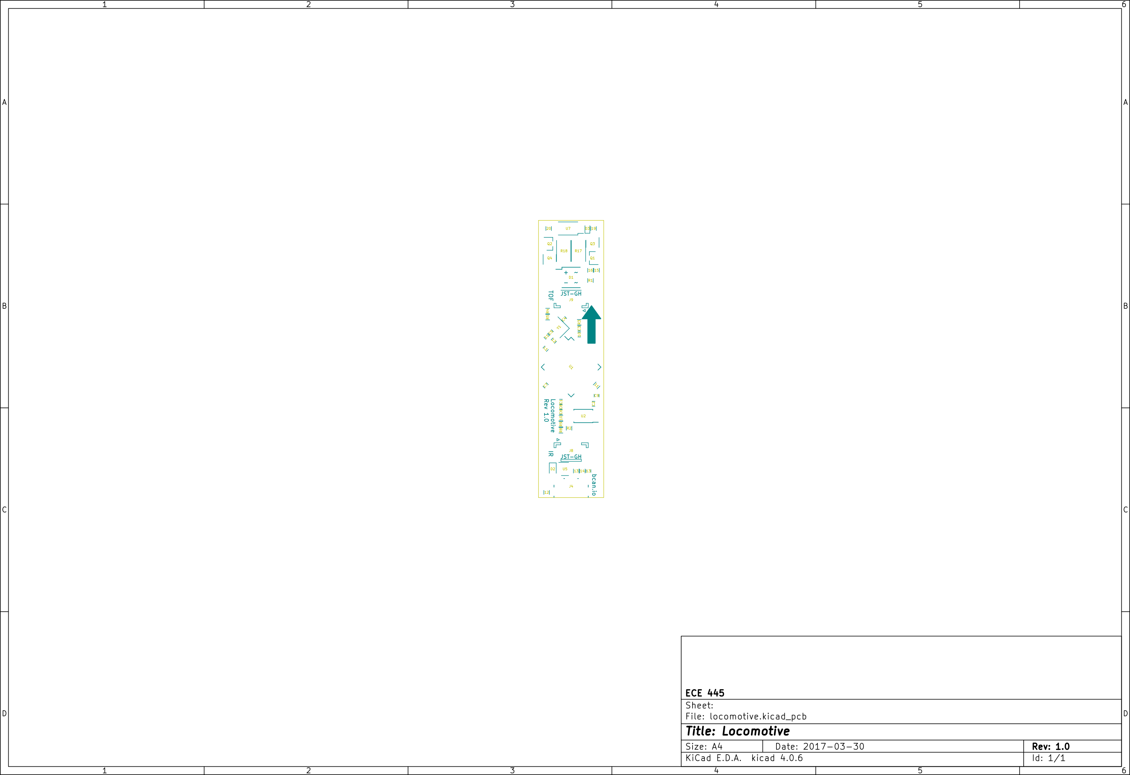
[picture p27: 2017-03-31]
electronics/locomotive/images/locomotive-F.SilkS.png

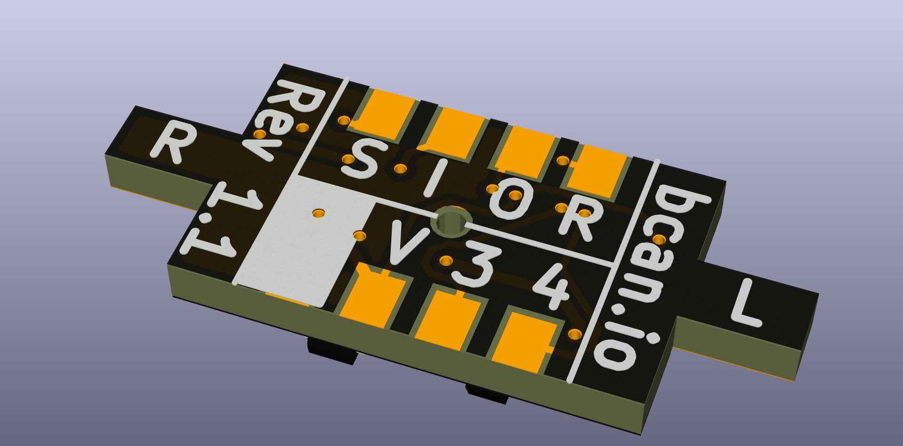
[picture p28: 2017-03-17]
electronics/beacon/v1.1/images/beacon_3d_back.png

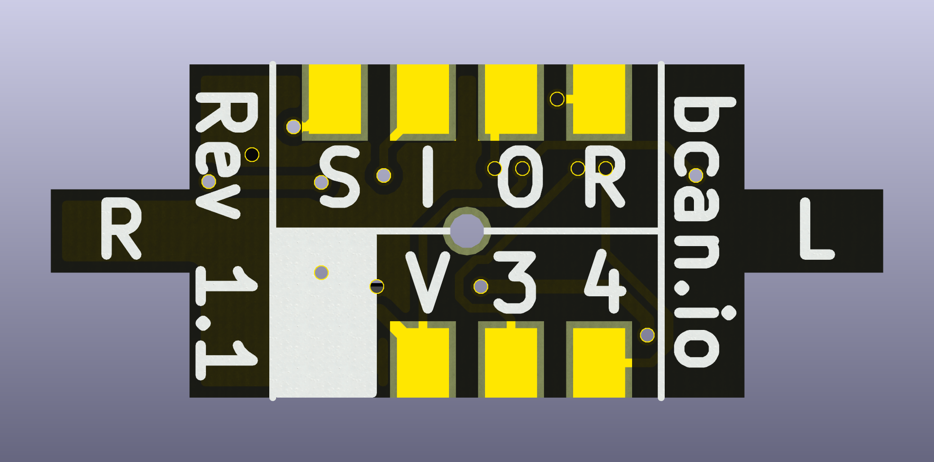
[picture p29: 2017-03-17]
electronics/beacon/v1.1/images/beacon_3d_bottom.png

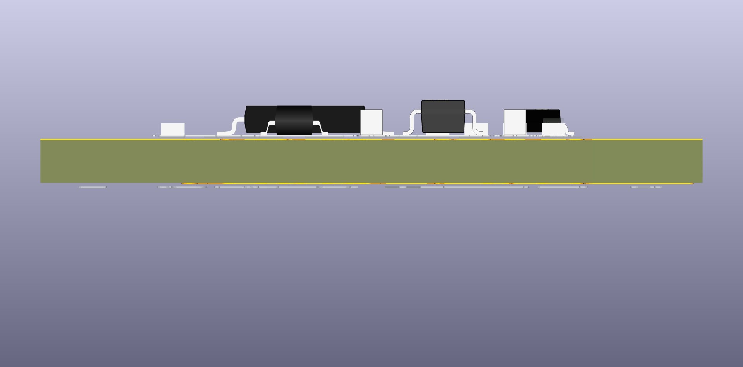
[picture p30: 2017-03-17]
electronics/beacon/v1.1/images/beacon_3d_side.png

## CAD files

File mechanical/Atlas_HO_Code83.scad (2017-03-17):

LENGTH  = 228.6;
TIE     = 2.48;
BETWEEN = LENGTH / 37; // 3.7
// 19.8, 15.8

module tie() {
  color("saddlebrown")
  cube([28.5, TIE, 2.15], true);
}
module rail() {
  color("saddlebrown")
  cube([1, LENGTH + TIE - BETWEEN * 3, 2.15], true);

  color("goldenrod")
  translate([0, 0, 2.1])
  union() {
    cube([0.6, LENGTH, 2.05], true);
    translate([0, 0, 0.525])
    cube([0.95, LENGTH, 1], true);
    translate([0, 0, -0.8])
    cube([2, LENGTH, 0.45], true);
  }
}
module track() {
  translate([0, 0, 2.15/2]) {
    //tie();
    for (i = [1:18]) {
      translate([0, i*BETWEEN, 0])
      tie();
      translate([0, -i*BETWEEN, 0])
      tie();
    }

    translate([8.725, 0, 0]) {
      rail();
    }
    translate([-8.725, 0, 0]) {
      rail();
    }
  }
}
// Rev 1.1
module beacon() {
  color("darkslategray")
  translate([0, 0, 0.8 + 0.55])
  union() {
    cube([16, 9.6, 1.6], true);
    cube([24, 2.4, 1.6], true);
  }
}

track();
beacon();

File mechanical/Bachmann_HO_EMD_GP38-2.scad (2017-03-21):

$fn = 36;

PCBwidth = 16;
PCBlength = 97;
PCBthickness = 0.8;

module screwHole() {
  cylinder(1, d = 2, center = true);
}

// Side tabs are 4mm long and 2.5mm wide
// Their cutouts are 4.5mm deep and 5.6mm wide
module sideTabs() {
  difference() {
    cube([18, 5.6, 1], true);
    cube([15, 2.5, 1.2], true);
    cube([7, 6, 1.2], true);
  }
}

module frontTabs() {
  difference() {
    cube([18, 5, 1], true);
    cube([4.8, 6, 1.2], true);
    translate([-5.2, 0, 0])
    cube([2.5, 6, 1.2], true);
    translate([5.2, 0, 0])
    cube([2.5, 6, 1.2], true);
  }
}

module PCB() {
  color("green")
  difference() {
    cube([PCBwidth, PCBlength, PCBthickness], true);
    translate([0, -PCBlength / 2, 0]) {
      translate([0, 7, 0])
      union() {
        cube([2, 1, 1], true);
        translate([0, -0.5, 0])
        cylinder(1, d = 2, center = true);
        translate([0, 0.5, 0])
        cylinder(1, d = 2, center = true);
      }
      translate([0, 12.8, 0])
      cylinder(1, d = 5, center = true);
      translate([0, 22.1, 0])
      sideTabs();
    }
    translate([0, PCBlength / 2, 0]) {
      translate([0, -24.8, 0])
      sideTabs();
      translate([0, -14.8, 0])
      sideTabs();
      translate([0, -9.8, 0])
      cylinder(1, d = 2, center = true);
      translate([0, -1.5, 0])
      frontTabs();
    }
  }
}

PCB();

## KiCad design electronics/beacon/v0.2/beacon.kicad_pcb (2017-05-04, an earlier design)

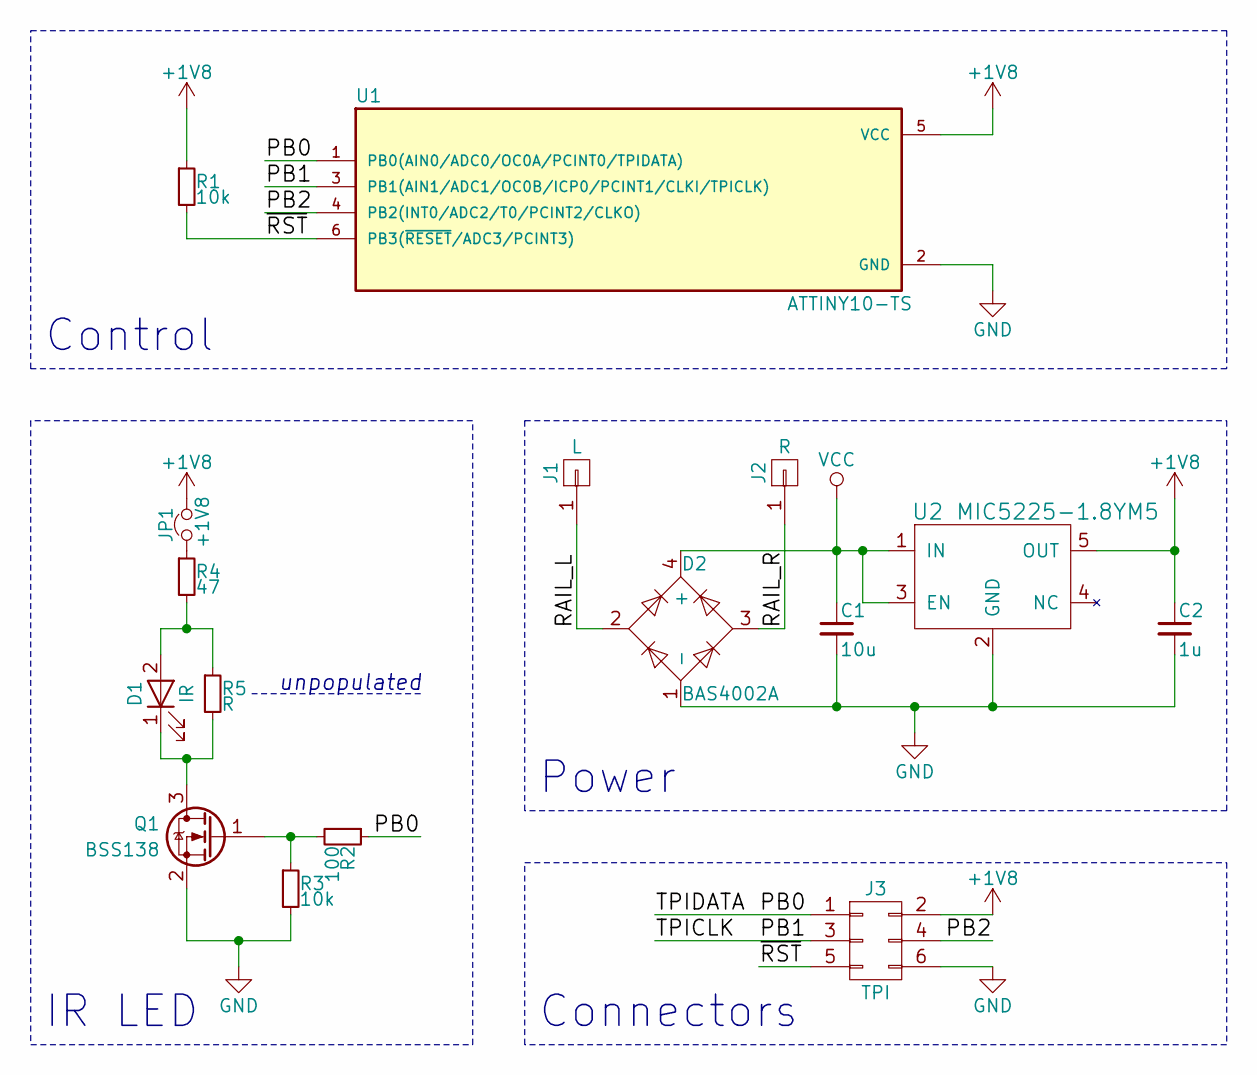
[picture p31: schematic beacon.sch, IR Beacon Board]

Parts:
C1: 10u; C_0603
C2: 1u; C_0603
D1: IR; LED_0603
D2: BAS4002A; SOT-143
J1: L; Pad_Length10mm_Width3.5mm
J2: R; Pad_Length10mm_Width3.5mm
J3: TPI; Pin_Header_Straight_2x03_Pitch2.54mm_SMD
JP1: +1V8; Solder_Jumper_NC_Small
Q1: BSS138; SOT-23
R1, R3: 10k; R_0603
R2: 100; R_0603
R4: 47; R_0603
R5: R; R_0603
U1: ATTINY10-TS; SOT-23-6
U2: MIC5225-1.8YM5; SOT-23-5

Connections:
+1V8: C2.1, J3.2, JP1.2, R1.1, U1.5 (VCC), U2.5 (OUT)
/PB0: J3.1, R2.1, U1.1 (PB0(AIN0/ADC0/OC0A/PCINT0/TPIDATA))
/PB1: J3.3, U1.3 (PB1(AIN1/ADC1/OC0B/ICP0/PCINT1/CLKI/TPI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)
/PB2: J3.4, U1.4 (PB2(INT0/ADC2/T0/PCINT2/CLKO))
/RAIL_L: D2.2, J1.1
/RAIL_R: D2.3, J2.1
/~RST: J3.5, R1.2, U1.6 (PB3(~RESET~/ADC3/PCINT3))
GND: C1.2, C2.2, D2.1 (-), J3.6, Q1.2 (S), R3.2, U1.2 (GND), U2.2 (GND)
unnamed: D1.1 (K), Q1.3 (D), R5.2
unnamed: D1.2 (A), R4.2, R5.1
unnamed: JP1.1, R4.1
unnamed: Q1.1 (G), R2.2, R3.1
VCC: C1.1, D2.4 (+), U2.1 (IN), U2.3 (EN)

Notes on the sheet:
unpopulated
Control
Power
IR LED
Connectors

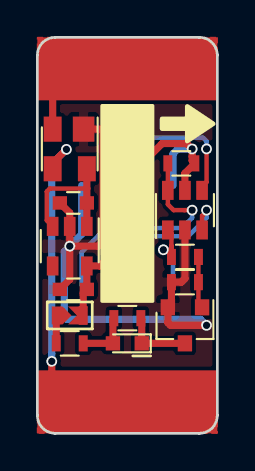
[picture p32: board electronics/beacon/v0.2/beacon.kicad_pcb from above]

Board: 2 copper layers, 10.0 x 22.0 mm, 16 parts (1 on the bottom side), 13 nets.

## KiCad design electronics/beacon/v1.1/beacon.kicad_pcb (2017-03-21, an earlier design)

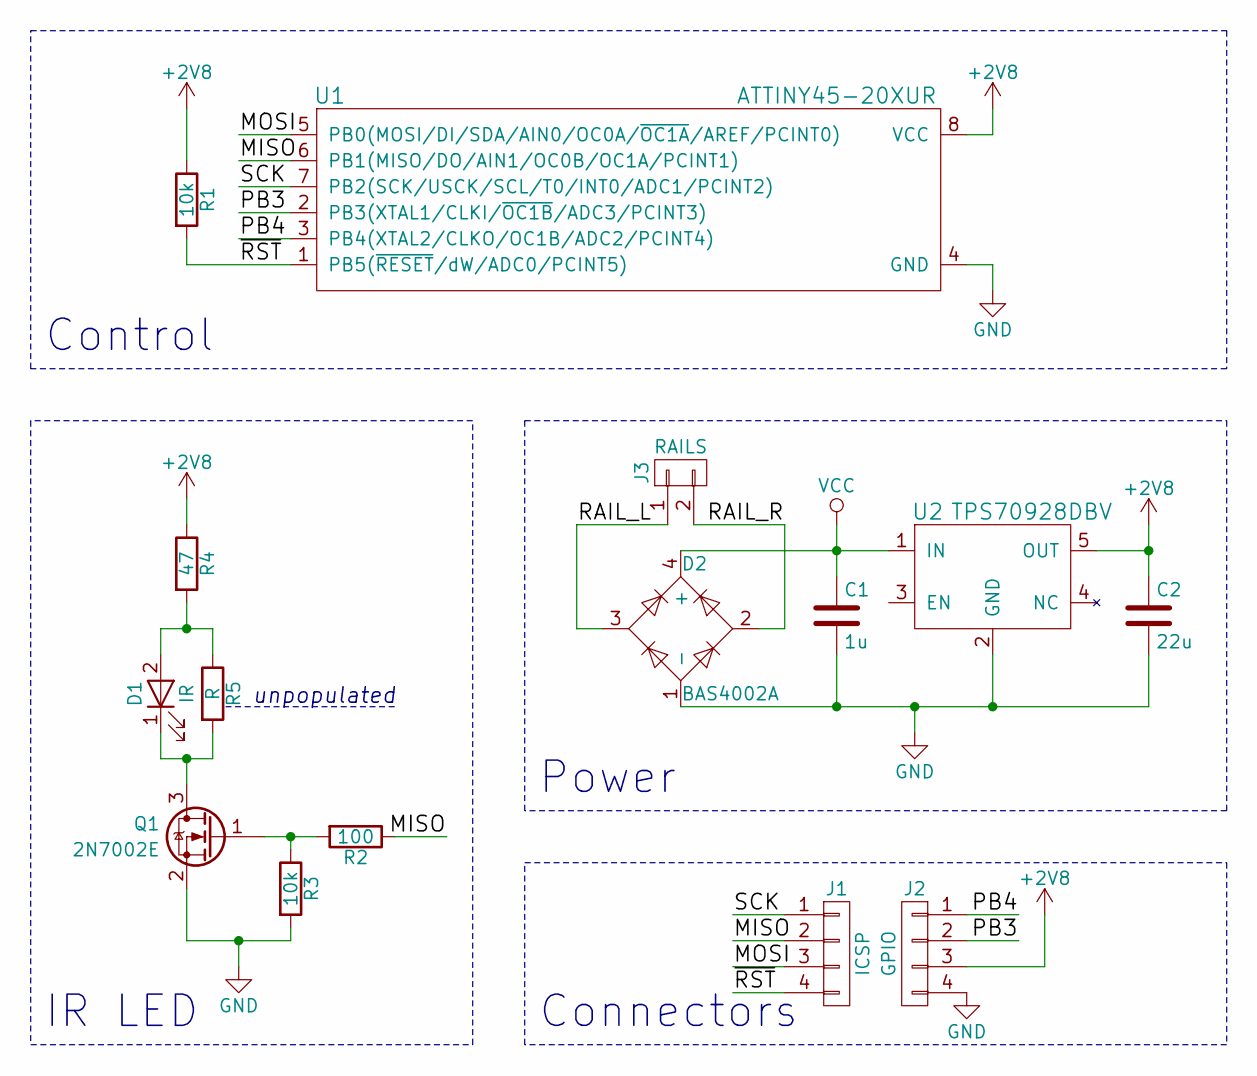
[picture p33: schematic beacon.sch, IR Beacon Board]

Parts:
C1: 1u; C_0603
C2: 22u; C_0603
D1: IR; LED_0603
D2: BAS4002A; SOT-143
J1: ICSP; Edge_Connector_1x04_Pitch2.54mm_SMD
J2: GPIO; Edge_Connector_1x04_Pitch2.54mm_SMD
J3: RAILS; HO_Rail_2_Length2.4mm_Width4mm
Q1: 2N7002E; SOT-23
R1, R3: 10k; R_0603
R2: 100; R_0603
R4: 47; R_0603
R5: R; R_0603
U1: ATTINY45-20XUR; TSSOP-8_4.4x3mm_Pitch0.65mm
U2: TPS70928DBV; SOT-23-5

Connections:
+2V8: C2.1, J2.3, R1.1, R4.1, U1.8 (VCC), U2.5 (OUT)
/MISO: J1.2, R2.1, U1.6 (PB1(MISO/DO/AIN1/OC0B/OC1A/PCINT1))
/MOSI: J1.3, U1.5 (PB0(MOSI/DI/SDA/AIN0/OC0A/~OC1A~/AREF/P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)
/PB3: J2.2, U1.2 (PB3(XTAL1/CLKI/~OC1B~/ADC3/PCINT3))
/PB4: J2.1, U1.3 (PB4(XTAL2/CLKO/OC1B/ADC2/PCINT4))
/RAIL_L: D2.3, J3.1
/RAIL_R: D2.2, J3.2
/SCK: J1.1, U1.7 (PB2(SCK/USCK/SCL/T0/INT0/ADC1/PCINT2))
/~RST: J1.4, R1.2, U1.1 (PB5(~RESET~/dW/ADC0/PCINT5))
GND: C1.2, C2.2, D2.1 (-), J2.4, Q1.2 (S), R3.2, U1.4 (GND), U2.2 (GND)
unnamed: D1.1 (K), Q1.3 (D), R5.2
unnamed: D1.2 (A), R4.2, R5.1
unnamed: Q1.1 (G), R2.2, R3.1
VCC: C1.1, D2.4 (+), U2.1 (IN)

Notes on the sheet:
unpopulated
Control
Power
IR LED
Connectors

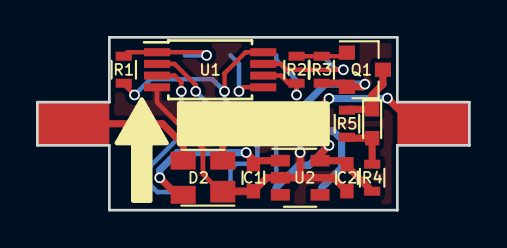
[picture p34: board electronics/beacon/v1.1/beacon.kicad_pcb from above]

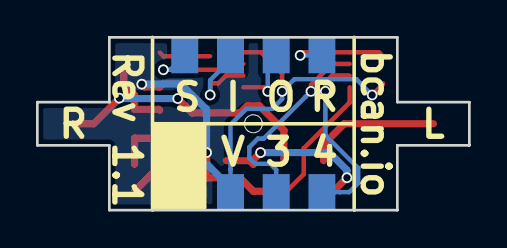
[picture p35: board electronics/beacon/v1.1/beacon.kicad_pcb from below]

Board: 2 copper layers, 24.0 x 9.6 mm, 15 parts (2 on the bottom side), 14 nets.

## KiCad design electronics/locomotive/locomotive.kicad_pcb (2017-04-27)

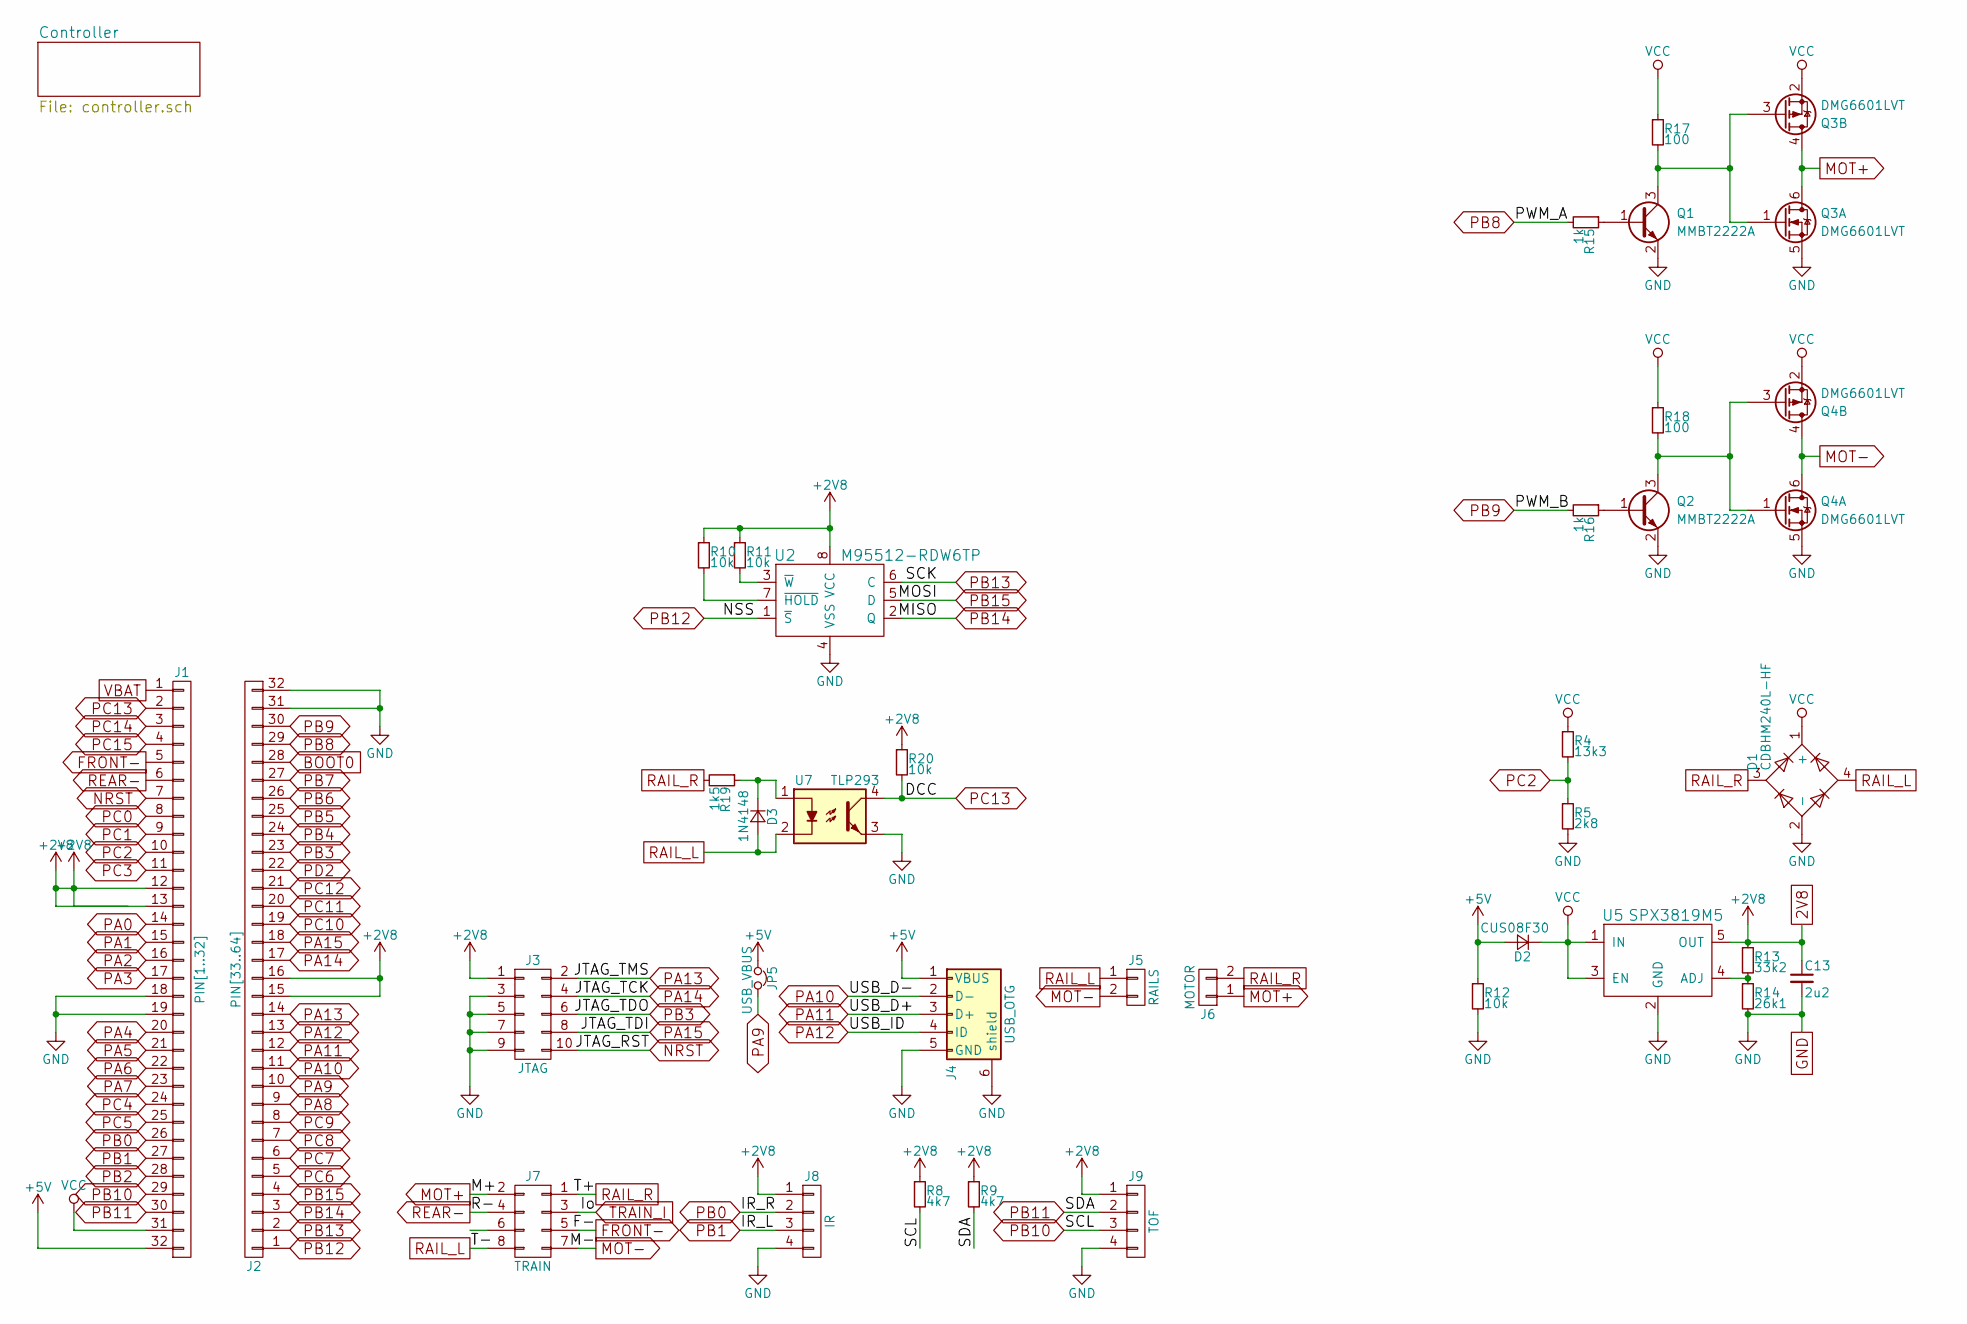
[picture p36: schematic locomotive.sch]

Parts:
C13: 2u2; C_0603
D1: CDBHM240L-HF; TO-269AA
D2: CUS08F30; D_SOD-323
D3: 1N4148; D_SOD-523
J1: PIN[1..32]; Castellations_1x32_Pitch2.00mm
J2: PIN[33..64]; Castellations_1x32_Pitch2.00mm
J3: JTAG; Pin_Header_Straight_2x05_Pitch1.27mm_SMD
J4: USB_OTG; USB_Micro-B_Amphenol_10118192
J5: RAILS; Castellations_1x02_Pitch2.00mm
J6: MOTOR; Castellations_1x02_Pitch2.00mm
J7: TRAIN; Pin_Header_Straight_2x04_Pitch2.54mm_SMD
J8: IR; JST_GH_BM04B-GHS-TBT_04x1.25mm_Straight
J9: TOF; JST_GH_SM04B-GHS-TB_04x1.25mm_Angled
JP5: USB_VBUS; Solder_Jumper_NC
Q1, Q2: MMBT2222A; SOT-23
Q3, Q4: DMG6601LVT; SOT-23-6
R4: 13k3; R_0603
R5: 2k8; R_0603
R8, R9: 4k7; R_0603
R10, R11, R12, R20: 10k; R_0603
R13: 33k2; R_0603
R14: 26k1; R_0603
R15, R16: 1k; R_0603
R17, R18: 100; R_2512
R19: 1k5; R_0603
U2: M95512-RDW6TP; TSSOP-8_4.4x3mm_Pitch0.65mm
U5: SPX3819M5; SOT-23-5
U7: TLP293; SOP-4_4.4x2.8mm_Pitch1.27mm

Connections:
2V8: C13.1, J1.12, J1.13, J2.15, J2.16, J3.1, J8.1, J9.1, R8.1, R9.1, R10.1, R11.1, R13.1, R20.1, U2.8 (VCC), U5.5 (OUT); also elsewhere on the board
+5V: D2.2 (A), J1.32, J4.1 (VBUS), JP5.1, R12.1
BOOT0: J2.28; also elsewhere on the board
FRONT-: J1.5, J7.5
GND: C13.2, D1.2 (-), J1.18, J1.19, J2.31, J2.32, J3.3, J3.5, J3.7, J3.9, J4.5 (GND), J4.6 (shield), J8.4, J9.4, Q1.2 (E), Q2.2 (E), Q3.5 (S), Q4.5 (S), R5.2, R12.2, R14.2, U2.4 (VSS), U5.2 (GND), U7.3; also elsewhere on the board
MOT+: J6.1, J7.2, Q3.4 (D), Q3.6 (D)
MOT-: J5.2, J7.7, Q4.4 (D), Q4.6 (D)
NRST: J1.7, J3.10; also elsewhere on the board
unnamed: D3.1 (K), R19.1, U7.1
unnamed: Q1.1 (B), R15.1
unnamed: Q1.3 (C), Q3.1 (G), Q3.3 (G), R17.2
unnamed: Q2.1 (B), R16.1
unnamed: Q2.3 (C), Q4.1 (G), Q4.3 (G), R18.2
unnamed: R10.2, U2.7 (~HOLD)
unnamed: R11.2, U2.3 (~W)
unnamed: R13.2, R14.1, U5.4 (ADJ)
PA0: J1.14; also elsewhere on the board
PA1: J1.15; also elsewhere on the board
PA2: J1.16; also elsewhere on the board
PA3: J1.17; also elsewhere on the board
PA4: J1.20; also elsewhere on the board
PA5: J1.21; also elsewhere on the board
PA6: J1.22; also elsewhere on the board
PA7: J1.23; also elsewhere on the board
PA8: J2.9; also elsewhere on the board
PA9: J2.10, JP5.2; also elsewhere on the board
PA10: J2.11, J4.2 (D-); also elsewhere on the board
PA11: J2.12, J4.3 (D+); also elsewhere on the board
PA12: J2.13, J4.4 (ID); also elsewhere on the board
PA13: J2.14, J3.2; also elsewhere on the board
PA14: J2.17, J3.4; also elsewhere on the board
PA15: J2.18, J3.8; also elsewhere on the board
PB0: J1.26, J8.2; also elsewhere on the board
PB1: J1.27, J8.3; also elsewhere on the board
PB2: J1.28; also elsewhere on the board
PB3: J2.23, J3.6; also elsewhere on the board
PB4: J2.24; also elsewhere on the board
PB5: J2.25; also elsewhere on the board
PB6: J2.26; also elsewhere on the board
PB7: J2.27; also elsewhere on the board
PB8: J2.29, R15.2; also elsewhere on the board
PB9: J2.30, R16.2; also elsewhere on the board
PB10: J1.29, J9.3, R8.2; also elsewhere on the board
PB11: J1.30, J9.2, R9.2; also elsewhere on the board
PB12: J2.1, U2.1 (~S); also elsewhere on the board
PB13: J2.2, U2.6 (C); also elsewhere on the board
PB14: J2.3, U2.2 (Q); also elsewhere on the board
PB15: J2.4, U2.5 (D); also elsewhere on the board
PC0: J1.8; also elsewhere on the board
PC1: J1.9; also elsewhere on the board
PC2: J1.10, R4.2, R5.1; also elsewhere on the board
PC3: J1.11; also elsewhere on the board
PC4: J1.24; also elsewhere on the board
PC5: J1.25; also elsewhere on the board
PC6: J2.5; also elsewhere on the board
PC7: J2.6; also elsewhere on the board
PC8: J2.7; also elsewhere on the board
PC9: J2.8; also elsewhere on the board
PC10: J2.19; also elsewhere on the board
PC11: J2.20; also elsewhere on the board
PC12: J2.21; also elsewhere on the board
PC13: J1.2, R20.2, U7.4; also elsewhere on the board
PC14: J1.3; also elsewhere on the board
PC15: J1.4; also elsewhere on the board
PD2: J2.22; also elsewhere on the board
RAIL_L: D1.4, D3.2 (A), J5.1, J7.8, U7.2
RAIL_R: D1.3, J6.2, J7.1, R19.2
REAR-: J1.6, J7.4
TRAIN_I: J7.3
VBAT: J1.1; also elsewhere on the board
VCC: D1.1 (+), D2.1 (K), J1.31, Q3.2 (S), Q4.2 (S), R4.1, R17.1, R18.1, U5.1 (IN), U5.3 (EN)

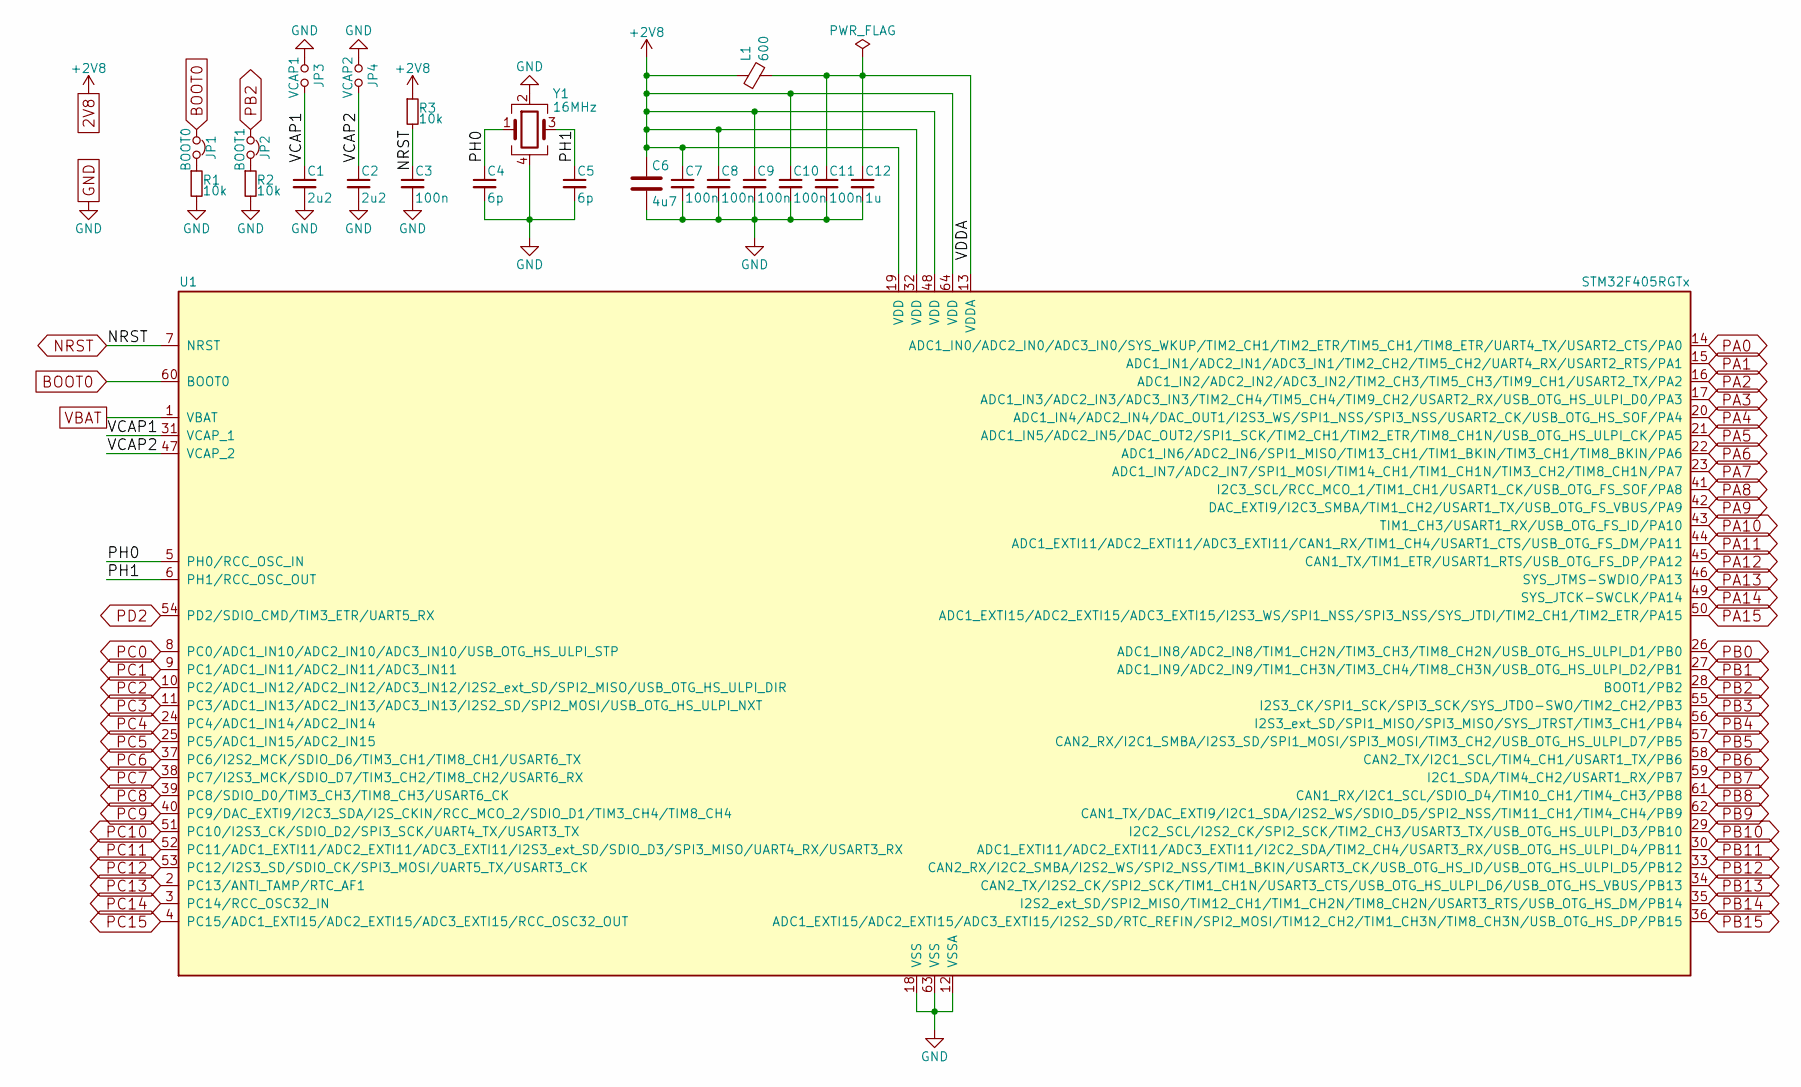
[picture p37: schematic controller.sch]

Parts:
C1, C2: 2u2; C_0603
C3, C7, C8, C9, C10, C11: 100n; C_0603
C4, C5: 6p; C_0603
C6: 4u7; C_0603
C12: 1u; C_0603
JP1: BOOT0; Solder_Jumper_NC
JP2: BOOT1; Solder_Jumper_NC
JP3: VCAP1; Solder_Jumper_NO
JP4: VCAP2; Solder_Jumper_NO
L1: 600; C_0603
R1, R2, R3: 10k; R_0603
U1: STM32F405RGTx; TQFP-64_10x10mm_Pitch0.5mm
Y1: 16MHz; Crystal_SMD_3225-4pin_3.2x2.5mm

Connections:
2V8: C6.1, C7.1, C8.1, C9.1, C10.1, L1.1, R3.1, U1.19 (VDD), U1.32 (VDD), U1.48 (VDD), U1.64 (VDD); also elsewhere on the board
/Controller/PH0: C4.1, U1.5 (PH0/RCC_OSC_IN), Y1.1
/Controller/PH1: C5.1, U1.6 (PH1/RCC_OSC_OUT), Y1.3
/Controller/VCAP1: C1.1, JP3.2, U1.31 (VCAP_1)
/Controller/VCAP2: C2.1, JP4.2, U1.47 (VCAP_2)
/Controller/VDDA: C11.1, C12.1, L1.2, U1.13 (VDDA)
BOOT0: JP1.1, U1.60 (BOOT0); also elsewhere on the board
GND: C1.2, C2.2, C3.2, C4.2, C5.2, C6.2, C7.2, C8.2, C9.2, C10.2, C11.2, C12.2, JP3.1, JP4.1, R1.2, R2.2, U1.12 (VSSA), U1.18 (VSS), U1.63 (VSS), Y1.2, Y1.4; also elsewhere on the board
NRST: C3.1, R3.2, U1.7 (NRST); also elsewhere on the board
unnamed: JP1.2, R1.1
unnamed: JP2.2, R2.1
PA0: U1.14 (ADC1_IN0/ADC2_IN0/ADC3_IN0/SYS_WKUP/TIM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); also elsewhere on the board
PA1: U1.15 (ADC1_IN1/ADC2_IN1/ADC3_IN1/TIM2_CH2/TIM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); also elsewhere on the board
PA2: U1.16 (ADC1_IN2/ADC2_IN2/ADC3_IN2/TIM2_CH3/TIM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); also elsewhere on the board
PA3: U1.17 (ADC1_IN3/ADC2_IN3/ADC3_IN3/TIM2_CH4/TIM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); also elsewhere on the board
PA4: U1.20 (ADC1_IN4/ADC2_IN4/DAC_OUT1/I2S3_WS/SPI1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); also elsewhere on the board
PA5: U1.21 (ADC1_IN5/ADC2_IN5/DAC_OUT2/SPI1_SCK/TIM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); also elsewhere on the board
PA6: U1.22 (ADC1_IN6/ADC2_IN6/SPI1_MISO/TIM13_CH1/T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); also elsewhere on the board
PA7: U1.23 (ADC1_IN7/ADC2_IN7/SPI1_MOSI/TIM14_CH1/T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); also elsewhere on the board
PA8: U1.41 (I2C3_SCL/RCC_MCO_1/TIM1_CH1/USART1_CK/U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); also elsewhere on the board
PA9: U1.42 (DAC_EXTI9/I2C3_SMBA/TIM1_CH2/USART1_TX/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); also elsewhere on the board
PA10: U1.43 (TIM1_CH3/USART1_RX/USB_OTG_FS_ID/PA10); also elsewhere on the board
PA11: U1.44 (ADC1_EXTI11/ADC2_EXTI11/ADC3_EXTI11/CAN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); also elsewhere on the board
PA12: U1.45 (CAN1_TX/TIM1_ETR/USART1_RTS/USB_OTG_FS_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); also elsewhere on the board
PA13: U1.46 (SYS_JTMS-SWDIO/PA13); also elsewhere on the board
PA14: U1.49 (SYS_JTCK-SWCLK/PA14); also elsewhere on the board
PA15: U1.50 (ADC1_EXTI15/ADC2_EXTI15/ADC3_EXTI15/I2S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); also elsewhere on the board
PB0: U1.26 (ADC1_IN8/ADC2_IN8/TIM1_CH2N/TIM3_CH3/TI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); also elsewhere on the board
PB1: U1.27 (ADC1_IN9/ADC2_IN9/TIM1_CH3N/TIM3_CH4/TI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); also elsewhere on the board
PB2: JP2.1, U1.28 (BOOT1/PB2); also elsewhere on the board
PB3: U1.55 (I2S3_CK/SPI1_SCK/SPI3_SCK/SYS_JTDO-SWO/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); also elsewhere on the board
PB4: U1.56 (I2S3_ext_SD/SPI1_MISO/SPI3_MISO/SYS_JTR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); also elsewhere on the board
PB5: U1.57 (CAN2_RX/I2C1_SMBA/I2S3_SD/SPI1_MOSI/SPI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); also elsewhere on the board
PB6: U1.58 (CAN2_TX/I2C1_SCL/TIM4_CH1/USART1_TX/PB6); also elsewhere on the board
PB7: U1.59 (I2C1_SDA/TIM4_CH2/USART1_RX/PB7); also elsewhere on the board
PB8: U1.61 (CAN1_RX/I2C1_SCL/SDIO_D4/TIM10_CH1/TIM4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); also elsewhere on the board
PB9: U1.62 (CAN1_TX/DAC_EXTI9/I2C1_SDA/I2S2_WS/SDIO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); also elsewhere on the board
PB10: U1.29 (I2C2_SCL/I2S2_CK/SPI2_SCK/TIM2_CH3/USAR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); also elsewhere on the board
PB11: U1.30 (ADC1_EXTI11/ADC2_EXTI11/ADC3_EXTI11/I2C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); also elsewhere on the board
PB12: U1.33 (CAN2_RX/I2C2_SMBA/I2S2_WS/SPI2_NSS/TIM1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); also elsewhere on the board
PB13: U1.34 (CAN2_TX/I2S2_CK/SPI2_SCK/TIM1_CH1N/USAR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); also elsewhere on the board
PB14: U1.35 (I2S2_ext_SD/SPI2_MISO/TIM12_CH1/TIM1_CH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); also elsewhere on the board
PB15: U1.36 (ADC1_EXTI15/ADC2_EXTI15/ADC3_EXTI15/I2S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); also elsewhere on the board
PC0: U1.8 (PC0/ADC1_IN10/ADC2_IN10/ADC3_IN10/USB_O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); also elsewhere on the board
PC1: U1.9 (PC1/ADC1_IN11/ADC2_IN11/ADC3_IN11); also elsewhere on the board
PC2: U1.10 (PC2/ADC1_IN12/ADC2_IN12/ADC3_IN12/I2S2_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); also elsewhere on the board
PC3: U1.11 (PC3/ADC1_IN13/ADC2_IN13/ADC3_IN13/I2S2_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); also elsewhere on the board
PC4: U1.24 (PC4/ADC1_IN14/ADC2_IN14); also elsewhere on the board
PC5: U1.25 (PC5/ADC1_IN15/ADC2_IN15); also elsewhere on the board
PC6: U1.37 (PC6/I2S2_MCK/SDIO_D6/TIM3_CH1/TIM8_CH1/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); also elsewhere on the board
PC7: U1.38 (PC7/I2S3_MCK/SDIO_D7/TIM3_CH2/TIM8_CH2/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); also elsewhere on the board
PC8: U1.39 (PC8/SDIO_D0/TIM3_CH3/TIM8_CH3/USART6_CK); also elsewhere on the board
PC9: U1.40 (PC9/DAC_EXTI9/I2C3_SDA/I2S_CKIN/RCC_MCO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); also elsewhere on the board
PC10: U1.51 (PC10/I2S3_CK/SDIO_D2/SPI3_SCK/UART4_TX/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); also elsewhere on the board
PC11: U1.52 (PC11/ADC1_EXTI11/ADC2_EXTI11/ADC3_EXTI1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); also elsewhere on the board
PC12: U1.53 (PC12/I2S3_SD/SDIO_CK/SPI3_MOSI/UART5_TX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); also elsewhere on the board
PC13: U1.2 (PC13/ANTI_TAMP/RTC_AF1); also elsewhere on the board
PC14: U1.3 (PC14/RCC_OSC32_IN); also elsewhere on the board
PC15: U1.4 (PC15/ADC1_EXTI15/ADC2_EXTI15/ADC3_EXTI1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); also elsewhere on the board
PD2: U1.54 (PD2/SDIO_CMD/TIM3_ETR/UART5_RX); also elsewhere on the board
VBAT: U1.1 (VBAT); also elsewhere on the board

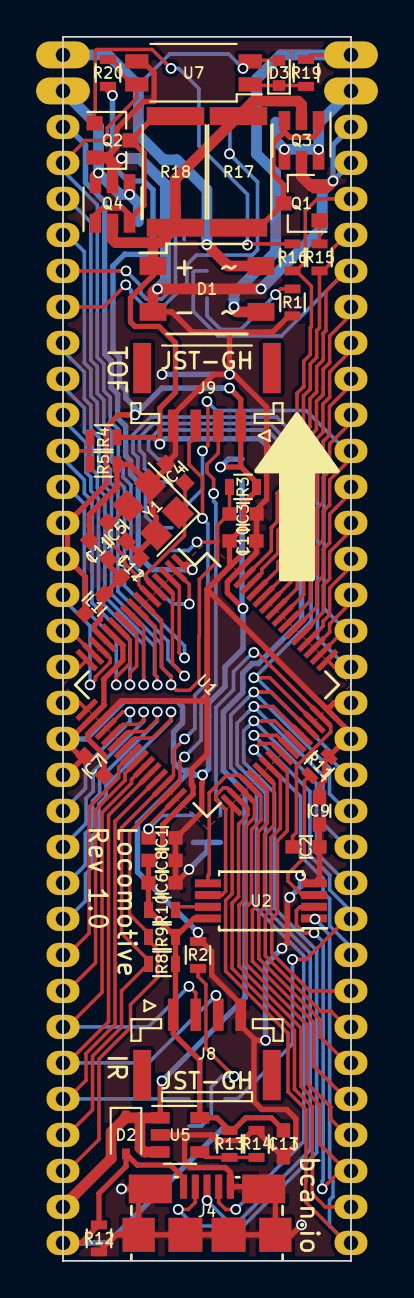
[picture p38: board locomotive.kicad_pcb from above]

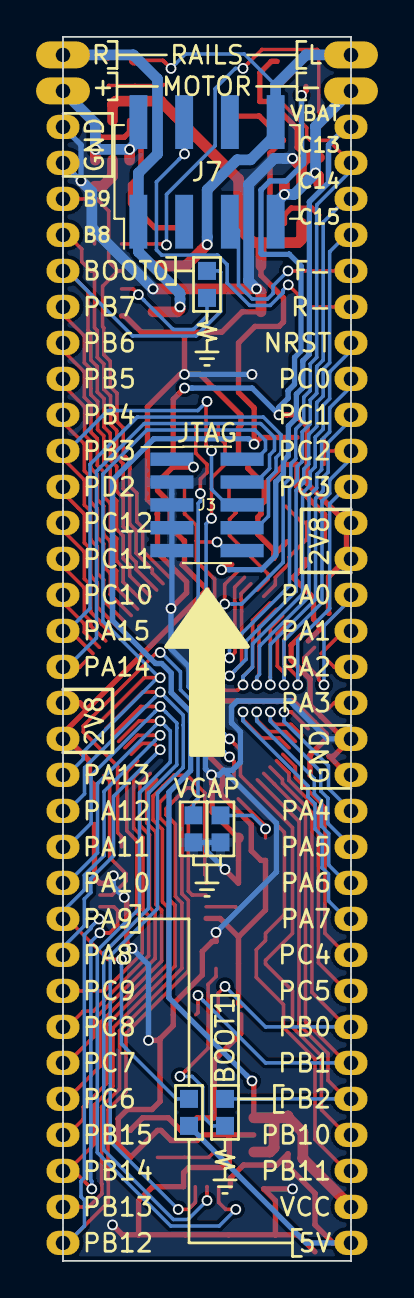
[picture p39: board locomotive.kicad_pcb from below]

Board: 2 copper layers, 16.0 x 68.0 mm, 58 parts (7 on the bottom side), 77 nets.

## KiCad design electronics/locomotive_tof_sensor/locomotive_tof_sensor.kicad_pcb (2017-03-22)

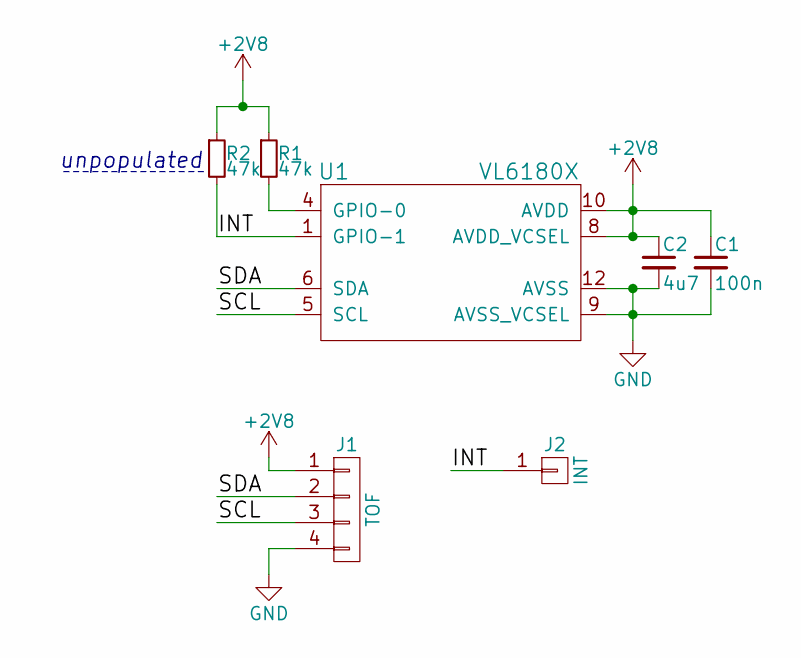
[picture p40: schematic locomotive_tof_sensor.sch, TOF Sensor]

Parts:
C1: 100n; C_0603
C2: 4u7; C_0603
J1: TOF; JST_GH_BM04B-GHS-TBT_04x1.25mm_Straight
J2: INT; Measurement_Point_Square-SMD-Pad_Small
R1, R2: 47k; R_0603
U1: VL6180X

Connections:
+2V8: C1.1, C2.1, J1.1, R1.1, R2.1, U1.8 (AVDD_VCSEL), U1.10 (AVDD)
/INT: J2.1, R2.2, U1.1 (GPIO-1)
/SCL: J1.3, U1.5 (SCL)
/SDA: J1.2, U1.6 (SDA)
GND: C1.2, C2.2, J1.4, U1.9 (AVSS_VCSEL), U1.12 (AVSS)
unnamed: R1.2, U1.4 (GPIO-0)

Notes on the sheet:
unpopulated

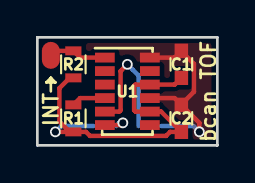
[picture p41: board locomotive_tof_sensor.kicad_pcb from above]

Board: 2 copper layers, 10.0 x 6.0 mm, 7 parts (1 on the bottom side), 6 nets.

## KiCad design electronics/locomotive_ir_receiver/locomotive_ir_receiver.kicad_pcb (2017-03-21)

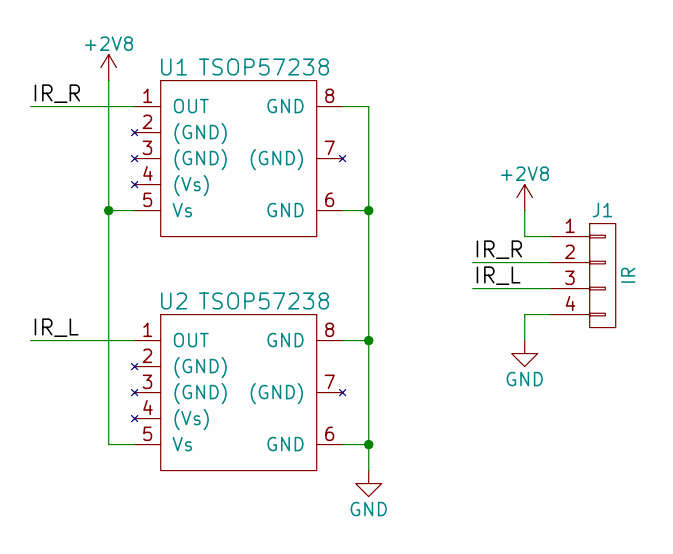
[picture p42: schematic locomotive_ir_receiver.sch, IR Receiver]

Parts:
J1: IR; JST_GH_SM04B-GHS-TB_04x1.25mm_Angled
U1, U2: TSOP57238; TSOP572xx

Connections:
+2V8: J1.1, U1.5 (Vs), U2.5 (Vs)
/IR_L: J1.3, U2.1 (OUT)
/IR_R: J1.2, U1.1 (OUT)
GND: J1.4, U1.6 (GND), U1.8 (GND), U2.6 (GND), U2.8 (GND)


Board: 2 copper layers, 20.0 x 32.0 mm, 3 parts (0 on the bottom side), 4 nets.

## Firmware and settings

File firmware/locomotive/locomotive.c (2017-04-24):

#include <libopencm3/cm3/nvic.h>
#include <libopencm3/cm3/systick.h>
#include <libopencm3/stm32/rcc.h>
#include <libopencm3/stm32/gpio.h>
#include <libopencm3/stm32/usart.h>

#include "locomotive.h"
#include "rcc_config/rcc_config.h"
#include "led/led.h"
#include "beacon/beacon.h"
#include "motor/motor.h"
#include "tof/tof.h"

#define TX_PIN PA2
#define RX_PIN PA3

#define ID_0 0xca53
#define ID_1 0xa257
#define ID_2 0x5e72
#define ID_3 0x3f44
#define ID_4 0x92e0
#define ID_5 0x463c
#define ID_6 0x5c5d
#define ID_7 0x0de0
#define ID_8 0x1a32
#define ID_9 0x547d

#define DOT_FORWARD 1
#define DOT_REVERSE 2
#define DOT_EITHER  3

#define DIR_FORWARD 1
#define DIR_REVERSE 2
#define DIR_EITHER  3

#define INSTR_F0        0
#define INSTR_F1        1
#define INSTR_F2        2
#define INSTR_F3        3
#define INSTR_F4        4
#define INSTR_F5        5
#define INSTR_F6        6
#define INSTR_F7        7
#define INSTR_F8        8
#define INSTR_F9        9
#define INSTR_F10       10
#define INSTR_F11       11
#define INSTR_F12       12
#define INSTR_F13       13
#define INSTR_F14       14
#define INSTR_F15       15
#define INSTR_F16       16
#define INSTR_F17       17
#define INSTR_F18       18
#define INSTR_F19       19
#define INSTR_F20       20
#define INSTR_F21       21
#define INSTR_F22       22
#define INSTR_F23       23
#define INSTR_F24       24
#define INSTR_F25       25
#define INSTR_F26       26
#define INSTR_F27       27
#define INSTR_F28       28
#define INSTR_SPEED     29
#define INSTR_DIRECTION 30
#define INSTR_CUSTOM    31

#define DATA_REVERSE_DIR 0
#define DATA_FORWARD_DIR 1
#define DATA_REVERSE_DOT 2
#define DATA_FORWARD_DOT 3
#define DATA_CHANGE_DIR  4

#define NUM_MAPPINGS 16

#define TOF_TRIGGER_DISTANCE 50


typedef struct {
	uint16_t id : 16;
	uint8_t dot : 2;
	uint8_t dir : 2;
	uint8_t instr : 5;
	uint8_t data : 7;
} mapping_t;

const mapping_t mappings[NUM_MAPPINGS] = {
	{
		.id    = ID_0,
		.dot   = DIR_EITHER,
		.dir   = DIR_EITHER,
		.instr = INSTR_SPEED,
		.data  = 127
	}
};

char print_buffer[50];

/* Number of milliseconds since reset (overflows every 49 days). */
volatile uint32_t system_millis;


void sys_tick_handler(void) {
	system_millis++;
}

static void rcc_setup(void) {
	/* Enable system clock at 168MHz. */
	rcc_clock_setup_hse_3v3(&rcc_hse_16mhz_2v7_to_3v6[RCC_CLOCK_3V3_168MHZ]);
}

static void gpio_setup(void) {
	/* Enable GPIOA clock. */
	rcc_periph_clock_enable(RCC_GPIOA);
	/* Enable GPIOB clock. */
	rcc_periph_clock_enable(RCC_GPIOB);
	/* Enable GPIOC clock. */
	rcc_periph_clock_enable(RCC_GPIOC);
}

static void systick_setup(void) {
	/* Enable 1ms system tick interrupt rate. */
	systick_set_frequency(1000, rcc_ahb_frequency);
	systick_clear();
	systick_counter_enable();
	systick_interrupt_enable();
}

static void usart_setup(void) {
	/* Setup GPIO pins for USART2 transmit. */
	gpio_mode_setup(PORT(TX_PIN), GPIO_MODE_AF, GPIO_PUPD_NONE, PIN(TX_PIN));

	/* Setup USART2 TX pin as alternate function. */
	gpio_set_af(PORT(TX_PIN), GPIO_AF7, PIN(TX_PIN));

	/* Enable clocks for USART2. */
	rcc_periph_clock_enable(RCC_USART2);

	/* Setup USART2 parameters. */
	usart_set_baudrate(USART2, 38400);
	usart_set_databits(USART2, 8);
	usart_set_stopbits(USART2, USART_STOPBITS_1);
	usart_set_mode(USART2, USART_MODE_TX);
	usart_set_parity(USART2, USART_PARITY_NONE);
	usart_set_flow_control(USART2, USART_FLOWCONTROL_NONE);

	/* Finally enable the USART. */
	usart_enable(USART2);
}

void print(char *str) {
	uint8_t i = 0;
	while (str[i] != '\0') {
		usart_send_blocking(USART2, str[i]);
		i++;
	}
}

void println(char *str) {
	print(str);
	usart_send_blocking(USART2, '\n');
}

int main(void) {
	rcc_setup();
	gpio_setup();
	systick_setup();
	usart_setup();

	led_setup(LED_FRONT);
	led_setup(LED_REAR);
	beacon_setup();
	motor_setup();
	tof_setup();

	while (1) {
		motor_update();

		if (tof_distance() <= TOF_TRIGGER_DISTANCE) {
			motor_stop();
		} else {
			motor_start();

			if (beacon_available()) {
				beacon_t beacon = beacon_parse();
				uint8_t dot = motor_get_direction() ^ beacon.side ^ 1;
				uint8_t dir = motor_get_direction();

				sprintf(print_buffer, "0x%04x", beacon.id);
				println(print_buffer);

				/* Find all matching mappings. */
				for (uint8_t i = 0; i < NUM_MAPPINGS; i++) {
					if ((beacon.id == mappings[i].id) &&
							(dot & mappings[i].dot) &&
							(dir & mappings[i].dir)) {
						uint8_t data = mappings[i].data;

						switch (mappings[i].instr) {
							/* Turn on LED. */
							case INSTR_F0:
								if (data == 0) {
									led_on(LED_FRONT);
								} else if (data == 1) {
									led_on(LED_REAR);
								}
								break;
							/* Turn off LED. */
							case INSTR_F1:
								if (data == 0) {
									led_off(LED_FRONT);
								} else if (data == 1) {
									led_off(LED_REAR);
								}
								break;
							/* Toggle LED. */
							case INSTR_F2:
								if (data == 0) {
									led_toggle(LED_FRONT);
								} else if (data == 1) {
									led_toggle(LED_REAR);
								}
								break;
							case INSTR_F3:
							case INSTR_F4:
							case INSTR_F5:
							case INSTR_F6:
							case INSTR_F7:
							case INSTR_F8:
							case INSTR_F9:
							case INSTR_F10:
							case INSTR_F11:
							case INSTR_F12:
							case INSTR_F13:
							case INSTR_F14:
							case INSTR_F15:
							case INSTR_F16:
							case INSTR_F17:
							case INSTR_F18:
							case INSTR_F19:
							case INSTR_F20:
							case INSTR_F21:
							case INSTR_F22:
							case INSTR_F23:
							case INSTR_F24:
							case INSTR_F25:
							case INSTR_F26:
							case INSTR_F27:
							case INSTR_F28:
								break;
							case INSTR_SPEED:
								motor_set_speed(data);
								break;
							case INSTR_DIRECTION:
								if (data == DATA_REVERSE_DIR) {
									motor_set_direction(MOTOR_REVERSE);
								} else if (data == DATA_FORWARD_DIR) {
									motor_set_direction(MOTOR_FORWARD);
								} else if (((data == DATA_REVERSE_DOT) && (dot == DOT_FORWARD)) ||
													 ((data == DATA_FORWARD_DOT) && (dot == DOT_REVERSE)) ||
														(data == DATA_CHANGE_DIR)) {
									motor_set_direction(dir ^ (MOTOR_FORWARD | MOTOR_REVERSE));
								}
								break;
							case INSTR_CUSTOM:
							default:
								break;
						}
					}
				}
			}
		}

		if (system_millis % 500 == 0) {
			sprintf(print_buffer, "Track Voltage: %d0mV", motor_vtrack());
			println(print_buffer);
		}
	}

	return 0;
}

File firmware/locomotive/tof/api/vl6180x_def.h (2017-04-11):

/*******************************************************************************
Copyright � 2014, STMicroelectronics International N.V.
All rights reserved.

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
THIS SOFTWARE IS PROVIDED BY THE COPYRIGHT HOLDERS AND CONTRIBUTORS "AS IS" AND
ANY EXPRESS OR IMPLIED WARRANTIES, INCLUDING, BUT NOT LIMITED TO, THE IMPLIED
WARRANTIES OF MERCHANTABILITY, FITNESS FOR A PARTICULAR PURPOSE, AND
NON-INFRINGEMENT OF INTELLECTUAL PROPERTY RIGHTS ARE DISCLAIMED. 
IN NO EVENT SHALL STMICROELECTRONICS INTERNATIONAL N.V. BE LIABLE FOR ANY
DIRECT, INDIRECT, INCIDENTAL, SPECIAL, EXEMPLARY, OR CONSEQUENTIAL DAMAGES
(INCLUDING, BUT NOT LIMITED TO, PROCUREMENT OF SUBSTITUTE GOODS OR SERVICES;
LOSS OF USE, DATA, OR PROFITS; OR BUSINESS INTERRUPTION) HOWEVER CAUSED AND
ON ANY THEORY OF LIABILITY, WHETHER IN CONTRACT, STRICT LIABILITY, OR TORT
(INCLUDING NEGLIGENCE OR OTHERWISE) ARISING IN ANY WAY OUT OF THE USE OF THIS
SOFTWARE, EVEN IF ADVISED OF THE POSSIBILITY OF SUCH DAMAGE.
********************************************************************************/

/*
 * $Date: 2015-04-01 16:49:50 +0200 (Wed, 01 Apr 2015) $
 * $Revision: 2235 $
 */

/**
 * @file VL6180x_def.h
 *
 * @brief Type definitions for vl6180x api.
 *
 */


#ifndef _VL6180x_DEF
#define _VL6180x_DEF

/** API major version */
#define VL6180x_API_REV_MAJOR   3
/** API minor version */
#define VL6180x_API_REV_MINOR   0
/** API sub version */
#define VL6180x_API_REV_SUB     0

#define VL6180X_STR_HELPER(x) #x
#define VL6180X_STR(x) VL6180X_STR_HELPER(x)

#include "vl6180x_platform.h"
#include "vl6180x_cfg.h"
#include "vl6180x_types.h"

/*
 * check configuration macro raise error or warning and suggest a default value
 */

#ifndef VL6180x_UPSCALE_SUPPORT
#error "VL6180x_UPSCALE_SUPPORT not defined"
/* TODO you must define value for  upscale support in your vl6180x_cfg.h  */
#endif

#ifndef VL6180x_ALS_SUPPORT
#error "VL6180x_ALS_SUPPORT not defined"
/* TODO you must define VL6180x_ALS_SUPPORT  with a value in your vl6180x_cfg.h  set to 0 do disable*/
#endif

#ifndef VL6180x_HAVE_DMAX_RANGING
#error "VL6180x_HAVE_DMAX_RANGING not defined"
/* TODO you may remove or comment these #error and keep the default below  or update your vl6180x_cfg.h .h file */
/**
 * force VL6180x_HAVE_DMAX_RANGING to not supported when not part of cfg file
 */
#define VL6180x_HAVE_DMAX_RANGING   0
#endif

#ifndef VL6180x_EXTENDED_RANGE
#define VL6180x_EXTENDED_RANGE   0
#endif

#ifndef  VL6180x_WRAP_AROUND_FILTER_SUPPORT
#error "VL6180x_WRAP_AROUND_FILTER_SUPPORT not defined ?"
/* TODO you may remove or comment these #error and keep the default below  or update vl6180x_cfg.h file */
/**
 * force VL6180x_WRAP_AROUND_FILTER_SUPPORT to not supported when not part of cfg file
 */
#define VL6180x_WRAP_AROUND_FILTER_SUPPORT 0
#endif




/****************************************
 * PRIVATE define do not edit
 ****************************************/

/** Maximal buffer size ever use in i2c */
#define VL6180x_MAX_I2C_XFER_SIZE   8 /* At present time it 6 byte max but that can change */

#if VL6180x_UPSCALE_SUPPORT < 0
/**
 * @def VL6180x_HAVE_UPSCALE_DATA
 * @brief  is defined if device data structure has data so when user configurable up-scale is active
 */
#define VL6180x_HAVE_UPSCALE_DATA /* have data only for user configurable up-scale config */
#endif

#if VL6180x_WRAP_AROUND_FILTER_SUPPORT
/**
 * @def VL6180x_HAVE_WRAP_AROUND_DATA
 * @brief  is defined if device data structure has filter data so when active in cfg file
 */
#define  VL6180x_HAVE_WRAP_AROUND_DATA
#endif

#if VL6180x_ALS_SUPPORT != 0
/**
 * @def  VL6180x_HAVE_ALS_DATA
 * @brief is defined when als data are include in device data structure so when als suport if configured
 */
#define VL6180x_HAVE_ALS_DATA
#endif


#if VL6180x_WRAP_AROUND_FILTER_SUPPORT || VL6180x_HAVE_DMAX_RANGING
	#define	VL6180x_HAVE_RATE_DATA
#endif

/** Error and warning code returned by API
 *
 * negative value are true error mostly fatal\n
 * positive value  are warning most of time it's ok to continue\n
 */
enum VL6180x_ErrCode_t{
	API_NO_ERROR        = 0,
    CALIBRATION_WARNING = 1,  /*!< warning invalid calibration data may be in used \a  VL6180x_InitData() \a VL6180x_GetOffsetCalibrationData \a VL6180x_SetOffsetCalibrationData*/
    MIN_CLIPED          = 2,  /*!< warning parameter passed was clipped to min before to be applied */
    NOT_GUARANTEED      = 3,  /*!< Correct operation is not guaranteed typically using extended ranging on vl6180x */
    NOT_READY           = 4,  /*!< the data is not ready retry */

    API_ERROR      = -1,    /*!< Unqualified error */
    INVALID_PARAMS = -2,    /*!< parameter passed is invalid or out of range */
    NOT_SUPPORTED  = -3,    /*!< function is not supported in current mode or configuration */
    RANGE_ERROR    = -4,    /*!< device report a ranging error interrupt status */
    TIME_OUT       = -5,    /*!< aborted due to time out */
};
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

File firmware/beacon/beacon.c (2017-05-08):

//============================================================================//
//                               Atmel ATtiny10                               //
//                                   ,----,                                   //
//       (PCINT0/TPIDATA/OC0A) PB0 ==|1  6|== PB3 (~RESET/PCINT3)             //
//                             GND ==|2  5|== VCC                             //
//   (PCINT1/TPICLK/ICP0/OC0B) PB1 ==|3  4|== PB2 (T0/PCINT2/INT0)            //
//                                   '----'                                   //
//============================================================================//

// #define __AVR_ATtiny10__
#define F_CPU   8000000UL // CPU frequency = 8MHz
#define F_PWM   38000     // PWM frequency = 38kHz
#define PERIOD  10        // One period = 960us = 96us * 10
#define LED_PIN 0         // PB0

#include <stdint.h>
#include <avr/io.h>
#include <util/delay.h>


// Delay for some multiple of 96 microseconds (max for _delay_us() at 8MHz)
static void delay(uint8_t n) {
	for (uint8_t i = 0; i < n; i++) {
		_delay_us(96);
	}
}

// Enable PWM on PB0
static void pwm_on(uint8_t n) {
	// Compare Match Output A mode
	//    COM0A = 01: toggle OC0A on compare match
	TCCR0A |= _BV(COM0A0);
	delay(n);
}

// Disable PWM on PB0
static void pwm_off(uint8_t n) {
	// Compare Match Output A mode
	//    COM0A = 00: disconnect OC0A
	TCCR0A &= ~_BV(COM0A0);
	delay(n);
}

int main(void) {
	// Set CPU speed to 8MHz by setting clock prescaler
	// CCP register must first be written with the correct signature - 0xD8
	CCP = 0xD8;
	// Set the clock division factor
	// CLKPS[3:0]: Clock Prescaler Select = 0000 (1)
	CLKPSR = 0;

	// Optionally set a custom oscillator calibration value
	// OSCCAL = oscillator_calibration_value;

	// Set PB0 as an output (function OC0A), and all others as inputs
	DDRB  =  _BV(LED_PIN);
	// Drive PB0 low, and enable pull-ups for all others (saves power)
	PORTB = ~_BV(LED_PIN);

	// Set the Timer/Counter Control Registers for Timer/Counter 0
	//
	// Compare Match Output A mode
	//    COM0A = 00: disconnect OC0A
	// Compare Match Output B mode
	//    COM0B = 00: disconnect OC0B
	// Waveform Generation Mode
	//    WGM0 = 1111: fast PWM with OCR0A as top (Mode 15)
	// Clock Select
	//    CS0 = 001: no prescaling
	TCCR0A = _BV(WGM01) | _BV(WGM00);
	TCCR0B = _BV(WGM03) | _BV(WGM02) | _BV(CS00);

	// Set the Output Compare Registers for Timer/Counter 0
	// Output Compare Register A (OCR0A): top value for timer, 50% duty cycle
	OCR0AL = F_CPU / F_PWM / 2 - 1;

	while (1) {
		// Start of message
		pwm_on(PERIOD * 3);
		pwm_off(PERIOD);

		// Transmit the unique ID using manchester code, MSB first
		// 0 - rising edge
		// 1 - falling edge
		for (int8_t i = LENGTH - 1; i >= 0; i--) {
			uint32_t bit = (ID >> i) & 1;
			for (uint8_t clk = 0; clk <= 1; clk++) {
				if (clk ^ bit) {
					pwm_on(PERIOD / 2);
				} else {
					pwm_off(PERIOD / 2);
				}
			}
		}

		// End of message
		pwm_off(PERIOD * 4);
	}

	return 0;
}

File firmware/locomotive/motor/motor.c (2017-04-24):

#include "motor.h"

/* Voltage corresponding with maximum speed. Typically 12V at the motor. */
#define V_MAX_SPEED     12
/* Max track voltage for voltage divider = 16.1V */
#define V_DIVIDER_MAX   16
/* Frequency of PWM output. Higher values tend to be smoother (e.g. 10kHz). */
#define PWM_FREQUENCY   10000
/* 42MHz */
#define TIMER_FREQUENCY 42000000
/* PWM/timer frequencies must be chosen such that this does not exceed 65536. */
#define TIMER_PERIOD    (TIMER_FREQUENCY / PWM_FREQUENCY - 1)
/* Product of max speed (126) and this must not exceed 4294967295 (2^32 - 1). */
#define MULTIPLIER      (TIMER_PERIOD * V_MAX_SPEED * 65 / (2 * V_DIVIDER_MAX))
/* TIM4 CH3 */
#define A_PIN      PB8
#define A_OC       TIM_OC3
/* TIM4 CH4 */
#define B_PIN      PB9
#define B_OC       TIM_OC4
/* ADC12 */
#define VTRACK_PIN PC2
#define VTRACK_CH  ADC_CHANNEL12
/* ADC13 */
#define VMOTOR_PIN PC3
#define VMOTOR_CH  ADC_CHANNEL13
/* Temperature sensor */
#define TEMP_CH    ADC_CHANNEL16
/* Internal reference voltage */
#define VREF_CH    ADC_CHANNEL17
/* VBat sensor */
#define VBAT_CH    ADC_CHANNEL18
/* ADC channel indices. */
#define VTRACK 0
#define VMOTOR 1
#define TEMP   2
#define VBAT   3
#define GROUP_LENGTH 2


bool is_stopped         = false;
uint8_t speed           = MOTOR_STOP;
uint8_t direction       = MOTOR_FORWARD;
uint8_t regular_group[] = {VTRACK_CH, TEMP_CH}; // VMOTOR_CH, VBAT_CH

volatile uint8_t current_channel = GROUP_LENGTH;
volatile uint16_t channel_readings[GROUP_LENGTH];
volatile uint32_t duty_cycle = 0;


void adc_isr(void) {
	uint16_t voltage = adc_read_regular(ADC1);

	if (channel_readings[current_channel] != voltage) {
		channel_readings[current_channel] = voltage;

		if (!is_stopped && current_channel == VTRACK) {
			/* Target speed in range [0, 126] where 0 is stop/estop & 126 is max speed. */
			uint8_t target = speed ? speed - 1 : 0;

			/* Duty cycle in range [0, TIMER_PERIOD] from target speed & track voltage. */
			duty_cycle = MULTIPLIER * target / voltage;

			char print_buffer[50];
			sprintf(print_buffer, "Duty Cycle: %ld", duty_cycle);
			println(print_buffer);
			duty_cycle = TIMER_PERIOD / 2;

			if (direction == MOTOR_FORWARD) {
				timer_set_oc_value(TIM4, A_OC, duty_cycle);
				timer_set_oc_value(TIM4, B_OC, 0);
			} else {
				timer_set_oc_value(TIM4, A_OC, 0);
				timer_set_oc_value(TIM4, B_OC, duty_cycle);
			}
		}
	}

	current_channel++;
}

static void motor_timer_setup(void) {
	/* Set motor pins to 'alternate function floating'. */
	gpio_mode_setup(PORT(A_PIN), GPIO_MODE_AF, GPIO_PUPD_NONE, PIN(A_PIN));
	gpio_mode_setup(PORT(B_PIN), GPIO_MODE_AF, GPIO_PUPD_NONE, PIN(B_PIN));

	/* Set motor pins to alternate function 2. */
	gpio_set_af(PORT(A_PIN), GPIO_AF2, PIN(A_PIN));
	gpio_set_af(PORT(B_PIN), GPIO_AF2, PIN(B_PIN));

	/* Enable TIM4 clock. */
	rcc_periph_clock_enable(RCC_TIM4);

	/* Enable TIM4 interrupt. */
	// nvic_enable_irq(NVIC_TIM4_IRQ);

	/* Reset TIM3 peripheral to defaults. */
	timer_reset(TIM4);

	/* Set timer mode: no clock divider, edge aligned, direction up. */
	timer_set_mode(TIM4, TIM_CR1_CKD_CK_INT, TIM_CR1_CMS_EDGE, TIM_CR1_DIR_UP);
	timer_set_prescaler(TIM4, (rcc_apb1_frequency / TIMER_FREQUENCY) - 1);

	/* Set output compare mode to PWM mode 1 and enable output compare. */
	timer_set_oc_mode(TIM4, A_OC, TIM_OCM_PWM1);
	timer_set_oc_mode(TIM4, B_OC, TIM_OCM_PWM1);
	timer_enable_oc_output(TIM4, A_OC);
	timer_enable_oc_output(TIM4, B_OC);

	/* Set duty cycle to zero for output channels. */
	timer_set_oc_value(TIM4, A_OC, 0);
	timer_set_oc_value(TIM4, B_OC, 0);
	timer_set_period(TIM4, TIMER_PERIOD);

	/* Enable update interrupt. */
	// timer_enable_irq(TIM4, TIM_DIER_UIE);

	/* Enable counter. */
	timer_enable_counter(TIM4);
}

static void motor_adc_setup(void) {
	/* Set VTrack pin to 'analog floating'. */
	gpio_mode_setup(PORT(VTRACK_PIN), GPIO_MODE_ANALOG, GPIO_PUPD_NONE,
		PIN(VTRACK_PIN));

	/* Enable ADC clock. */
	rcc_periph_clock_enable(RCC_ADC1);

	/* Enable ADC interrupt. */
	nvic_enable_irq(NVIC_ADC_IRQ);

	/* Set ADC clock prescaler. */
	adc_set_clk_prescale(ADC_CCR_ADCPRE_BY2);

	/* Enable scan mode. */
	adc_enable_scan_mode(ADC1);

	/* Enable continuous conversion mode. */
	adc_set_single_conversion_mode(ADC1);
	// adc_set_continuous_conversion_mode(ADC1);

	/* Set sample time for VTrack to 3 cycles. */
	adc_set_sample_time(ADC1, VTRACK_CH, ADC_SMPR_SMP_3CYC);

	/* Set independent mode. */
	adc_set_multi_mode(ADC_CCR_MULTI_INDEPENDENT);

	/* Set regular sequence. */
	adc_set_regular_sequence(ADC1, GROUP_LENGTH, regular_group);

	/* Enable temperature sensor. */
	adc_enable_temperature_sensor();

	/* Enable VBat sensor. */
	// ADC_CCR |= ADC_CCR_VBATE;
	// adc_enable_external_trigger_regular(ADC1, ADC_CR2_EXTSEL_TIM4_CC4, ADC_CR2_EXTEN_RISING_EDGE);

	/* Enable EOC (End-Of-Conversion) interrupt. */
	adc_enable_eoc_interrupt(ADC1);

	/* Enable EOC interrupt after each conversion in the sequence. */
	adc_eoc_after_each(ADC1);

	/* Enable ADC. */
	adc_power_on(ADC1);
}

void motor_setup(void) {
	motor_timer_setup();
	motor_adc_setup();
}

void motor_update(void) {
	if (current_channel == GROUP_LENGTH) {
		current_channel = 0;
		adc_start_conversion_regular(ADC1);
	}
}

void motor_stop(void) {
	if (!is_stopped) {
		is_stopped = true;

		timer_set_oc_value(TIM4, A_OC, 0);
		timer_set_oc_value(TIM4, B_OC, 0);
	}
}

/* TODO: is E-STOP equivalent to STOP? */
void motor_estop(void) {
	if (!is_stopped) {
		is_stopped = true;

		timer_set_oc_value(TIM4, A_OC, TIMER_PERIOD);
		timer_set_oc_value(TIM4, B_OC, TIMER_PERIOD);
	}
}

void motor_start(void) {
	if (is_stopped) {
		is_stopped = false;

		// while (!adc_eoc(ADC1));
		motor_update();
	}
}

void motor_set_speed(uint8_t s) {
	if (s != speed) {
		speed = s;

		if (s == MOTOR_STOP) {
			motor_stop();
		} else if (s == MOTOR_ESTOP) {
			motor_estop();
		} else {
			motor_update();
		}
	}
}

void motor_set_direction(uint8_t d) {
	if (d != direction) {
		direction = d;

		if (d == MOTOR_FORWARD) {
			timer_set_oc_value(TIM4, A_OC, duty_cycle);
			timer_set_oc_value(TIM4, B_OC, 0);
		} else {
			timer_set_oc_value(TIM4, A_OC, 0);
			timer_set_oc_value(TIM4, B_OC, duty_cycle);
		}
	}
}

uint8_t motor_get_speed(void) {
	return speed;
}

uint8_t motor_get_direction(void) {
	return direction;
}

uint16_t motor_vtrack(void) {
	return channel_readings[VTRACK] * V_DIVIDER_MAX / (4095 / 1000);
}

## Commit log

2017-02-16 Switch from 24-bit to 16-bit IDs
2017-02-16 Add 'make fuses' rule
2017-02-17 Add rails and mark IR shunt resistor as unpopulated
    [beacon.sch]
2017-02-19 Initial ARM setup using libopencm3
2017-02-19 Switch from NEC to custom IR protocol
    Uses Manchester encoding to ensure equal packet lengths and regular transitions
2017-02-22 Finalize beacon schematic
    [beacon.sch]
2017-02-22 Begin beacon board layout
2017-02-22 Add OpenSCAD model of Atlas HO Code 83 track
    Dimensions were measured with calipers, might be inaccurate
    [Atlas_HO_Code83.scad]
2017-02-26 Finalize beacon schematic for initial run
    [beacon.kicad_pcb, beacon.sch]
2017-02-28 Initial locomotive electronic design
    [control.sch, drivetrain.sch, ir_receiver.sch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]
2017-03-08 firmware: locomotive: Fix rcc clock setup for 2.8V
    [locomotive.c]
2017-03-09 firmware: locomotive: Add systick blink for STM32-H405
2017-03-10 firmware: locomotive: Capture button press with EXTI
2017-03-13 electronics: lib: Add rail and edge connector footprints
2017-03-13 electronics: beacon: WIP 3.5x28 board layout
    [beacon.kicad_pcb, beacon.sch]
2017-03-13 mechanical: Add locomotive PCB 3D model
    [Bachmann_HO_EMD_GP38-2.scad]
2017-03-15 firmware: locomotive: Implement beacon reader
    Uses Timer 3 input capture to detect edges and keep track of pulse lengths. Currently untested.
2017-03-16 firmware: locomotive: Tweak and fix some beacon code
    Still completely broken
    [beacon.c]
2017-03-17 electronics: beacon: Final beacon board Rev 1.0
    - increase board size to fit all components
    - add rail and connector footprints to library
    - improve track mechanical model
    [Atlas_HO_Code83.scad, beacon.kicad_pcb, beacon.sch]
2017-03-17 electronics: beacon: Final beacon board Rev 1.1
    - widened track solder tabs
    - improved schematic/board images
    [Atlas_HO_Code83.scad, beacon.kicad_pcb, beacon.sch]
2017-03-17 electronics: beacon: Tweak beacon board Rev 1.1
    - increase silkscreen arrow size
    - remove errant J3 silkscreen reference
    - fix PCB colors & thickness
    [beacon.kicad_pcb]
2017-03-17 electronics: lib: Add vreg, mosfets, optoisolator
    SPX3819M5-L/TR, DMG6601LVT-7, ACPL-M21L-500E
2017-03-17 electronics: locomotive: Update schematics
    Voltage regulator, TOF, IR receiver, voltage scaler, I2C control lines, power
    [control.sch, drivetrain.sch, ir_receiver.sch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]
2017-03-17 firmware: locomotive: Change voltage regulator resistor values
    [drivetrain.sch, locomotive.sch, power.sch]
2017-03-21 electronics: lib: Add Acronet KiCAD Libraries
2017-03-21 electronics: beacon: Improve schematic labeling & readability
    [beacon.kicad_pcb, beacon.sch]
2017-03-21 electronics: lib: Add TSOP572xx footprint
2017-03-21 electronics: locomotive_ir_receiver: Board Rev 1.0
    [locomotive_ir_receiver.kicad_pcb, locomotive_ir_receiver.sch]
2017-03-21 electronics: lib: Add VL6180X footprint
2017-03-21 electronics: locomotive_tof_sensor: Initial commit
    [locomotive_tof_sensor.kicad_pcb, locomotive_tof_sensor.sch]
2017-03-21 electronics: bachmann_H633Y: Initial commit
    Reverse-engineered Bachmann HO EMD GP38-2 PCB
    [bachmann_H633Y.kicad_pcb, bachmann_H633Y.sch, bachmann_H633Y_bak.kicad_pcb]
2017-03-21 mechanical: Fix locomotive PCB holes
    [Bachmann_HO_EMD_GP38-2.scad]
2017-03-22 electronics: locomotive_tof_sensor: Board Rev 1.0
    [locomotive_tof_sensor.kicad_pcb, locomotive_tof_sensor.sch]
2017-03-22 electronics: locomotive: Fix up schematics
    - add all parts and label them
    - some values still tentative
    - still need to finish connectors
    [connectors.sch, control.sch, controller.sch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]
2017-03-26 electronics: beacon: Update schematic date and image
    [beacon.sch]
2017-03-26 electronics: beacon: Add PNG schematic/board images
2017-03-31 electronics: lib: Add footprints
    - castellations
    - solder jumpers
    - bridge rectifier (TO-269AA)
    - USB Micro-B connector
2017-03-31 electronics: locomotive: Board Rev 1.0
    [connectors.sch, controller.sch, drivetrain.sch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]
2017-03-31 electronics: Clean up schematic images
2017-04-10 firmware: locomotive: Fix beacon code
    Forgot to enable RCC peripheral clock for GPIOB...
    [beacon.c]
2017-04-14 mechanical: Add rail image
2017-04-17 firmware: locomotive: Rename blink to led & generalize it
2017-04-17 firmware: locomotive: Refactor tof code
    - replace tof_should_stop() with tof_distance()
    [locomotive.c, tof.c]
2017-04-21 firmware: locomotive: Add USART serial print
2017-04-24 firmware: locomotive: Motor PWM and ADC code
2017-04-24 firmware: locomotive: Add led_toggle()
2017-04-24 firmware: locomotive: Motor, mappings, & serial code
    - parse beacon IDs and match to stored mappings
    - set motor speed/direction based upon current track voltage and target speed
    - implement a simple USART print() and println() for debugging
2017-04-24 electronics: Re-label Bachmann L+ to Io
    [bachmann_H633Y.sch]
2017-04-25 firmware: locomotive: Fix and test beacon code
    TODO: figure out how to reduce the required number of edges
    [beacon.c]
2017-04-27 electronics: locomotive: Fix mislabeled parts
    [_saved_connectors.sch, controller.sch, locomotive.kicad_pcb]
2017-04-28 electronics: beacon: Move v1.1 into subfolder
    [beacon.kicad_pcb, beacon.sch]
2017-04-28 electronics: beacon: Add v2.0 hardware
    Have yet to determine current-limiting resistor value
    [beacon.kicad_pcb, beacon.sch]
2017-05-04 electronics: beacon: Add solder jumper to v2.0
    [beacon.kicad_pcb, beacon.sch]
2017-05-04 electronics: bachmann_H633Y: Add CircuitJS simulation
2017-05-08 firmware: beacon: Add v2 firmware
    Switch from ATtiny45 to ATtiny10
2017-12-26 electronics: Rearrange folder structure
    [_saved_connectors.sch, bachmann_H633Y.kicad_pcb, bachmann_H633Y.sch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]
2017-12-26 electronics: lib: Add footprints
    - Pad_Length6mm_Width3.5mm

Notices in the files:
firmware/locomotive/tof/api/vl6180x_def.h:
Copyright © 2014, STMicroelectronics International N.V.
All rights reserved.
